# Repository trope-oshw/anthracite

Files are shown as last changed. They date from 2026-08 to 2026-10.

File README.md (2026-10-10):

# Anthracite

A MIDI-controllable analogue fuzz pedal.

Fuzz pedals are awkward to live with: the sound changes when you swap guitars, a
wah in front of one loses its range, and few switchers can drive one. Most of
that traces back to a single cause — the input impedance of a fuzz is low, and
it is fixed. Anthracite lets you choose the load your pickup sees, and keeps the
whole signal path analogue: it is switched by analogue switches rather than
mechanical contacts, and the microcontroller only moves those switches and never
touches the audio.

Designed and built by [Trope](https://trope-oshw.org) (山本回路設計).

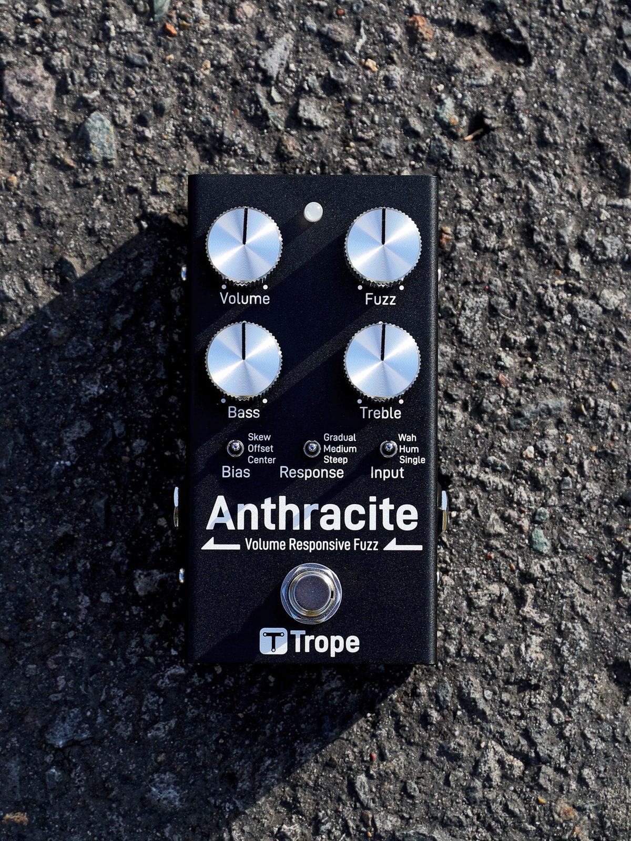
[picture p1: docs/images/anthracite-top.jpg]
Anthracite v1.0 seen from directly above: four aluminium knobs, three toggle switches and a footswitch on a matte black enclosure, with every control label legible


<table>
  <tr>
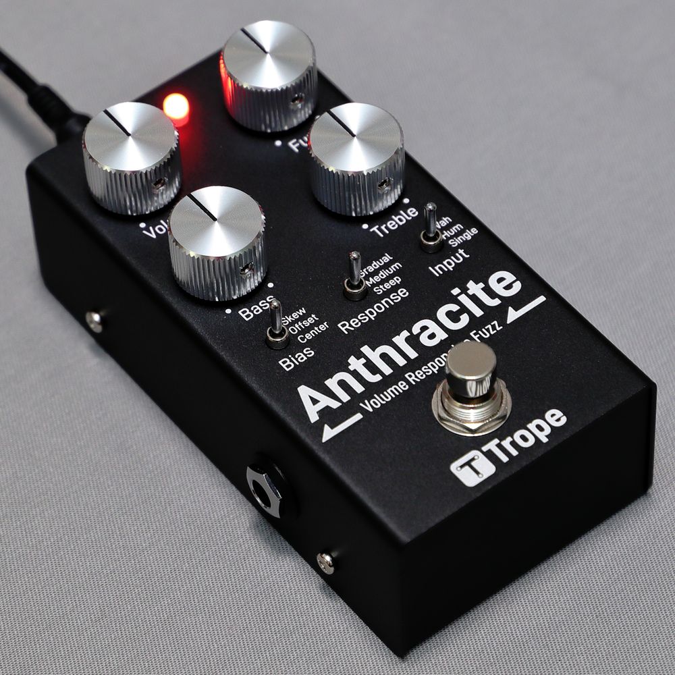
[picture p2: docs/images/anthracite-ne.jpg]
Anthracite v1.0 seen from above at an angle, with the LED lit red and a cable plugged into the top edge
    <td align="center"></td>
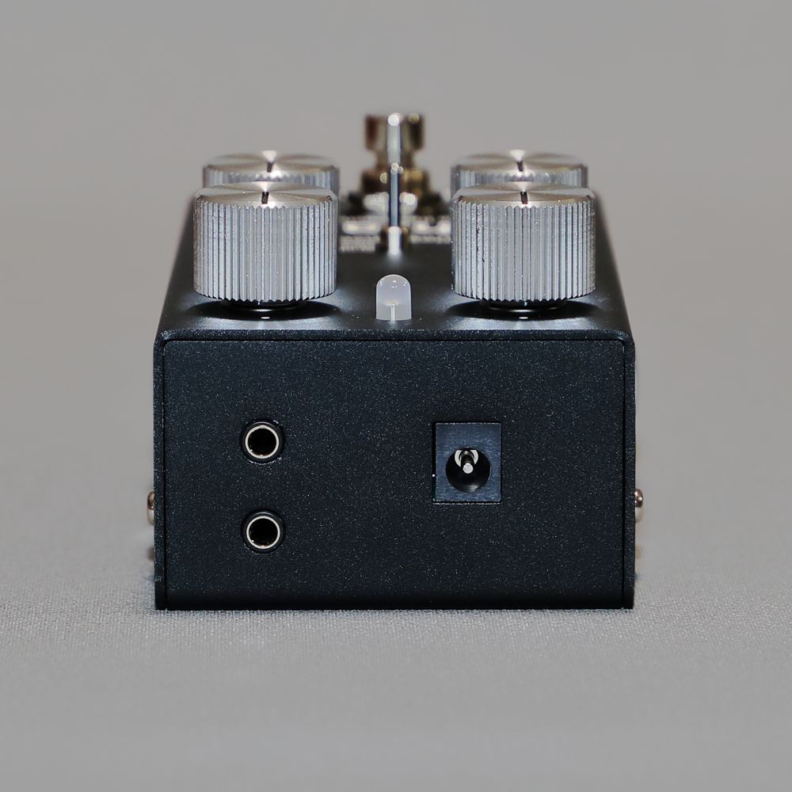
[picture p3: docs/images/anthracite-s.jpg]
The top edge of Anthracite v1.0: two 3.5 mm TRS MIDI jacks on the left and the 9 V DC barrel jack on the right
    <td align="center"></td>
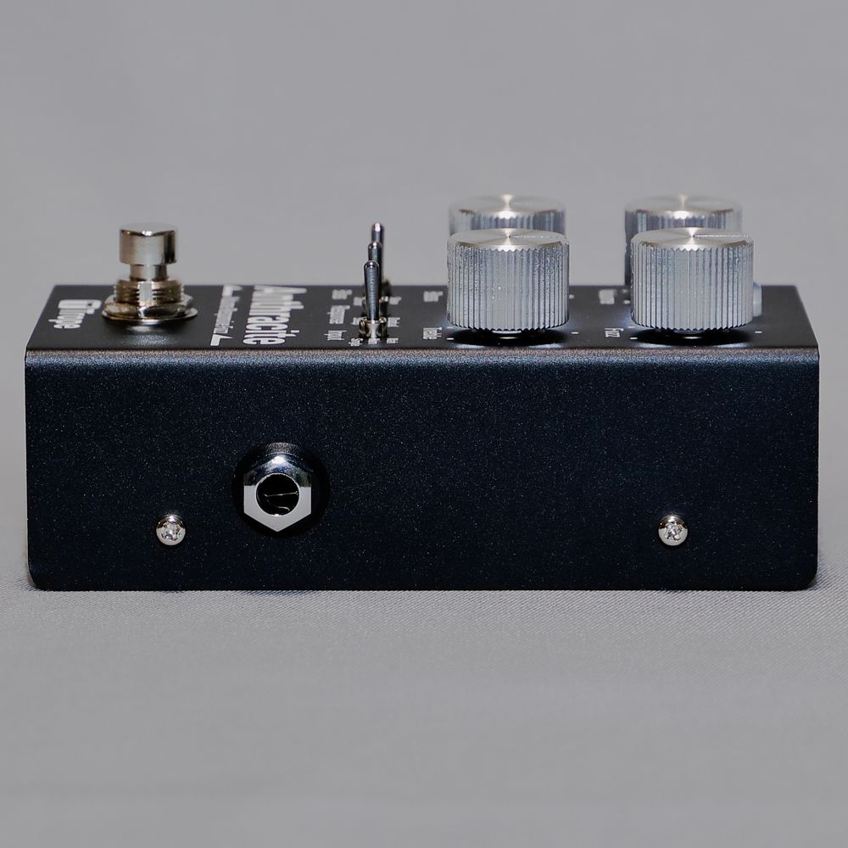
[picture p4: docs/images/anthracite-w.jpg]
The input side of Anthracite v1.0, with the 1/4 inch input jack
    <td align="center"></td>
  </tr>
  <tr>
    <td align="center">Angled view, LED lit</td>
    <td align="center">Top edge: MIDI IN / OUT (3.5 mm TRS) and 9 V DC</td>
    <td align="center">Input side: 1/4" jack</td>
  </tr>
</table>

## Specifications

| | |
|---|---|
| Power | 9 V DC, centre-negative, 5.5 / 2.1 mm barrel. No battery compartment |
| Operating voltage | 8.4 – 11.5 V |
| Recommended operating voltage | 8.6 – 10.0 V |
| Current draw | About **70 mA** at 9 V with the effect on (measured 67 – 74 mA depending on settings; about 4 mA less in bypass) |
| Adapter rating | 200 mA or more |
| Input impedance | About **13 kΩ** (Single) / **24 kΩ** (Hum) / **44 kΩ** (Wah) at 1 kHz, effect on |
| Input impedance, bypassed | About **1 MΩ** from 100 Hz to 1 kHz, measured |
| Output impedance | About **1 kΩ** at 1 kHz |
| Bypass | Buffered. Switched electronically — no mechanical contacts in the audio path |
| MIDI | 3.5 mm TRS, MIDI Type-A, 31250 baud. MIDI IN, and a MIDI OUT (Thru) jack that doubles as an external-switch input |
| Microcontroller | STM32F030C8T6 (Cortex-M0, 48 MHz, LQFP48) |
| Enclosure | 73.5 (W) × 57.5 (H) × 128 (D) mm including knobs and jacks, 268 g |

The pedal monitors its supply and flashes the LED if the voltage drops below
about 8 V or rises above about 12 V. The exact trip points vary slightly from
unit to unit, but the warning does not appear inside the operating voltage
range. Do not run the pedal outside that range even if no warning is shown.

The effect-on input impedance figures come from a SPICE model of the input
circuit and agree with measurements on a v1.0 unit. The impedance stays roughly
flat at low frequencies (about 24 / 34 / 55 kΩ at 20 Hz) and falls gradually
towards high frequencies. That roll-off is deliberate: a heavier load pulls the
pickup's resonant peak lower, and the Input switch selects between three loads.

### Boards

| Board | Size | Layers | Copper |
|---|---|---|---|
| Top (analogue) | 60 × 102 mm | 4 | 35 µm (1 oz) outer, 17.5 µm (0.5 oz) inner |
| Bottom (control) | 60 × 73.5 mm | 4 | 35 µm (1 oz) outer, 17.5 µm (0.5 oz) inner |
| Footswitch | 14 × 16.15 mm | 2 | — |

All boards are 1.6 mm FR-4.

## Controls

Four potentiometers and three three-position toggles.

| Control | Range |
|---|---|
| **Volume** | 50 kΩ, log (A taper) |
| **Fuzz** | 10 kΩ, reverse log (C taper), wired as a variable resistor. Roughly 39 dB to 65 dB of small-signal gain in the fuzz stage |
| **Bass** | 20 kΩ, linear (B taper). Low shelf: up to about −25 dB of cut and +13 dB of boost at 20 Hz. The half-way point moves between about 170 Hz and 390 Hz with the knob |
| **Treble** | 20 kΩ, linear (B taper). High shelf: up to about −26 dB of cut and +14 dB of boost at 10 kHz. The half-way point moves between about 700 Hz and 1.7 kHz, so it also acts on the midrange around 1 kHz |

Toggle positions are listed from top to bottom.

| Toggle | Positions | What it changes |
|---|---|---|
| **Bias** | Skew / Offset / Center | Operating point of the output-side fuzz transistor (3:1, 2:1, 1:1). More asymmetry means more even-order harmonics and less gain. Second harmonic moves from −16.7 dBc (Center) to −9.5 dBc (Skew) at 400 Hz / 0.1 Vpp, Fuzz 50 %. With DIP-SW2 on, the toggle selects X-Skew (4:1) / Skew / Offset instead |
| **Response** | Gradual / Medium / Steep | Series resistance at the fuzz input, which sets how abruptly the pedal cleans up as you roll back the guitar volume. THD at 400 Hz / 1 Vpp, Fuzz 50 %: 65.6 % / 59.7 % / 49.3 % |
| **Input** | Wah / Hum / Single | Input filter, which sets the loading your pickup sees (see the impedance figures above) |

## MIDI

The pedal receives; it never sends control messages of its own. MIDI IN is
active whichever way DIP-SW3 (MIDI mode / external-switch mode) is set.

| CC | Function | Values |
|---|---|---|
| **81** | Bypass / engage (channel 12, with DIP-SW4 off as shipped) | ≥ 64 engages, < 64 bypasses |
| **83** | Input | 0 = return to the physical toggle · 1–31 Single · 32–63 Hum · 64–95 Wah · 96–127 All-OFF (input filter disconnected) |
| **84** | Response | 0 = return to the toggle · 1–31 Steep · 32–63 Medium · 64–95 Gradual · 96–127 no change |
| **85** | Bias | 0 = return to the toggle · 1–31 Center · 32–63 Offset · 64–95 Skew · 96–127 X-Skew |

CC 83/84/85 are received on the same channel as the bypass / engage message.
Sending 0 to any of them hands control back to the physical toggle, so a MIDI
override never becomes something you cannot undo from the panel.

**MIDI-Learn** stores a channel and CC number for the bypass function in EEPROM;
with DIP-SW4 on, the pedal uses them instead of channel 12 / CC 81. Units ship
with **channel 6 / CC 1** already stored. Many MIDI foot controllers send their
expression pedal on CC 1, so with DIP-SW4 on, an expression pedal on channel 6
will switch the effect as it crosses value 64; learn a different CC or change
the controller's CC. If nothing is stored, DIP-SW4 on disables MIDI control
entirely rather than falling back to channel 12 / CC 81. Do not learn CC 83, 84
or 85. **Active Sensing** (0xFE) is emitted about every 250 ms, and received
messages are passed through to MIDI OUT unmodified, both only in MIDI mode
(DIP-SW3 on, as shipped). With DIP-SW3 off, the MIDI OUT jack becomes an
external footswitch input.

## What is in this repository

```
hardware/     KiCad projects for the three circuit boards (top, bottom and
              footswitch) and the front-panel artwork, with the symbol and
              footprint libraries they use; parts list (parts.md)
enclosure/    Enclosure 3D model (STEP), hole-layout and assembly drawings
              (PDF), front-panel artwork for laser marking (DXF, SVG, PNG)
firmware/     STM32 firmware source: STM32CubeMX project, CMake build, the
              ST HAL and CMSIS, and the build and flashing guide
docs/         Schematics (PDF, plus a PNG of each sheet), bills of materials
              (CSV), 3D models of the assembled boards (STEP), product photos
```

The STEP model and the drawings (PDF, DXF) are the reference for the
enclosure.

Gerbers and the ordering notes are attached to each
[release](https://github.com/trope-oshw/anthracite/releases) rather than kept in
the tree, so that what you download always matches a specific version. There is
no assembler-specific BOM or pick-and-place file: build them from `docs/bom-*.csv`
and the KiCad projects for whoever assembles your boards.

The user manual, measured data, and circuit explanations live at
**https://docs.trope-oshw.org** — they are not duplicated here.

## Building the boards

The KiCad projects need KiCad 10 or later. They are self-contained: every
custom symbol and footprint is in the project's own `libs/` directory, so you
can clone this repository and open them without installing anything else.

[`hardware/parts.md`](hardware/parts.md) lists the parts chosen for each board,
with manufacturer part numbers and LCSC numbers.

Ordering parameters used for the production run are recorded in
`ordering-notes.md` attached to each release. They matter, because a different
stackup or copper weight gives a different board.

## Firmware

The full source is in [`firmware/`](firmware/). Built as described in
[firmware/README.md](firmware/README.md), it reproduces the image on shipped
units byte for byte; that file gives the toolchain versions, the SHA-256 of the
image, and how to write it to a finished unit. You do not need to touch the
firmware to use the pedal; the instructions are there because being able to
replace the software on hardware you own is part of what this licence is for.

## Licensing

| What | Licence |
|---|---|
| Hardware (`hardware/`, `enclosure/`) | **CERN-OHL-S-2.0** |
| Firmware (`firmware/`), except the third-party code below | **GPL-3.0-or-later** |
| Generated design documents (`docs/`: schematics, bills of materials, board 3D) | **CERN-OHL-S-2.0** |
| Product photographs (`docs/images/`) | **CC-BY-SA-4.0** |
| Text (this README, CHANGELOG, ERRATA, CONTRIBUTING) | **CC-BY-SA-4.0** |

Full texts are in [`LICENSES/`](LICENSES/); per-file assignments are declared in
[`REUSE.toml`](REUSE.toml) following the [REUSE](https://reuse.software/)
specification. See [`COPYRIGHT.txt`](COPYRIGHT.txt) for the notices.

Parts of the firmware come from STMicroelectronics and Arm and keep their own
licences: the STM32F0 HAL driver and the code generated by STM32CubeMX are
BSD-3-Clause, and the CMSIS headers and ST's CMSIS device files are Apache-2.0.
Likewise, some footprints in `hardware/*/libs/` are derived from the KiCad
standard libraries and stay under CC-BY-SA-4.0 with the KiCad libraries
exception. The symbol libraries mix symbols derived the same way with symbols
drawn for this project, so both licences apply to them; `REUSE.toml` lists the
files.

## Trademark

The design files in this repository are open source under the licences above.
**The Trope and 山本回路設計 brand names, the Trope logo, and the product name
"Anthracite" are not.** They are trademarks of 山本回路設計 and are not licensed
to you by any of the licences here. See also section 8.2 of the CERN-OHL-S v2.

You are free to build, modify, and sell hardware derived from these files. When
you do, please give it your own name and your own branding. A modified version
could be called "Foobar Audio — Charcoal Fuzz"; it should not be called
"Anthracite" or "Trope Anthracite".

You may state truthfully that your product is *based on the Anthracite design by
Trope*. You may not use the Trope logo, or a name so close to Trope or Anthracite
that a buyer could confuse the two.

**All Trope branding has been removed from the published files**, both the
panel artwork and the circuit-board silkscreen, so hardware made from these
files carries no Trope marks by default. Please keep it that way. Instead of a
product name, the top and bottom boards carry the board version (`V1.0`), the
licence (CERN-OHL-S-2.0) and where the source lives
(`github.com/trope-oshw/anthracite`).

Boards from the first production run carry `Anthracite V1.0` on the silkscreen
instead. That text is the only difference: electrically they are the same as the
published boards. Units built by Trope after that run use the published board
files as they are.

Questions, or a request to use the marks: trope.oshw@gmail.com — ask first and
the answer is almost always yes.

## Versions

The product and the boards carry a `vMAJOR.MINOR` number, silkscreened on the
PCB. The firmware carries its own semantic version. They move independently:
fixing a firmware bug does not change the boards, so the board version stays put.

See [CHANGELOG.md](CHANGELOG.md) for what changed in each release, and
[ERRATA.md](ERRATA.md) for problems found in hardware that has already been
built. **If your unit behaves differently from this documentation, check the
errata first.**

## Buying one

Anthracite is on sale. Trope builds and tests each unit and ships it with its
own test report. The product page at **https://trope-oshw.org/anthracite/**
shows the current price and takes orders. Trope plans to publish the cost
breakdown and the formula behind the price at **https://docs.trope-oshw.org**.
Questions go to trope.oshw@gmail.com.

Buying one is what pays for the next design being opened.

## Contributing

Issues are welcome; pull requests to the hardware are not, for reasons explained
in [CONTRIBUTING.md](CONTRIBUTING.md). Firmware and documentation PRs are
welcome.

## Disclaimer

This design is distributed **as-is, with no warranty of any kind**, express or
implied, including merchantability and fitness for a particular purpose. See
sections 6.1 and 6.2 of the CERN-OHL-S v2 for the full disclaimer.

If you build, modify, or sell hardware based on these files, **you are the
manufacturer** of that hardware. You alone are responsible for its safety and
for its compliance with every regulation that applies where you place it on the
market. Any certification, testing, or conformity marking obtained by
山本回路設計 applies **only to units built and sold by 山本回路設計**, and does
not transfer to your build.

Use a regulated, correctly-polarised 9 V DC supply. Incorrect power can damage
the pedal and whatever is connected to it.

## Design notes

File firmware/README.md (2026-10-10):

# Anthracite firmware

Firmware for the STM32F030C8T6 on the control board. It reads the panel
toggles, the footswitch and MIDI, and drives the analogue switches and the
LEDs. The audio signal never passes through the microcontroller.

This tree is firmware 1.0.0, the version on shipped v1.0 units.

## Why these instructions exist

This firmware is licensed under **GPL-3.0-or-later**. That licence asks that if
you receive a device with GPL software on it, you are able to replace that
software with your own modified version. Trope documents the procedure here
and leaves the SWD header on shipped units accessible and unlocked.

You do not need any of this to use the pedal.

## What is here

| Path | Contents |
|---|---|
| `Src/main.c`, `Src/stm32f0xx_it.c`, `Inc/main.h` | The application, written inside the STM32CubeMX skeleton |
| `Src/`, `Inc/` (other files) | Startup support, HAL configuration and MSP code generated by STM32CubeMX |
| `Drivers/` | STM32F0 HAL driver and CMSIS headers from STM32Cube FW_F0 V1.11.6 |
| `anthracite.ioc` | STM32CubeMX project: pin assignment, clocks, peripherals |
| `CMakeLists.txt`, `CMakePresets.json`, `cmake/` | CMake build generated by STM32CubeMX |
| `STM32F030XX_FLASH.ld`, `startup_stm32f030x8.s` | Linker script and startup code |

The presets use `cmake/gcc-arm-none-eabi.cmake`. STM32CubeMX also generated
`cmake/starm-clang.cmake`; the build does not use it.

## What you need

| | |
|---|---|
| Probe | ST-LINK/V3 (V3MINIE or similar) with SWD |
| Build | CMake 3.22 or later, Ninja, the GNU Arm toolchain (`arm-none-eabi-gcc`) |
| Flashing | `STM32_Programmer_CLI` (or OpenOCD) |

STM32CubeIDE ships CMake, Ninja, the GNU toolchain and `STM32_Programmer_CLI`
in `STM32CubeIDE/plugins/com.st.stm32cube.ide.mcu.externaltools.*/tools/bin`.
With those directories on `PATH`, you have every tool the build and flashing
steps use.

## Building

Run these commands in the `firmware/` directory, where `CMakePresets.json` is:

```sh
cmake --preset Debug
cmake --build --preset Debug
```

The ELF is `build/Debug/anthracite.elf`.

Use the presets. A hand-written `cmake -S . -B build -G Ninja …` command omits
`-DCMAKE_TOOLCHAIN_FILE`, and the configure step fails.

On Windows, CMake warns when object file paths approach 250 characters. Clone
the repository to a short path if you see that warning.

## Reproducing the shipped image

Shipped units carry the `Debug` build (`-O0 -g3`) of this source. Built with
the tools below, the `Debug` preset reproduces that image byte for byte:

| Tool | Version |
|---|---|
| GNU toolchain | GNU Tools for STM32 14.3.rel1.20251027-0700 (GCC 14.3.1), bundled with STM32CubeIDE 2.1.0 |
| CMake | 3.28.1 |
| Ninja | 1.11.1 |

```sh
arm-none-eabi-objcopy -O binary build/Debug/anthracite.elf anthracite.bin
sha256sum anthracite.bin        # Linux, Git Bash
shasum -a 256 anthracite.bin    # macOS
```

In PowerShell, `Get-FileHash -Algorithm SHA256 anthracite.bin` prints the same
hash in upper case.

The flash image is 42,516 bytes, loaded at `0x08000000`, with SHA-256

```
b7581d1ae76084e6236442fdeab6e39d7fa7e3c6bd3c1cf8cb9a229a08162016
```

Compare the `.bin`. The ELF also holds debug information with line
numbers and file paths, so it changes when comments move or the tree sits in a
different directory, while the flash image stays the same. A different
compiler version can produce a different image.

`CMakePresets.json` also defines a `Release` preset (`-Os -g0`). It produces a
different image from the one on shipped units.

## Flashing

The SWD header is **J101**, a 14-pin STDC14 connector (2×7, 1.27 mm pitch) on
the control board. Pins 3/4/5/6/12 carry 3V3, SWDIO, GND, SWCLK and NRST; pins
13/14 are a serial console.

```sh
# Check the probe sees the target
STM32_Programmer_CLI -c port=SWD

# Write, verify, reset
STM32_Programmer_CLI -c port=SWD freq=4000 -w build/Debug/anthracite.elf -v -rst
```

The ELF carries its load address, so no address argument is needed. With OpenOCD:

```sh
openocd -f interface/stlink.cfg -f target/stm32f0x.cfg \
        -c "program build/Debug/anthracite.elf verify reset exit"
```

Trope programmed shipped units with STM32_Programmer_CLI 2.22.0.

If `STM32_Programmer_CLI` reports no ST-LINK, close any CubeIDE debug session
first: it holds the ST-LINK open. With more than one probe attached, select one
with `sn=<serial>`.

## Licences

| Files | Licence |
|---|---|
| `Src/main.c`, `Src/stm32f0xx_it.c`, `Inc/main.h` | GPL-3.0-or-later. The parts STM32CubeMX generated stay BSD-3-Clause (STMicroelectronics) |
| `anthracite.ioc` | GPL-3.0-or-later |
| `Drivers/STM32F0xx_HAL_Driver/` | BSD-3-Clause (STMicroelectronics) |
| Other files generated by STM32CubeMX: `Src/stm32f0xx_hal_msp.c`, `Src/syscalls.c`, `Src/sysmem.c`, `Inc/stm32f0xx_hal_conf.h`, `Inc/stm32f0xx_it.h`, `STM32F030XX_FLASH.ld`, `CMakeLists.txt`, `CMakePresets.json`, `cmake/`, `.mxproject` | BSD-3-Clause (STMicroelectronics) |
| `Drivers/CMSIS/Device/`, `Src/system_stm32f0xx.c`, `startup_stm32f030x8.s` | Apache-2.0 (STMicroelectronics) |
| `Drivers/CMSIS/Include/` | Apache-2.0 (Arm; `cmsis_iccarm.h` by IAR Systems) |

Most of the third-party files carry no SPDX header. The repository's
`REUSE.toml` declares their licences, and the texts are in `LICENSES/`.

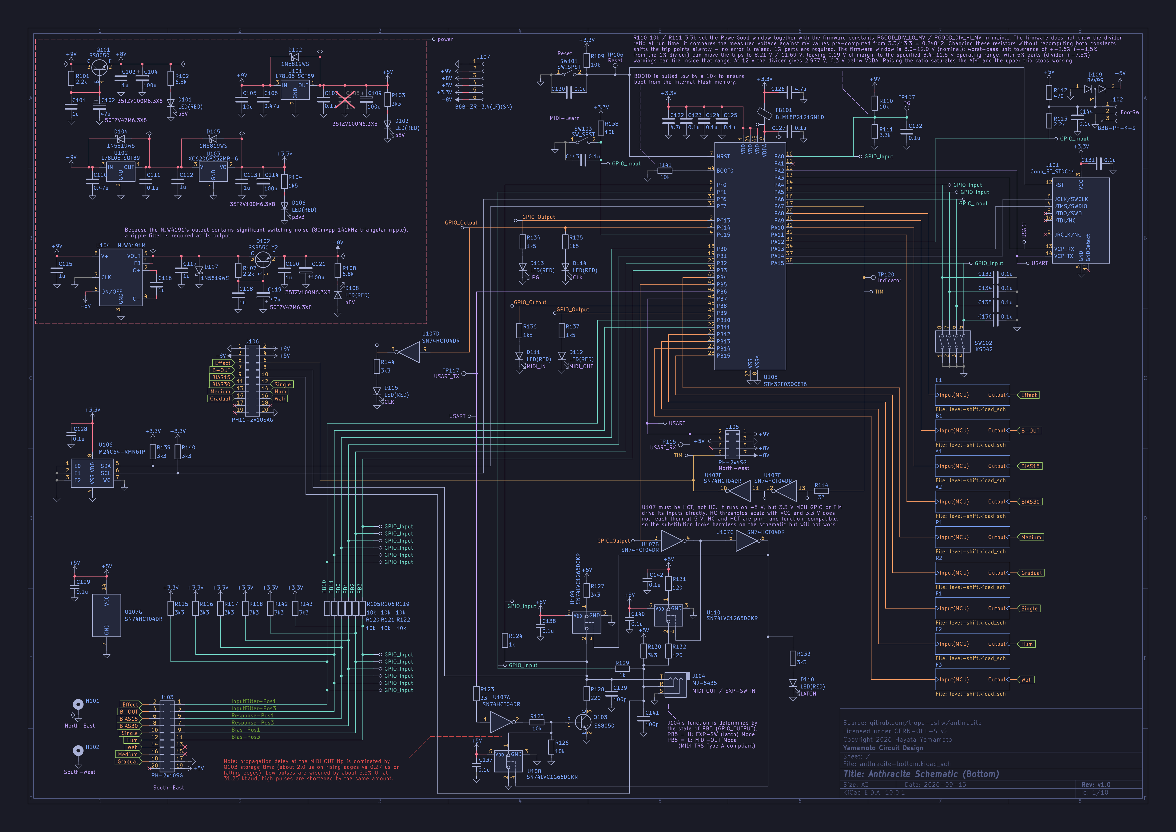
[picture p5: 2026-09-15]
docs/schematics/anthracite-bottom.png

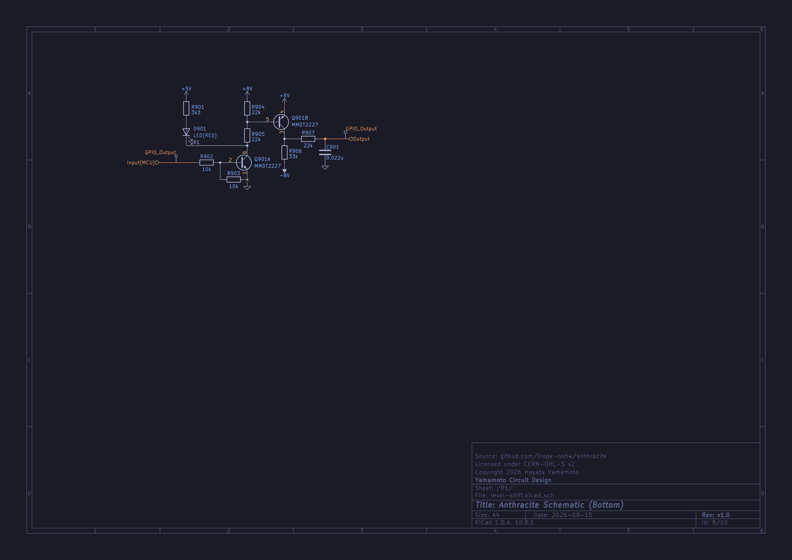
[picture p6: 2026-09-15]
docs/schematics/anthracite-bottom-R1.png

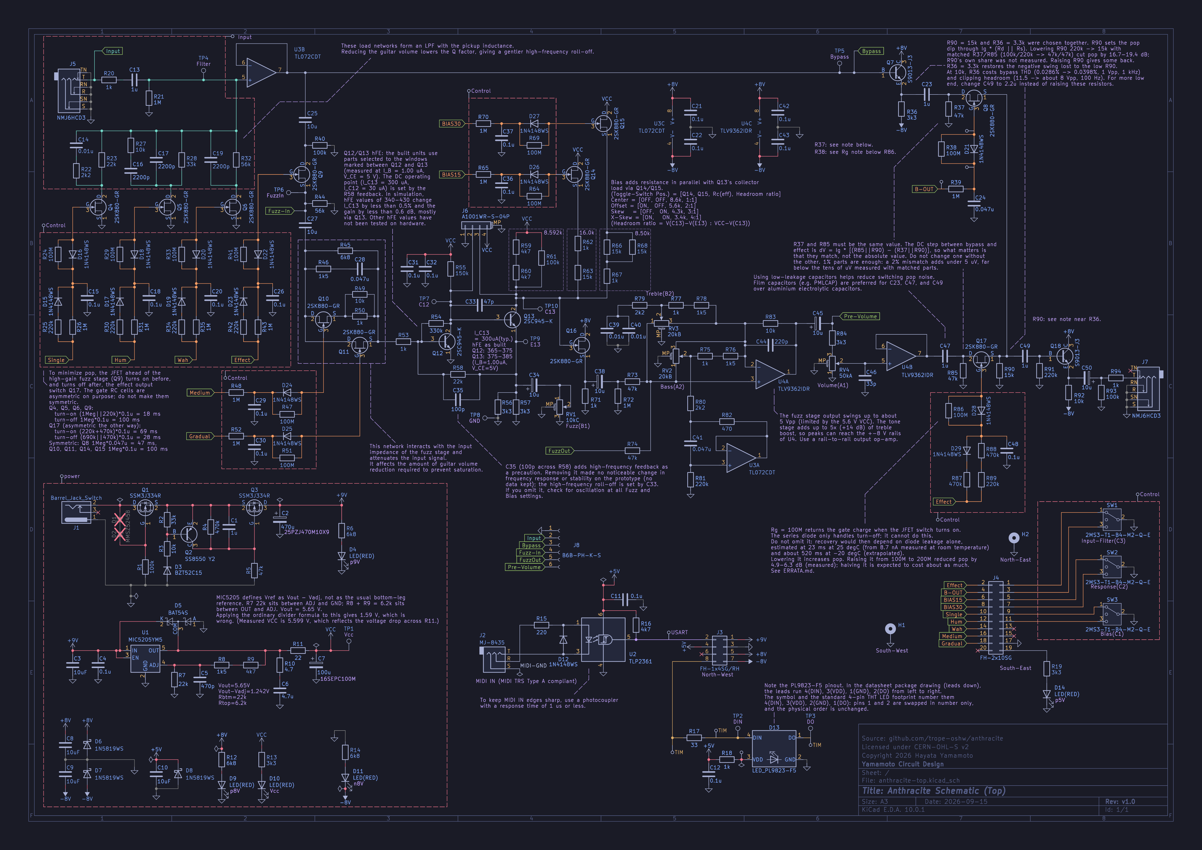
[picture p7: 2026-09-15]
docs/schematics/anthracite-top.png

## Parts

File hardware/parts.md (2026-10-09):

# Parts

The parts chosen for Anthracite v1.0, collected from the bills of materials in
`docs/`. Positions, quantities and the full field list for each board are in
`docs/bom-top.csv`, `docs/bom-bottom.csv`, `docs/bom-footswitch.csv` and
`docs/bom-mechanical.csv`. KiCad exports the board BOMs from the projects;
Trope wrote this file by hand from them. If the two disagree, follow the BOM.

**Fit:** on the first production run the board house assembled the `SMT` parts
(`PCBA` in the BOM) and Trope hand-soldered the `Hand` parts. `DNP` parts stay
off the board.

**LCSC** numbers are the ones in the BOMs. Stock and catalogue numbers change,
so check them before ordering; the manufacturer and MPN are there to choose an
equivalent part.

## Parts with a manufacturer part number

### Integrated circuits

| Value | Manufacturer | MPN | LCSC | Rating | Fit | Used on |
|---|---|---|---|---|---|---|
| MIC5205YM5 | Microchip | MIC5205YM5 | C412820 |  | SMT | Top: U1 |
| TL072CDT | STMicro | TL072CDT | C6961 |  | SMT | Top: U3 |
| TLP2361 | Toshiba | TLP2361 | C107626 |  | Hand | Top: U2 |
| TLV9362IDR | TI | TLV9362IDR | C4367884 |  | Hand | Top: U4 |
| L78L05_SOT89 | UTC | 78L05G-AB3-R | C71136 |  | SMT | Bottom: U101, U102 |
| XC6206P332MR-G | Torex | XC6206P332MR-G | C5446 |  | SMT | Bottom: U103 |
| STM32F030C8T6 | STMicro | STM32F030C8T6 | C23922 |  | SMT | Bottom: U105 |
| M24C64-RMN6TP | STMicro | M24C64-RMN6TP | C79988 |  | SMT | Bottom: U106 |
| SN74HCT04DR | TI | SN74HCT04DR | C6766 |  | SMT | Bottom: U107 |
| SN74LVC1G66DCKR | TI | SN74LVC1G66DCKR | C113518 |  | SMT | Bottom: U108, U109, U110 |
| NJW4191M | Nisshinbo | NJW4191M |  |  | Hand | Bottom: U104 |

### Transistors

| Value | Manufacturer | MPN | LCSC | Rating | Fit | Used on |
|---|---|---|---|---|---|---|
| SS8550 Y2 | JSCJ | SS8550 Y2(RANGE:200-350) | C8542 |  | SMT | Top: Q2; Bottom: Q102 |
| 2SK880-GR | Toshiba | 2SK880-GR | C7469759 |  | SMT | Top: Q4, Q5, Q6, Q8, Q9, Q10, Q11, Q14, Q15, Q16, Q17 |
| S9013-J3 | JSCJ | S9013 J3(RANGE:200-350) | C6749 |  | SMT | Top: Q7, Q18 |
| SSM3J334R | Toshiba | SSM3J334R | C396017 |  | Hand | Top: Q1, Q3 |
| 2SC945-K | UTC | 2SC945-K |  |  | Hand | Top: Q12, Q13 |
| SS8050 | JSCJ | SS8050(RANGE:200-350) | C2150 |  | SMT | Bottom: Q101, Q103 |
| MMDT2227 | R+O | MMDT2227 | C41375117 |  | SMT | Bottom: Q201, Q301, Q401, Q501, Q601, Q701, Q801, Q901, Q1001 |

### Diodes and LEDs

| Value | Manufacturer | MPN | LCSC | Rating | Fit | Used on |
|---|---|---|---|---|---|---|
| BZT52C15 | R+O | BZT52C15 | C19077412 |  | SMT | Top: D3 |
| LED(RED) | Hubei KENTO Elec | KT-0603R | C2286 |  | SMT | Top: D4, D9, D10, D11, D14; Bottom: D101, D103, D106, D108, D110, D111, D112, D113, D114, D115, D201, D301, D401, D501, D601, D701, D801, D901, D1001 |
| BAT54S | R+O | BAT54S | C7420333 |  | SMT | Top: D5 |
| 1N5819WS | Guangdong Hottech | 1N5819WS | C191023 |  | SMT | Top: D6, D7, D8; Bottom: D102, D104, D105, D107 |
| 1N4148WS | JSCJ | 1N4148WS | C2128 |  | SMT | Top: D12, D15, D16, D17, D18, D19, D20, D21, D22, D23, D24, D25, D26, D27, D28, D29 |
| LED_PL9823-F5 | Shenzhen Rita Lighting | PL9823-F5 |  |  | Hand | Top: D13 |
| MMSZ5245B | R+O | MMSZ5245B | C19077428 |  | DNP | Top: D1, D2 |
| BAV99 | Nexperia | BAV99,215 | C2500 |  | SMT | Bottom: D109 |

### Capacitors with a specified part

| Value | Manufacturer | MPN | LCSC | Rating | Fit | Used on |
|---|---|---|---|---|---|---|
| 1u | Samsung Electro-Mechanics | CL21B105KBFNNNE | C28323 | 10% 50V X7R | SMT | Top: C1; Bottom: C101, C103, C112, C113, C115, C116, C117, C118, C120 |
| 10uF | Samsung Electro-Mechanics | CL21A106KAYNNNE | C15850 | 10% 25V X5R | SMT | Top: C3, C8, C9, C10 |
| 0.01u | Murata | GRM1885C1H103JA01D | C85973 | 5% 50V C0G | SMT | Top: C14, C39, C40 |
| 10u | Panasonic | EEE1CA100SR | C178496 | 20% 16V electrolytic | SMT | Top: C34, C38, C45, C50 |
| 470u | Rubycon | 25PZJ470M10X9 |  | 20% 25V Polymer electrolytic | Hand | Top: C2 |
| 100u | Panasonic | 16SEPC100M |  | 20% 16V Polymer electrolytic | Hand | Top: C7 |
| 1u | Rubycon | 25NS105MA23216 |  | 20% 25V film | Hand | Top: C13, C23, C47, C49 |
| 10u | Rubycon | 16MU106MC44532 |  | 20% 16V film | Hand | Top: C25, C27 |
| 0.047u | Murata | GRM31M5C1H473JA01L | C21812 | 5% 50V C0G | Hand | Top: C28, C41 |
| 47u | Rubycon | 50TZV47M6.3X8 | C88734 | 20% 50V electrolytic | SMT | Bottom: C102, C119 |
| 100u | Rubycon | 35TZV100M6.3X8 | C88744 | 20% 35V electrolytic | SMT | Bottom: C104, C109, C114, C121 |
| 10u | Murata | GRM21BR61H106KE43L | C440198 | 10% 50V X5R | DNP | Bottom: C108 |

### Connectors

| Value | Manufacturer | MPN | LCSC | Rating | Fit | Used on |
|---|---|---|---|---|---|---|
| Barrel_Jack_Switch | Maru-Shin | MJ-179PH |  |  | Hand | Top: J1 |
| MJ-8435 | Maru-Shin | MJ-8435 |  |  | Hand | Top: J2; Bottom: J104 |
| FH-1x4SG/RH | Chang Enn | FH-1x4SG/RH x2 |  |  | Hand | Top: J3 |
| FH-2x10SG | Chang Enn | FH-2x10SG |  |  | Hand | Top: J4 |
| NMJ6HCD3 | Neutrik | NMJ6HCD3 |  |  | Hand | Top: J5, J7 |
| A1001WR-S-04P | Herwell | A1001WR-S-04P |  |  | Hand | Top: J6 |
| B6B-PH-K-S | JST | B6B-PH-K-S(LF)(SN) |  |  | Hand | Top: J8 |
| Conn_ST_STDC14 | hanxia | HX JN1.27-2x7P ZZ H4.9 |  |  | Hand | Bottom: J101 |
| B3B-PH-K-S | JST | B3B-PH-K-S(LF)(SN) |  |  | Hand | Bottom: J102 |
| PH-2x10SG | Useconn | PH-2x10SG |  |  | Hand | Bottom: J103 |
| PH-2x4SG | Chang Enn | PH-2x4SG |  |  | Hand | Bottom: J105 |
| PH11-2x10SAG | Chang Enn | PH11-2x10SAG |  |  | Hand | Bottom: J106 |
| B6B-ZR-3.4(LF)(SN) | JST | B6B-ZR-3.4(LF)(SN) |  |  | Hand | Bottom: J107 |
| Conn_01x03_Socket | JST | B3B-PH-K-S(LF)(SN) |  |  | Hand | Footswitch: J1 |

### Switches and potentiometers

| Value | Manufacturer | MPN | LCSC | Rating | Fit | Used on |
|---|---|---|---|---|---|---|
| 10kC | Alpha | RD901F-40-15R1-C10K |  |  | Hand | Top: RV1 |
| 20kB | Alpha | RD901F-40-15R1-B20K |  |  | Hand | Top: RV2, RV3 |
| 50kA | Alpha | RD901F-40-15R1-A50K |  |  | Hand | Top: RV4 |
| 2MS3-T1-B4-M2-Q-E | Cosland | 2MS3-T1-B4-M2-Q-E |  |  | Hand | Top: SW1, SW2, SW3 |
| SW_SPST | XUNPU | TS-1088-AR02016 | C720477 |  | SMT | Bottom: SW101, SW103 |
| KSD42 | OTAX | KSD42 |  |  | Hand | Bottom: SW102 |
| SW_DPDT_x2 | Alpha | See note 2 |  |  | Hand | Footswitch: SW1 |

## Generic resistors and capacitors

The remaining resistors and ceramic capacitors are generic chip parts, listed
in the BOMs by value, package, tolerance, voltage, dielectric and LCSC number:

- Resistors: 1 % chip resistors, 0603 on the top board and 0402 or
  0603 on the bottom board. The 100 MΩ resistors on the top board (R24, R29,
  R33, R38, R41, R47, R51, R64, R69, R86) are 5 %.
- Ceramic capacitors: X7R, X5R or C0G, 0603 or 0805, as given in the BOMs.
- FB101 on the bottom board is a BLM18PG121SN1D ferrite bead (LCSC C14709).

## Notes

1. **D1, D2** (top) and **C108** (bottom) are not fitted.
2. **Footswitch SW1:** any momentary footswitch works; both poles are wired in
   parallel. Trope's units use an Alpha momentary DPDT footswitch (for
   example Sakuraya Denkiten fs85_i-5).
3. **J3** (top) is made of two FH-1x4SG/RH single-row sockets.
4. **R38 and R86** are 100 MΩ. [ERRATA.md](../ERRATA.md), entry M-1, describes
   raising both to 200 MΩ to reduce the switching pop.
5. **Footswitch cable** (bottom J102 to footswitch J1): a 3-pin, 2.0 mm pitch
   cable, JST PH compatible, 150 mm. The intended part is a made-to-order
   JST PH cable; the first production run used Akizuki Denshi 111659
   (Herwell GP2A-2-B) instead.

## Mechanical parts

From `docs/bom-mechanical.csv`, which also gives supplier part numbers and
links.

| Item | Qty | Part |
|---|---|---|
| Enclosure, top shell | 1 | Sheet-metal U-shell, aluminium 5052, 1.5 mm, anodized black glossy, laser-marked top face. Made to order from `enclosure/` |
| Enclosure, bottom shell | 1 | Sheet-metal U-shell with 4 tapped tabs (M3×0.5 burring), aluminium 5052, 1.5 mm, anodized black glossy. Made to order from `enclosure/` |
| Enclosure screw | 4 | Pan head machine screw, M3×5, brass |
| PCB spacer | 2 | Hex spacer, female-female, M3×0.5, 11 mm, 5.5 mm across flats, brass (M.Y.G FB3-11) |
| PCB spacer screw | 4 | Pan head machine screw, M3×5, brass (same as the enclosure screws) |
| Knob | 4 | Aluminium knob, Davies 1510 style, silver, 19 mm dia., 6.35 mm round shaft hole, set screw |
| Footswitch cable | 1 | See note 5 |

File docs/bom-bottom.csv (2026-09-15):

Assembly | References | Qty | Value | Footprint | Description | Tolerance | Voltage | Dielectric | Power | Manufacturer | MPN | LCSC | Datasheet
PCBA | C101, C103, C112, C113, C115, C116, C117, C118, C120 | 9 | 1u | C_0805_2012Metric | Unpolarized capacitor | 10% | 50V | X7R |  | Samsung Electro-Mechanics | CL21B105KBFNNNE | C28323
PCBA | C102, C119 | 2 | 47u | CP_Rubycon_35TZV100M6.3X8 | Polarized capacitor | 20% | 50V | electrolytic |  | Rubycon | 50TZV47M6.3X8 | C88734
PCBA | C104, C109, C114, C121 | 4 | 100u | CP_Rubycon_35TZV100M6.3X8 | Polarized capacitor | 20% | 35V | electrolytic |  | Rubycon | 35TZV100M6.3X8 | C88744
PCBA | C105 | 1 | 10u | C_0805_2012Metric | Unpolarized capacitor | 10% | 25V | X5R |  |  |  | C15850
PCBA | C106, C110 | 2 | 0.47u | C_0603_1608Metric | Unpolarized capacitor | 10% | 25V | X7R |  |  |  | C1623
PCBA | C107, C111 | 2 | 0.1u | C_0805_2012Metric | Unpolarized capacitor | 10% | 50V | X7R |  |  |  | C49678
PCBA | C122, C126 | 2 | 4.7u | C_0805_2012Metric | Unpolarized capacitor | 10% | 25V | X5R |  |  |  | C1779
PCBA | C123, C124, C125, C127, C128, C129, C130, C131, C132, C133, C134, C135, C136, C137, C138, C140, C142, C143, C144 | 19 | 0.1u | C_0603_1608Metric | Unpolarized capacitor | 10% | 50V | X7R |  |  |  | C14663
PCBA | C139, C141 | 2 | 100p | C_0603_1608Metric | Unpolarized capacitor | 5% | 50V | C0G |  |  |  | C14858
PCBA | C201, C301, C401, C501, C601, C701, C801, C901, C1001 | 9 | 0.022u | C_0603_1608Metric | Unpolarized capacitor | 10% | 50V | X7R |  |  |  | C21122
PCBA | D101, D103, D106, D108, D110, D111, D112, D113, D114, D115, D201, D301, D401, D501, D601, D701, D801, D901, D1001 | 19 | LED(RED) | D_0603_1608Metric_Name | Light emitting diode |  |  |  |  | Hubei KENTO Elec | KT-0603R | C2286
PCBA | D102, D104, D105, D107 | 4 | 1N5819WS | D_SOD-323 | 40V 600mV@1A 1A SOD-323 Schottky Barrier Diodes, SOD-323 |  |  |  |  | Guangdong Hottech | 1N5819WS | C191023 | https://datasheet.lcsc.com/lcsc/2204281430_Guangdong-Hottech-1N5819WS_C191023.pdf
PCBA | D109 | 1 | BAV99 | SOT-23 | BAV99 High-speed switching diodes, SOT-23 |  |  |  |  | Nexperia | BAV99,215 | C2500 | https://assets.nexperia.com/documents/data-sheet/BAV99_SER.pdf
PCBA | FB101 | 1 | BLM18PG121SN1D | L_0603_1608Metric | Ferrite bead | 25% |  |  |  |  |  | C14709
PCBA | Q101, Q103 | 2 | SS8050 | SOT-23 | NPN BJT |  |  |  |  | JSCJ | SS8050(RANGE:200-350) | C2150 | https://www.lcsc.com/datasheet/lcsc_datasheet_2303221100_Jiangsu-Changjing-Electronics-Technology-Co---Ltd--SS8050-RANGE-200-350_C2150.pdf
PCBA | Q102 | 1 | SS8550 Y2 | SOT-23 | PNP BJT |  |  |  |  | JSCJ | SS8550 Y2(RANGE:200-350) | C8542 | https://www.lcsc.com/datasheet/lcsc_datasheet_1810161212_Jiangsu-Changjing-Electronics-Technology-Co---Ltd--SS8550-Y2-RANGE-200-350_C8542.pdf
PCBA | Q201, Q301, Q401, Q501, Q601, Q701, Q801, Q901, Q1001 | 9 | MMDT2227 | SOT-363_SC-70-6 | Dual NPN/PNP transistor, 6 pin package. NPN[C, B, E]=[6, 2, 1]. PNP[C, B, E]=[3, 5, 4]. |  |  |  |  | R+O | MMDT2227 | C41375117 | https://fscdn.rohm.com/jp/products/databook/datasheet/discrete/transistor/bipolar/umz1ntr-j.pdf
PCBA | R101, R107, R113 | 3 | 2.2k | R_0603_1608Metric | Resistor | 1% |  |  |  |  |  | C4190
PCBA | R102, R108 | 2 | 6.8k | R_0603_1608Metric | Resistor | 1% |  |  |  |  |  | C23212
PCBA | R103, R133, R144 | 3 | 3k3 | R_0402_1005Metric | Resistor | 1% |  |  |  |  |  | C25890 | https://jlcpcb.com/partdetail/C25890
PCBA | R104, R134, R135, R136, R137 | 5 | 1k5 | R_0402_1005Metric | Resistor | 1% |  |  |  |  |  | C25867 | https://jlcpcb.com/partdetail/C25867
PCBA | R105, R106, R109, R119, R120, R121, R122, R125, R126, R138, R141, R202, R203, R302, R303, R402, R403, R502, R503, R602, R603, R702, R703, R802, R803, R902, R903, R1002, R1003 | 29 | 10k | R_0402_1005Metric_MiniFont | Resistor | 1% |  |  |  |  |  | C25744 | https://jlcpcb.com/partdetail/C25744
PCBA | R110 | 1 | 10k | R_0603_1608Metric | Resistor | 1% |  |  |  |  |  | C25804
PCBA | R111 | 1 | 3.3k | R_0603_1608Metric | Resistor | 1% |  |  |  |  |  | C22978
PCBA | R112 | 1 | 470 | R_0603_1608Metric | Resistor | 1% |  |  |  |  |  | C23179
PCBA | R114, R123 | 2 | 33 | R_0402_1005Metric_MiniFont | Resistor | 1% |  |  |  |  |  | C25105 | https://jlcpcb.com/partdetail/C25105
PCBA | R115, R116, R117, R118, R127, R130, R139, R140, R142, R143, R201, R301, R401, R501, R601, R701, R801, R901, R1001 | 19 | 3k3 | R_0402_1005Metric_MiniFont | Resistor | 1% |  |  |  |  |  | C25890 | https://jlcpcb.com/partdetail/C25890
PCBA | R124, R129 | 2 | 1k | R_0402_1005Metric_MiniFont | Resistor | 1% |  |  |  |  |  | C11702 | https://jlcpcb.com/partdetail/C11702
PCBA | R128 | 1 | 220 | R_0402_1005Metric_MiniFont | Resistor | 1% |  |  |  |  |  | C25091 | https://jlcpcb.com/partdetail/C25091
PCBA | R131, R132 | 2 | 120 | R_0402_1005Metric_MiniFont | Resistor | 1% |  |  | 1/16W |  |  | C25079 | https://jlcpcb.com/partdetail/C25079
PCBA | R204, R205, R207, R304, R305, R307, R404, R405, R407, R504, R505, R507, R604, R605, R607, R704, R705, R707, R804, R805, R807, R904, R905, R907, R1004, R1005, R1007 | 27 | 22k | R_0402_1005Metric_MiniFont | Resistor | 1% |  |  |  |  |  | C25768
PCBA | R206, R306, R406, R506, R606, R706, R806, R906, R1006 | 9 | 33k | R_0402_1005Metric_MiniFont | Resistor | 1% |  |  |  |  |  | C25779
PCBA | SW101, SW103 | 2 | SW_SPST | TS1088AR02016 | Single Pole Single Throw (SPST) switch |  |  |  |  | XUNPU | TS-1088-AR02016 | C720477
PCBA | U101, U102 | 2 | L78L05_SOT89 | SOT-89-3 | Positive 100mA 30V Linear Regulator, Fixed Output 5V, SOT-89 |  |  |  |  | UTC | 78L05G-AB3-R | C71136 | https://www.unisonic.com.tw/datasheet/78LXX.pdf
PCBA | U103 | 1 | XC6206P332MR-G | SOT-23-3 | Positive 60-250mA Low Dropout Regulator, Fixed Output, SOT-23 |  |  |  |  | Torex | XC6206P332MR-G | C5446 | https://www.torexsemi.com/file/xc6206/XC6206.pdf
PCBA | U105 | 1 | STM32F030C8T6 | LQFP-48_7x7mm_P0.5mm | STMicroelectronics Arm Cortex-M0 MCU, 64KB flash, 8KB RAM, 48 MHz, 2.4-3.6V, 39 GPIO, LQFP48 |  |  |  |  | STMicro | STM32F030C8T6 | C23922 | https://www.st.com/resource/en/datasheet/stm32f030c8.pdf
PCBA | U106 | 1 | M24C64-RMN6TP | SOIC-8_3.9x4.9mm_P1.27mm | 64Kb serial FRAM nonvolatile Memory, SOIC-8 |  |  |  |  | STMicro | M24C64-RMN6TP | C79988 | https://www.st.com/ja/memories/m24c64-r.html
PCBA | U107 | 1 | SN74HCT04DR | SOIC-14_3.9x8.7mm_P1.27mm | Hex Inverter, Input are TTL-Voltage compatible |  |  |  |  | TI | SN74HCT04DR | C6766 | https://assets.nexperia.com/documents/data-sheet/74HC_HCT04.pdf
PCBA | U108, U109, U110 | 3 | SN74LVC1G66DCKR | SOT-353_SC-70-5 | SPST Analog Switch, 1.08V to 5.5V Supply, Normally OFF |  |  |  |  | TI | SN74LVC1G66DCKR | C113518 | https://www.ti.com/lit/ds/symlink/sn74lvc1g66.pdf
Hand | J101 | 1 | Conn_ST_STDC14 | STDC14_2x07_P1.27mm_Vertical_ST-LINKV3 | ST Debug Connector, standard ARM Cortex-M SWD and JTAG interface plus UART |  |  |  |  | hanxia | HX JN1.27-2x7P ZZ H4.9 |  | https://www.st.com/content/ccc/resource/technical/document/user_manual/group1/99/49/91/b6/b2/3a/46/e5/DM00526767/files/DM00526767.pdf/jcr:content/translations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
Hand | J102 | 1 | B3B-PH-K-S | JST_PH_B3B-PH-K_1x03_P2.00mm_Vertical | Generic connector, single row, 01x03, script generated |  |  |  |  | JST | B3B-PH-K-S(LF)(SN)
Hand | J103 | 1 | PH-2x10SG | PinHeader_2x10_P2.54mm_Vertical | Generic connector, double row, 02x10, odd/even pin numbering scheme (row 1 odd numbers, row 2 even numbers), script generated (kicad-library-utils/schlib/autogen/connector/) |  |  |  |  | Useconn | PH-2x10SG
Hand | J104 | 1 | MJ-8435 | MJ-8435 | Audio Jack, 3 Poles (Stereo / TRS) |  |  |  |  | Maru-Shin | MJ-8435
Hand | J105 | 1 | PH-2x4SG | PinHeader_2x04_P2.54mm_Vertical | Generic connector, double row, 02x04, odd/even pin numbering scheme (row 1 odd numbers, row 2 even numbers), script generated (kicad-library-utils/schlib/autogen/connector/) |  |  |  |  | Chang Enn | PH-2x4SG |  | https://akizukidenshi.com/catalog/g/g116793/
Hand | J106 | 1 | PH11-2x10SAG | PinHeader_2x10_P1.27mm_Vertical | Generic connector, double row, 02x10, odd/even pin numbering scheme (row 1 odd numbers, row 2 even numbers), script generated (kicad-library-utils/schlib/autogen/connector/) |  |  |  |  | Chang Enn | PH11-2x10SAG |  | https://akizukidenshi.com/catalog/g/g113801/
Hand | J107 | 1 | B6B-ZR-3.4(LF)(SN) | JST_ZH_B6B-ZR_1x06_P1.50mm_Vertical | Generic connector, single row, 01x06, script generated |  |  |  |  | JST | B6B-ZR-3.4(LF)(SN) |  | https://akizukidenshi.com/catalog/g/g114159/
Hand | SW102 | 1 | KSD42 | DIP-8_W7.62mm | 4x DIP Switch, Single Pole Single Throw (SPST) switch, small symbol |  |  |  |  | OTAX | KSD42 |  | https://akizukidenshi.com/catalog/g/g108923/
Hand | U104 | 1 | NJW4191M | DMP-8_P1.27mm_HandSolder | Inverting charge pump IC, 4.7V to 17V Supply, 55mA max, 300kHz |  |  |  |  | Nisshinbo | NJW4191M |  | https://www.nisshinbo-microdevices.co.jp/ja/pdf/datasheet/NJW4191_J.pdf
DNP | C108 | 1 | 10u | C_0805_2012Metric | Unpolarized capacitor | 10% | 50V | X5R |  | Murata | GRM21BR61H106KE43L | C440198

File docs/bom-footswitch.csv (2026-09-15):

Assembly | References | Qty | Value | Footprint | Description | Tolerance | Voltage | Dielectric | Power | Manufacturer | MPN | LCSC | Datasheet
Hand | J1 | 1 | Conn_01x03_Socket | JST_PH_B3B-PH-K_1x03_P2.00mm_Vertical | Generic connector, single row, 01x03, script generated |  |  |  |  | JST | B3B-PH-K-S(LF)(SN)
Hand | SW1 | 1 | SW_DPDT_x2 | Alpha_Foot_Switch_DPDT | Momentary footswitch, any type (both poles are wired in parallel); the built unit used an Alpha momentary DPDT footswitch (e.g. Sakuraya Denkiten fs85_i-5) |  |  |  |  | Alpha

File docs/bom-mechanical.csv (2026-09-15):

Item | Qty | Description | Manufacturer | MPN | Supplier | Supplier part | URL | Used for | Notes
Enclosure, top shell | 1 | Sheet metal U-shell, aluminum 5052, t = 1.5 mm, anodized black glossy |  |  | JLCCNC (made to order, sheet metal) |  |  | Top face and both side walls: pots, LED, toggles, footswitch, 1/4 in jacks | See enclosure/ drawings (hole drawing sheet 1 "Top"). Ordered together with the bottom shell as one sheet-metal assembly; order finish was laser marking (top face only) + Anodizing Black Glossy
Enclosure, bottom shell | 1 | Sheet metal U-shell with 4 tapped tabs (M3x0.5 burring, 2.0 mm effective thread), aluminum 5052, t = 1.5 mm, anodized black glossy |  |  | JLCCNC (made to order, sheet metal) |  |  | Back cover and end wall: DC jack, 2x 3.5 mm MIDI jacks | See enclosure/ drawings (hole drawing sheet 2 "Bottom"). No laser marking on the bottom shell (marking is on the top face only)
Enclosure screw | 4 | Pan head machine screw (+), M3x5, brass |  |  | Akizuki Denshi | 107325 | https://akizukidenshi.com/catalog/g/g107325/ | Top shell (4x dia. 3.6 mm holes) to bottom shell (4x M3 tapped tabs) | Same part as the PCB spacer screws. Supplier part 107325 is a pack of 100
PCB spacer | 2 | Hex spacer, female-female, M3x0.5, length 11 mm, 5.5 mm across flats, brass | M.Y.G | FB3-11 | Akizuki Denshi | 115440 | https://akizukidenshi.com/catalog/g/g115440/ | Joins top and bottom PCBs at H1-H101 and H2-H102 | Supplier part 115440 is a single piece (pack of 100: 115639)
PCB spacer screw | 4 | Pan head machine screw (+), M3x5, brass |  |  | Akizuki Denshi | 107325 | https://akizukidenshi.com/catalog/g/g107325/ | Fixing the 2 PCB spacers (one screw from each PCB side per spacer) | Same part as the enclosure screws
Knob | 4 | Aluminum knob, Davies 1510 style, silver, 19 mm dia., 14.6 mm high, 6.35 mm round shaft hole, set screw |  |  | Tayda Electronics | A-7154 | https://www.taydaelectronics.com/aluminum-davies-1510-clone-silver-knob-shaft-hole-6-35-mm.html | RV1-RV4 (top PCB)
Footswitch cable | 1 | Cable with connector, 3-pin, 2.0 mm pitch (JST PH compatible) straight plug, 150 mm, black/orange/white, other end solder-plated | Herwell Asia Limited | GP2A-2-B | Akizuki Denshi | 111659 | https://akizukidenshi.com/catalog/g/g111659/ | Bottom PCB J102 to footswitch PCB J1 | The intended part is a made-to-order JST PH 3-pin cable of specified length; the initial production run used Akizuki 111659 instead

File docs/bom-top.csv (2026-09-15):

Assembly | References | Qty | Value | Footprint | Description | Tolerance | Voltage | Dielectric | Power | Manufacturer | MPN | LCSC | Datasheet
PCBA | C1 | 1 | 1u | C_0805_2012Metric | Unpolarized capacitor | 10% | 50V | X7R |  | Samsung Electro-Mechanics | CL21B105KBFNNNE | C28323
PCBA | C3, C8, C9, C10 | 4 | 10uF | C_0805_2012Metric | Unpolarized capacitor | 10% | 25V | X5R |  | Samsung Electro-Mechanics | CL21A106KAYNNNE | C15850
PCBA | C4, C11, C12, C15, C18, C20, C21, C22, C26, C29, C30, C31, C32, C36, C37, C42, C43, C48 | 18 | 0.1u | C_0603_1608Metric | Unpolarized capacitor | 10% | 50V | X7R |  |  |  | C14663
PCBA | C5 | 1 | 470p | C_0603_1608Metric | Unpolarized capacitor | 10% | 50V | X7R |  |  |  | C1620
PCBA | C6 | 1 | 4.7u | C_0805_2012Metric | Unpolarized capacitor | 10% | 25V | X5R |  |  |  | C1779
PCBA | C14, C39, C40 | 3 | 0.01u | C_0603_1608Metric | Unpolarized capacitor | 5% | 50V | C0G |  | Murata | GRM1885C1H103JA01D | C85973
PCBA | C16, C17, C19 | 3 | 2200p | C_0805_2012Metric | Unpolarized capacitor | 5% | 50V | C0G |  |  |  | C28260
PCBA | C24 | 1 | 0.047u | C_0805_2012Metric | Unpolarized capacitor | 10% | 50V | X7R |  |  |  | C53134
PCBA | C33 | 1 | 47p | C_0603_1608Metric | Unpolarized capacitor | 5% | 50V | C0G |  |  |  | C1671
PCBA | C34, C38, C45, C50 | 4 | 10u | CP_Elec_4x5.4 | Polarized capacitor | 20% | 16V | electrolytic |  | Panasonic | EEE1CA100SR | C178496
PCBA | C35 | 1 | 100p | C_0603_1608Metric | Unpolarized capacitor | 5% | 50V | C0G |  |  |  | C14858
PCBA | C44 | 1 | 220p | C_0603_1608Metric | Unpolarized capacitor | 10% | 50V | X7R |  |  |  | C1603
PCBA | C46 | 1 | 33p | C_0603_1608Metric | Unpolarized capacitor | 5% | 50V | C0G |  |  |  | C1663
PCBA | D3 | 1 | BZT52C15 | D_SOD-123 | Zener diode, VZ = 15V |  |  |  |  | R+O | BZT52C15 | C19077412
PCBA | D4, D9, D10, D11, D14 | 5 | LED(RED) | D_0603_1608Metric_Name | Light emitting diode |  |  |  |  | Hubei KENTO Elec | KT-0603R | C2286
PCBA | D5 | 1 | BAT54S | SOT-23 | Vr 30V, If 200mA, Dual schottky barrier diode, in series, SOT-23 |  |  |  |  | R+O | BAT54S | C7420333 | https://www.diodes.com/assets/Datasheets/ds11005.pdf
PCBA | D6, D7, D8 | 3 | 1N5819WS | D_SOD-323 | 40V 600mV@1A 1A SOD-323 Schottky Barrier Diodes, SOD-323 |  |  |  |  | Guangdong Hottech | 1N5819WS | C191023 | https://datasheet.lcsc.com/lcsc/2204281430_Guangdong-Hottech-1N5819WS_C191023.pdf
PCBA | D12, D15, D16, D17, D18, D19, D20, D21, D22, D23, D24, D25, D26, D27, D28, D29 | 16 | 1N4148WS | D_SOD-323 | 75V 0.15A Fast switching Diode, SOD-323 |  |  |  |  | JSCJ | 1N4148WS | C2128 | https://www.vishay.com/docs/85751/1n4148ws.pdf
PCBA | Q2 | 1 | SS8550 Y2 | SOT-23 | PNP BJT |  |  |  |  | JSCJ | SS8550 Y2(RANGE:200-350) | C8542 | https://www.lcsc.com/datasheet/lcsc_datasheet_1810161212_Jiangsu-Changjing-Electronics-Technology-Co---Ltd--SS8550-Y2-RANGE-200-350_C8542.pdf
PCBA | Q4, Q5, Q6, Q8, Q9, Q10, Q11, Q14, Q15, Q16, Q17 | 11 | 2SK880-GR | SOT-323_SC-70 | N-JFET transistor |  |  |  |  | Toshiba | 2SK880-GR | C7469759
PCBA | Q7, Q18 | 2 | S9013-J3 | SOT-23 | NPN BJT |  |  |  |  | JSCJ | S9013 J3(RANGE:200-350) | C6749 | https://www.lcsc.com/datasheet/lcsc_datasheet_1810051504_Jiangsu-Changjing-Electronics-Technology-Co---Ltd--S9013-J3-RANGE-200-350_C6749.pdf
PCBA | R1, R40, R61, R93 | 4 | 100k | R_0603_1608Metric | Resistor | 1% |  |  |  |  |  | C25803
PCBA | R2, R28 | 2 | 33k | R_0603_1608Metric | Resistor | 1% |  |  |  |  |  | C4216
PCBA | R3, R27, R49, R83, R92 | 5 | 10k | R_0603_1608Metric | Resistor | 1% |  |  |  |  |  | C25804 | https://jlcpcb.com/partdetail/C25804
PCBA | R4, R87, R88 | 3 | 470k | R_0603_1608Metric | Resistor | 1% |  |  |  |  |  | C23178
PCBA | R5, R37, R73, R74, R85 | 5 | 47k | R_0603_1608Metric | Resistor | 1% |  |  |  |  |  | C25819 | https://jlcpcb.com/partdetail/C25819
PCBA | R6, R12, R14, R45 | 4 | 6k8 | R_0603_1608Metric | Resistor | 1% |  |  |  |  |  | C23212 | https://jlcpcb.com/partdetail/C23212
PCBA | R7, R23, R58 | 3 | 22k | R_0603_1608Metric | Resistor | 1% |  |  |  |  |  | C31850 | https://jlcpcb.com/partdetail/C31850
PCBA | R8, R46, R76, R78 | 4 | 1k5 | R_0603_1608Metric | Resistor | 1% |  |  |  |  |  | C22843 | https://jlcpcb.com/partdetail/C22843
PCBA | R9, R16, R59, R60 | 4 | 4k7 | R_0603_1608Metric | Resistor | 1% |  |  |  |  |  | C23162 | https://jlcpcb.com/partdetail/C23162
PCBA | R10 | 1 | 4.7 | R_0603_1608Metric | Resistor | 1% |  |  |  |  |  | C23164
PCBA | R11 | 1 | 22 | R_0603_1608Metric | Resistor | 1% |  |  |  |  |  | C23345
PCBA | R13, R19, R36, R56, R57, R84 | 6 | 3k3 | R_0603_1608Metric | Resistor | 1% |  |  |  |  |  | C22978 | https://jlcpcb.com/partdetail/C22978
PCBA | R15 | 1 | 220 | R_0603_1608Metric | Resistor | 1% |  |  |  |  |  | C22962
PCBA | R17 | 1 | 33 | R_0603_1608Metric | Resistor | 1% |  |  |  |  |  | C23140
PCBA | R18, R20, R50, R53, R62, R67, R71, R75, R77, R94 | 10 | 1k | R_0603_1608Metric | Resistor | 1% |  |  |  |  |  | C21190 | https://jlcpcb.com/partdetail/C21190
PCBA | R21, R26, R31, R35, R39, R43, R48, R52, R65, R70, R72 | 11 | 1M | R_0603_1608Metric | Resistor | 1% |  |  |  |  |  | C22935
PCBA | R22, R79, R80 | 3 | 2k2 | R_0603_1608Metric | Resistor | 1% |  |  |  |  |  | C4190
PCBA | R24, R29, R33, R38, R41, R47, R51, R64, R69, R86 | 10 | 100M | R_0603_1608Metric | Resistor | 5% |  |  |  |  |  | C422892
PCBA | R25, R30, R34, R42, R81, R89, R91 | 7 | 220k | R_0603_1608Metric | Resistor | 1% |  |  |  |  |  | C22961
PCBA | R32, R44 | 2 | 56k | R_0603_1608Metric | Resistor | 1% |  |  |  |  |  | C23206
PCBA | R54 | 1 | 330k | R_0603_1608Metric | Resistor | 1% |  |  |  |  |  | C23137
PCBA | R55 | 1 | 150k | R_0603_1608Metric | Resistor | 1% |  |  |  |  |  | C22807
PCBA | R63, R66, R68, R90 | 4 | 15k | R_0603_1608Metric | Resistor | 1% |  |  |  |  |  | C22809 | https://jlcpcb.com/partdetail/C22809
PCBA | R82 | 1 | 470 | R_0603_1608Metric | Resistor | 1% |  |  |  |  |  | C23179
PCBA | U1 | 1 | MIC5205YM5 | SOT-23-5 | 150mA low dropout linear regulator, adjustable output, SOT-23-5 |  |  |  |  | Microchip | MIC5205YM5 | C412820 | http://ww1.microchip.com/downloads/en/DeviceDoc/20005785A.pdf
PCBA | U3 | 1 | TL072CDT | SOIC-8_3.9x4.9mm_P1.27mm | Dual Low-Noise JFET-Input Operational Amplifiers, DIP-8/SOIC-8 |  |  |  |  | STMicro | TL072CDT | C6961 | http://www.ti.com/lit/ds/symlink/tl071.pdf
Hand | C2 | 1 | 470u | CP_Radial_D10.0mm_P5.00mm | Polarized capacitor | 20% | 25V | Polymer electrolytic |  | Rubycon | 25PZJ470M10X9
Hand | C7 | 1 | 100u | CP_Radial_D6.3mm_P2.50mm | Polarized capacitor | 20% | 16V | Polymer electrolytic |  | Panasonic | 16SEPC100M
Hand | C13, C23, C47, C49 | 4 | 1u | C_1206_3216Metric_Pad1.33x1.80mm_HandSolder | PMLCAP | 20% | 25V | film |  | Rubycon | 25NS105MA23216
Hand | C25, C27 | 2 | 10u | C_1812_4532Metric_Pad1.57x3.40mm_HandSolder | PMLCAP | 20% | 16V | film |  | Rubycon | 16MU106MC44532
Hand | C28, C41 | 2 | 0.047u | C_1206_3216Metric_Pad1.33x1.80mm_HandSolder | Unpolarized capacitor | 5% | 50V | C0G |  | Murata | GRM31M5C1H473JA01L | C21812
Hand | D13 | 1 | LED_PL9823-F5 | LED_D5.0mm-4_RGB_Wide_Pins | RGB LED, Multicolor |  |  |  |  | Shenzhen Rita Lighting | PL9823-F5 |  | https://akizukidenshi.com/catalog/g/g108411/
Hand | J1 | 1 | Barrel_Jack_Switch | MJ-179PH_Edge | DC Barrel Jack with an internal switch |  |  |  |  | Maru-Shin | MJ-179PH
Hand | J2 | 1 | MJ-8435 | MJ-8435 | Audio Jack, 3 Poles (Stereo / TRS) |  |  |  |  | Maru-Shin | MJ-8435
Hand | J3 | 1 | FH-1x4SG/RH | PinSocket_2x04_P2.54mm_Vertical | Generic connector, double row, 02x04, odd/even pin numbering scheme (row 1 odd numbers, row 2 even numbers), script generated (kicad-library-utils/schlib/autogen/connector/) |  |  |  |  | Chang Enn | FH-1x4SG/RH x2 |  | https://akizukidenshi.com/catalog/g/g110099/
Hand | J4 | 1 | FH-2x10SG | PinSocket_2x10_P2.54mm_Vertical | Generic connector, double row, 02x10, odd/even pin numbering scheme (row 1 odd numbers, row 2 even numbers), script generated (kicad-library-utils/schlib/autogen/connector/) |  |  |  |  | Chang Enn | FH-2x10SG
Hand | J5, J7 | 2 | NMJ6HCD3 | Jack_6.35mm_Neutrik_NMJ6HCD3_Horizontal | 6.35mm (1/4in) stereo jack, switched, with chrome ferrule and offset PCB pins |  |  |  |  | Neutrik | NMJ6HCD3 |  | https://www.neutrik.com/en/product/nmj6hcd3
Hand | J6 | 1 | A1001WR-S-04P | JST_SH_SM04B-SRSS-TB_1x04-1MP_P1.00mm_Horizontal | Generic connectable mounting pin connector, single row, 01x04, script generated (kicad-library-utils/schlib/autogen/connector/) |  |  |  |  | Herwell | A1001WR-S-04P |  | https://akizukidenshi.com/catalog/g/g116800/
Hand | J8 | 1 | B6B-PH-K-S | JST_PH_B6B-PH-K_1x06_P2.00mm_Vertical | Generic connector, single row, 01x06, script generated |  |  |  |  | JST | B6B-PH-K-S(LF)(SN) |  | https://akizukidenshi.com/catalog/g/g112806/
Hand | Q1, Q3 | 2 | SSM3J334R | SOT-23 | P-MOSFET transistor, drain/source/gate |  |  |  |  | Toshiba | SSM3J334R | C396017 | https://toshiba.semicon-storage.com/info/SSM3J334R_datasheet_ja_20181004.pdf?did=5578&prodName=SSM3J334R
Hand | Q12, Q13 | 2 | 2SC945-K | TO-92_Inline_Wide | 0.15A Ic, 50V Vce, Low Noise Audio NPN Transistor, TO-92 |  |  |  |  | UTC | 2SC945-K |  | https://akizukidenshi.com/goodsaffix/2SC945_nec.pdf
Hand | RV1 | 1 | 10kC | Potentiometer_Alpha_RD901F-40-00D_Single_Vertical_CenterAnker_GND | Potentiometer with a mounting pin |  |  |  |  | Alpha | RD901F-40-15R1-C10K
Hand | RV2, RV3 | 2 | 20kB | Potentiometer_Alpha_RD901F-40-00D_Single_Vertical_CenterAnker_GND | Potentiometer with a mounting pin |  |  |  |  | Alpha | RD901F-40-15R1-B20K
Hand | RV4 | 1 | 50kA | Potentiometer_Alpha_RD901F-40-00D_Single_Vertical_CenterAnker_GND | Potentiometer with a mounting pin |  |  |  |  | Alpha | RD901F-40-15R1-A50K
Hand | SW1, SW2, SW3 | 3 | 2MS3-T1-B4-M2-Q-E | Toggle_SW_mini_2MS1-T1-B4-M2-Q-E | Switch, single pole double throw, center OFF position |  |  |  |  | Cosland | 2MS3-T1-B4-M2-Q-E |  | https://akizukidenshi.com/catalog/g/g102400/
Hand | U2 | 1 | TLP2361 | SO-5-6_4.55x3.7mm_P1.27mm | 5-Mbps low-power non inverting photocouple, 3.75 kVrms, 2.7 - 5.5 Vdd, push-pull output |  |  |  |  | Toshiba | TLP2361 | C107626 | https://akizukidenshi.com/catalog/g/g111004/
Hand | U4 | 1 | TLV9362IDR | SOIC-8_3.9x4.9mm_P1.27mm | 40-V, 1-MHz, RRO Operational Amplifiers for Cost-Sensitive Systems, SOIC-8 |  |  |  |  | TI | TLV9362IDR | C4367884 | https://www.ti.com/lit/ds/symlink/tlv9302.pdf
DNP | D1, D2 | 2 | MMSZ5245B | D_SOD-123 | Zener diode, small symbol |  |  |  |  | R+O | MMSZ5245B | C19077428

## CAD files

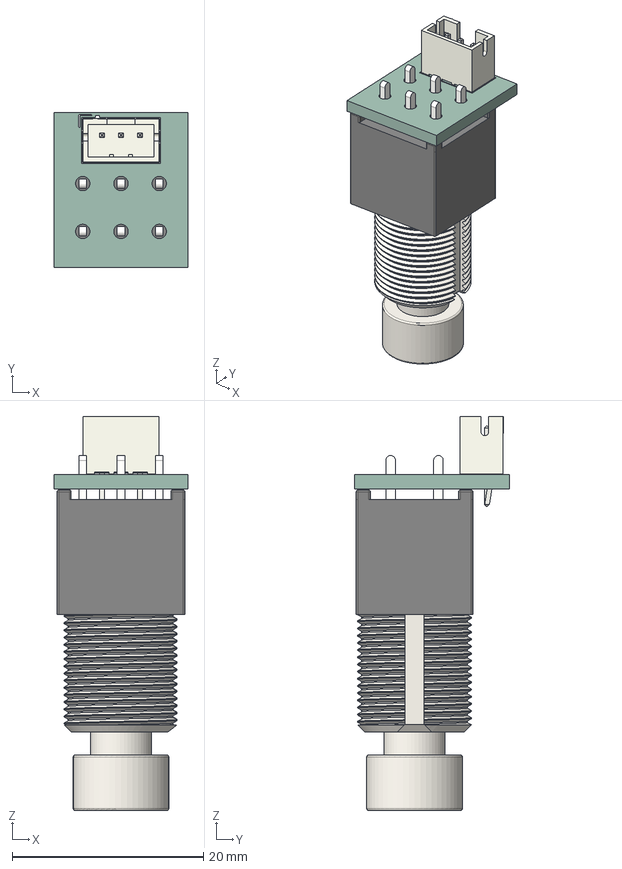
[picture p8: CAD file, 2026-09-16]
docs/3d/anthracite-footswitch.step
14.0 x 16.1 x 41.2 mm
JST_PH_B3B-PH-K_1x03_P2.00mm_Vertical
SW_Foot_Alpha_DPDT
anthracite-footswitch_silkscreen x 2
anthracite-footswitch_PCB

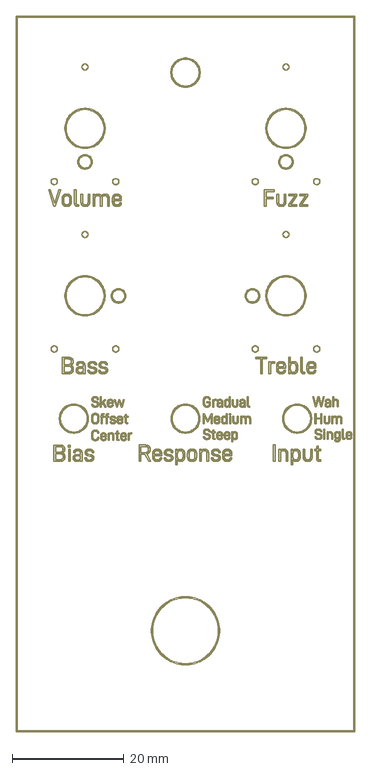
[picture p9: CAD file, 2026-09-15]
enclosure/panel-artwork.dxf
60.7 x 128.2 mm

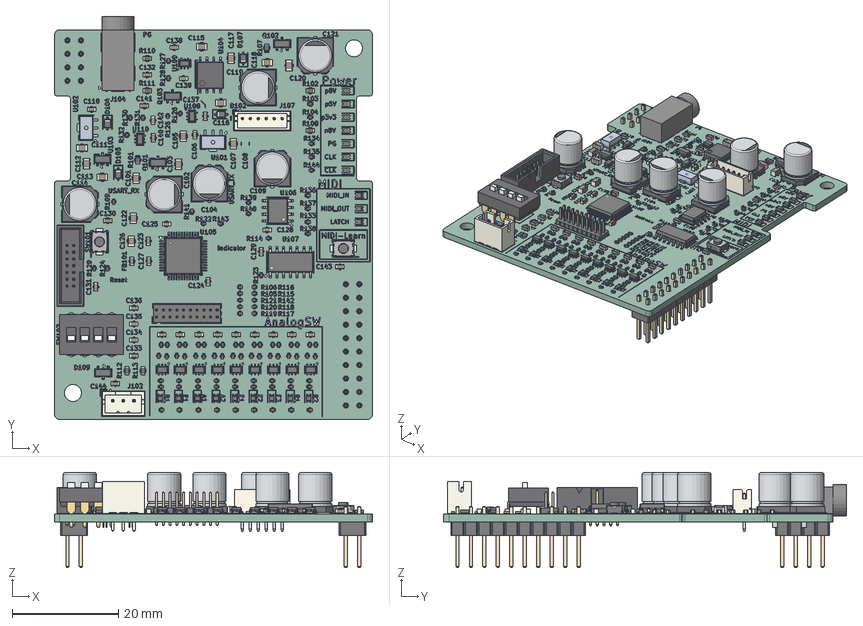
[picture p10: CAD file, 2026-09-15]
docs/3d/anthracite-bottom.step
60.0 x 76.0 x 17.9 mm
R_0402_1005Metric x 99
SOT-363_SC-70-6 x 9
D_SOD-323 x 4
C_0805_2012Metric x 14
C_0603_1608Metric x 32
SOIC-14_3.9x8.7mm_P1.27mm
D_0603_1608Metric x 19
SW_SPST_TS-1088-xR020 x 2
anthracite-bottom 1.41.1 x 2
plate x 6
can x 6
neg_mark x 6
term_plus x 6
term_minus x 6
R_0603_1608Metric x 8
SOT-23 x 4
lead1
lead2
lead3
lead4
lead5
lead6
lead7
lead8
housing x 2
pin1 x 3
pin2 x 3
pin3 x 3
pin4 x 3
pin5 x 3
pin6 x 3
case
knob1
knob2
knob3
knob4
pin8 x 2
pin7 x 2
MJ-8435
LQFP-48_7x7mm_P0.5mm
pin9
pin10
pin11
pin12
pin13
pin14
SOT-353_SC-70-5 x 3
PinHeader_2x10_P1.27mm_Vertical
SOT-23-3
L_0603_1608Metric
SOIC-8_3.9x4.9mm_P1.27mm
JST_PH_B3B-PH-K_1x03_P2.00mm_Vertical
PinHeader_2x04_P2.54mm_Vertical
PinHeader_2x10_P2.54mm_Vertical
anthracite-bottom_silkscreen x 2
anthracite-bottom_PCB

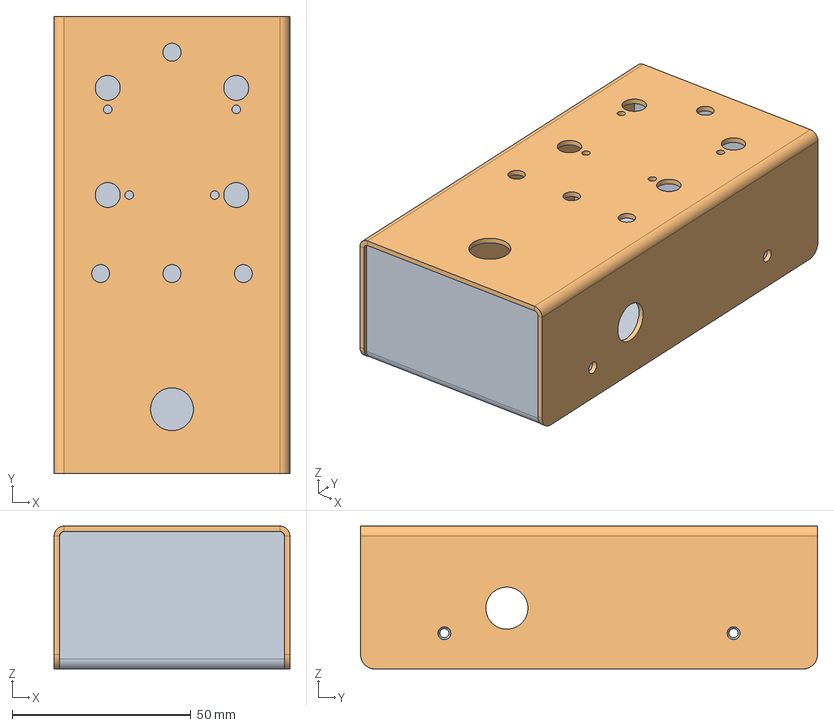
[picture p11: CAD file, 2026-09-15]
enclosure/anthracite-enclosure.step
66.0 x 128.0 x 40.0 mm

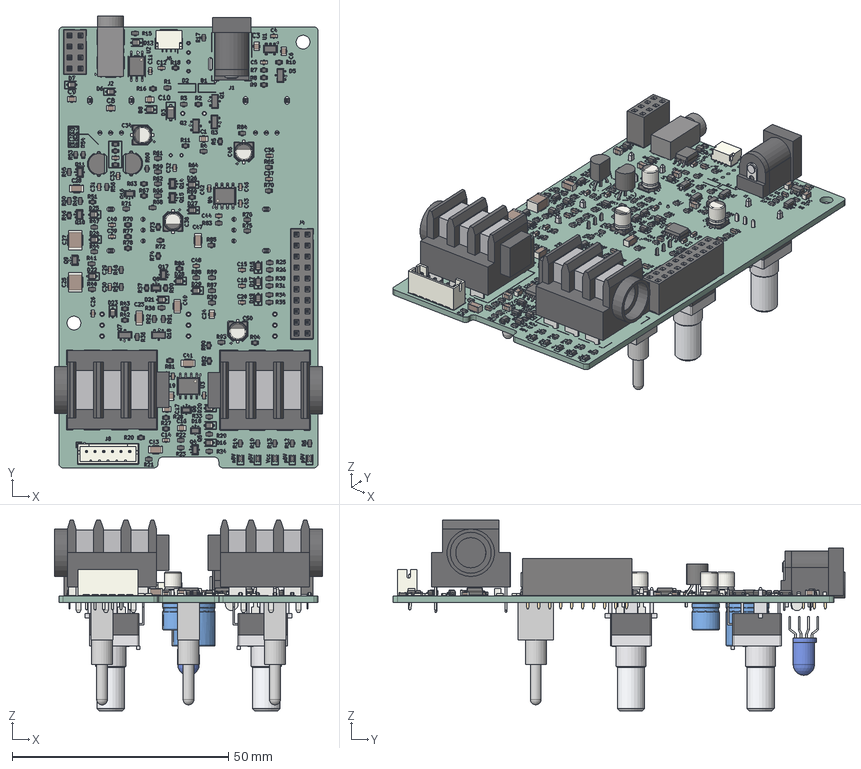
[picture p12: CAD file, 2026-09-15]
docs/3d/anthracite-top.step
62.0 x 104.5 x 44.1 mm
D_SOD-323 x 19
C_0603_1608Metric x 26
C_0805_2012Metric x 10
C_1812_4532Metric x 2
R_0603_1608Metric x 94
C_1206_3216Metric x 6
SOT-323_SC-70 x 11
CP_Elec_4x5.4 x 4
PinSocket_2x10_P2.54mm_Vertical
D_0603_1608Metric x 5
SOT-23 x 6
MJ-8435
JST_PH_B6B-PH-K_1x06_P2.00mm_Vertical
SO-5-6_4.55x3.7mm_P1.27mm
SOIC-8_3.9x4.9mm_P1.27mm x 2
TO-92_Inline_Wide x 2
JST_SH_SM04B-SRSS-TB_1x04-1MP_P1.00mm_Horizontal
housing x 3
contacts x 2
pin_SN x 2
pin_RN x 2
pin_TN x 2
pin_S x 2
pin_R x 2
pin_T x 2
D_SOD-123
insulator
centre_pin
term_S
term_J
term_B
PinSocket_2x04_P2.54mm_Vertical
SOT-23-5
CP_Radial_D6.3mm_P2.50mm
case x 4
cover x 4
bracket x 4
bushing x 4
shaft x 4
pin1 x 4
pin2 x 4
pin3 x 4
2MS1-T1-B4-M2-Q-E x 3
LED_D5.0mm-4_RGB_Wide_Pins
CP_Radial_D10.0mm_P5.00mm
anthracite-top_silkscreen x 2
anthracite-top_PCB

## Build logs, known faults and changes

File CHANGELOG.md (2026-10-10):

# Changelog

All notable changes to this project are documented here.

The format follows [Keep a Changelog](https://keepachangelog.com/en/1.1.0/),
extended with a **Hardware** / **Firmware** / **Errata** / **Documentation**
split, because hardware and firmware move at different speeds.

Versioning is described in the README. In short: the product and the boards
carry `vMAJOR.MINOR`, the firmware carries its own semantic version, and the
two are listed together for each release.

## [Unreleased]

### Hardware
- (nothing yet)

### Firmware
- (nothing yet)

### Errata
- See [ERRATA.md](ERRATA.md)

### Documentation
- (nothing yet)

## [1.0.0] - 2026-10-07

First public release.

### Hardware
- Anthracite v1.0. Analogue signal path throughout, switched by analogue
  switches rather than mechanical contacts, with a buffered bypass.
- Three circuit boards: top (analogue), bottom (control) and footswitch, plus
  the front-panel artwork.
- Four potentiometers (Volume, Fuzz, Bass, Treble) and three-position toggles
  for Bias, Response and Input.
- The published top and bottom boards carry `V1.0`, CERN-OHL-S-2.0 and
  `github.com/trope-oshw/anthracite` on the silkscreen in place of the product
  name. Boards from the first production run carry `Anthracite V1.0` instead
  and are otherwise identical.
- The NMJ6HCD3 symbol stored in the top schematic names the same footprint
  as J5, J7 and the board. Only that symbol metadata changed; the board, the
  Gerbers and the BOM match the shipped boards.

### Firmware
- 1.0.0. MIDI CC control of the toggles, MIDI-Learn, MIDI Thru, and Active
  Sensing output.
- Source in `firmware/`: the STM32CubeMX project, the CMake build, and the ST
  HAL and CMSIS. The `Debug` preset reproduces the shipped flash image; see
  [firmware/README.md](firmware/README.md) for the toolchain and the SHA-256.

### Errata
- None known at release.

### Documentation
- User manual published at https://docs.trope-oshw.org
- Parts list in [hardware/parts.md](hardware/parts.md).
- README product photo: a top view of the finished pedal, plus angled, top
  edge and side views.

[Unreleased]: https://github.com/trope-oshw/anthracite/compare/v1.0.0...HEAD
[1.0.0]: https://github.com/trope-oshw/anthracite/releases/tag/v1.0.0

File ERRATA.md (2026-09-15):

# Errata

Known problems in hardware that has already been built, and what to do about
them. This file also lists recommended modifications: changes that fix nothing,
but improve a board you already have.

**This file is the right place to look if your board does not behave like the
schematic says it should.** Design files are only corrected in the next
revision — a fix to the source does not help someone holding a board that was
already made. So problems found after a release are written down here instead.

Each entry names the affected revision explicitly. If your board's revision is
not listed, the entry does not apply to it.

---

## Anthracite v1.0

No errata recorded yet.

The entry below is a recommended modification, not an erratum. A v1.0 board
works as designed without it.

### M-1 · R38 / R86 at 200 MΩ for less switching pop

**Affects:** Anthracite v1.0, all boards. R38 and R86 on the top board are
100 MΩ.

**What it improves:** the low thump ("pop") at the output when the pedal
switches between bypass and effect. With 100 MΩ, v1.0 already meets the pop
target set during development, by 3.2 – 4.0 dB. Raising R38 and R86 to 200 MΩ
lowered the pop by a further 4.9 – 6.3 dB. By ear, the pop was then hard to
hear without turning the gain after the pedal well up.

**How it was measured:** on a prototype with the same output-switch values as
v1.0 (R37 = R85 = 47 kΩ, R90 = 15 kΩ). Pop was taken as the peak-to-peak output
after a first-order high-pass filter at 10 Hz or 20 Hz, which removes a slow,
inaudible part of the transient. Effect to bypass: 6.0 – 6.3 dB lower. Bypass
to effect: 4.9 – 5.0 dB lower.

**Why it works:** while a JFET switch (Q8 bypass, Q17 effect) is on, a small
current flows into its gate through R38 or R86, plus the leakage of the series
diode D21 or D28. That current sets a DC level on R90, and the level dips while
the switches change over; the dip is what you hear. Doubling the resistor
roughly halves the current. Measured with a DMM, it fell from 84.0 nA to
44.5 nA.

**Change:** replace both R38 and R86 with 200 MΩ. Change both, not one: the
result above assumes both switches draw the same gate current. The prototype
used two 100 MΩ resistors in series in each position.

**Costs and cautions:**

- **Temperature.** The current through the resistor does not change with
  temperature, but the diode leakage roughly doubles every 10 °C. With 200 MΩ
  the leakage is a larger share of the gate current (about 19 % instead of
  10 % at room temperature), so pop rises more when the pedal is warm. A model
  estimate for 45 °C inside the enclosure gives about +2.8 dB with 200 MΩ,
  against about +1.7 dB with 100 MΩ. This has not been measured.
- **Switching speed.** The gate charging time set by this resistor doubles,
  from about 1.25 ms to 2.5 ms (calculated). The gate RC networks already take
  tens of milliseconds, so the switching timing is not expected to change
  noticeably.
- **Not yet checked: distortion at high level.** With half the gate current,
  a switch may recover more slowly when a large low-frequency signal drives its
  gate, which could add distortion near maximum output. This has not been
  measured.
- **Leakage around the part.** At 200 MΩ, flux residue or other surface leakage
  can bypass the resistor and cancel the improvement. To confirm the change
  worked, measure the DC voltage across R90 with a DMM before and after, with
  the pedal in the same state. It should roughly halve; on the prototype it
  went from 956 µV to 506 µV.

**In later revisions:** 200 MΩ is planned, but no revision or date is set.

---

## How to read this file

Entries are written in this form:

> ### E-1 · Short title
>
> **Affects:** which revision(s), and how to tell whether yours is one of them
> **Symptom:** what you actually observe
> **Cause:** why it happens
> **Workaround:** what to do with a board you already have
> **Fixed in:** the revision that corrects it, or "not yet"

The workaround matters more than the cause. If you own the hardware, you need
to know what to do about it; the explanation is there so you can judge whether
the workaround is safe in your situation.

Recommended modifications are numbered M-1, M-2, and so on. They say what the
change improves, how that was measured, what it costs, and whether later
revisions are expected to include it. None of them is needed for the pedal to
work as specified.

## Reporting

If you find something that belongs here, please
[open an issue](https://github.com/trope-oshw/anthracite/issues) with your
board revision and firmware version. Errata are useful only if they are found
before the next person hits the same problem.

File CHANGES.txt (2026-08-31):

This file is the place to record modifications, as required by
CERN-OHL-S v2 subsection 3.3(b):

    "add a Notice to the modified Covered Source stating that You have
     modified it, with the date and a brief description of how You
     modified it"

If you modify anything in this repository and convey the result, add a
line here with the date and what you changed. For example:

    26 April 2026: Replaced the tone stack with a Baxandall network and
                   moved C21 to the input side of the volume control.

Modifications by the original licensor are recorded in CHANGELOG.md
instead. This file is for downstream modifications.

-------------------------------------------------------------------------

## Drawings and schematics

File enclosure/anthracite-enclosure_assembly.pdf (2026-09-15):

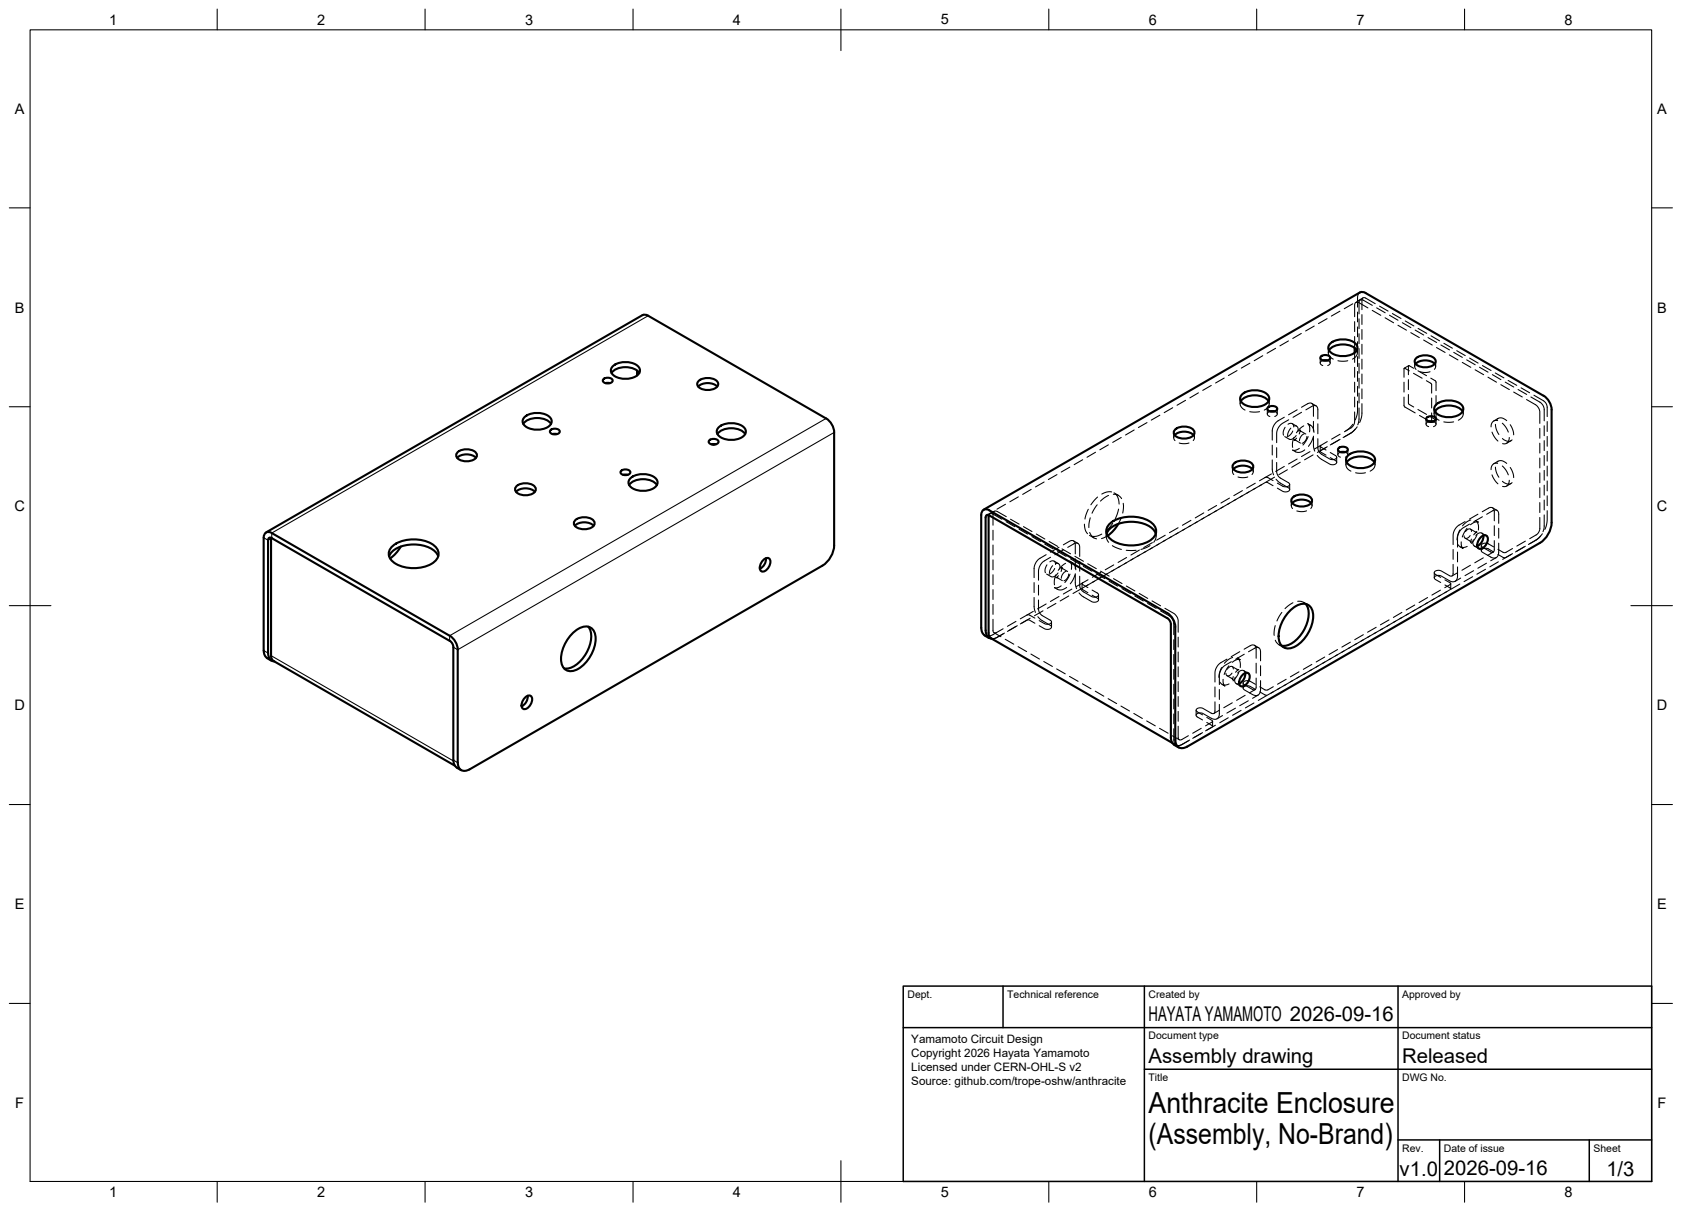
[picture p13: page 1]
Title; DWG No.; Rev.; Date of issue; Sheet

Dept. | Technical reference | Created by HAYATA YAMAMOTO 2026-09-16 | Approved by

Yamamoto Circuit Design
Copyright 2026 Hayata Yamamoto
Licensed under CERN-OHL-S v2
Source: github.com/trope-oshw/anthracite

Document type Assembly drawing | Document status Released

Anthracite Enclosure
(Assembly, No-Brand)

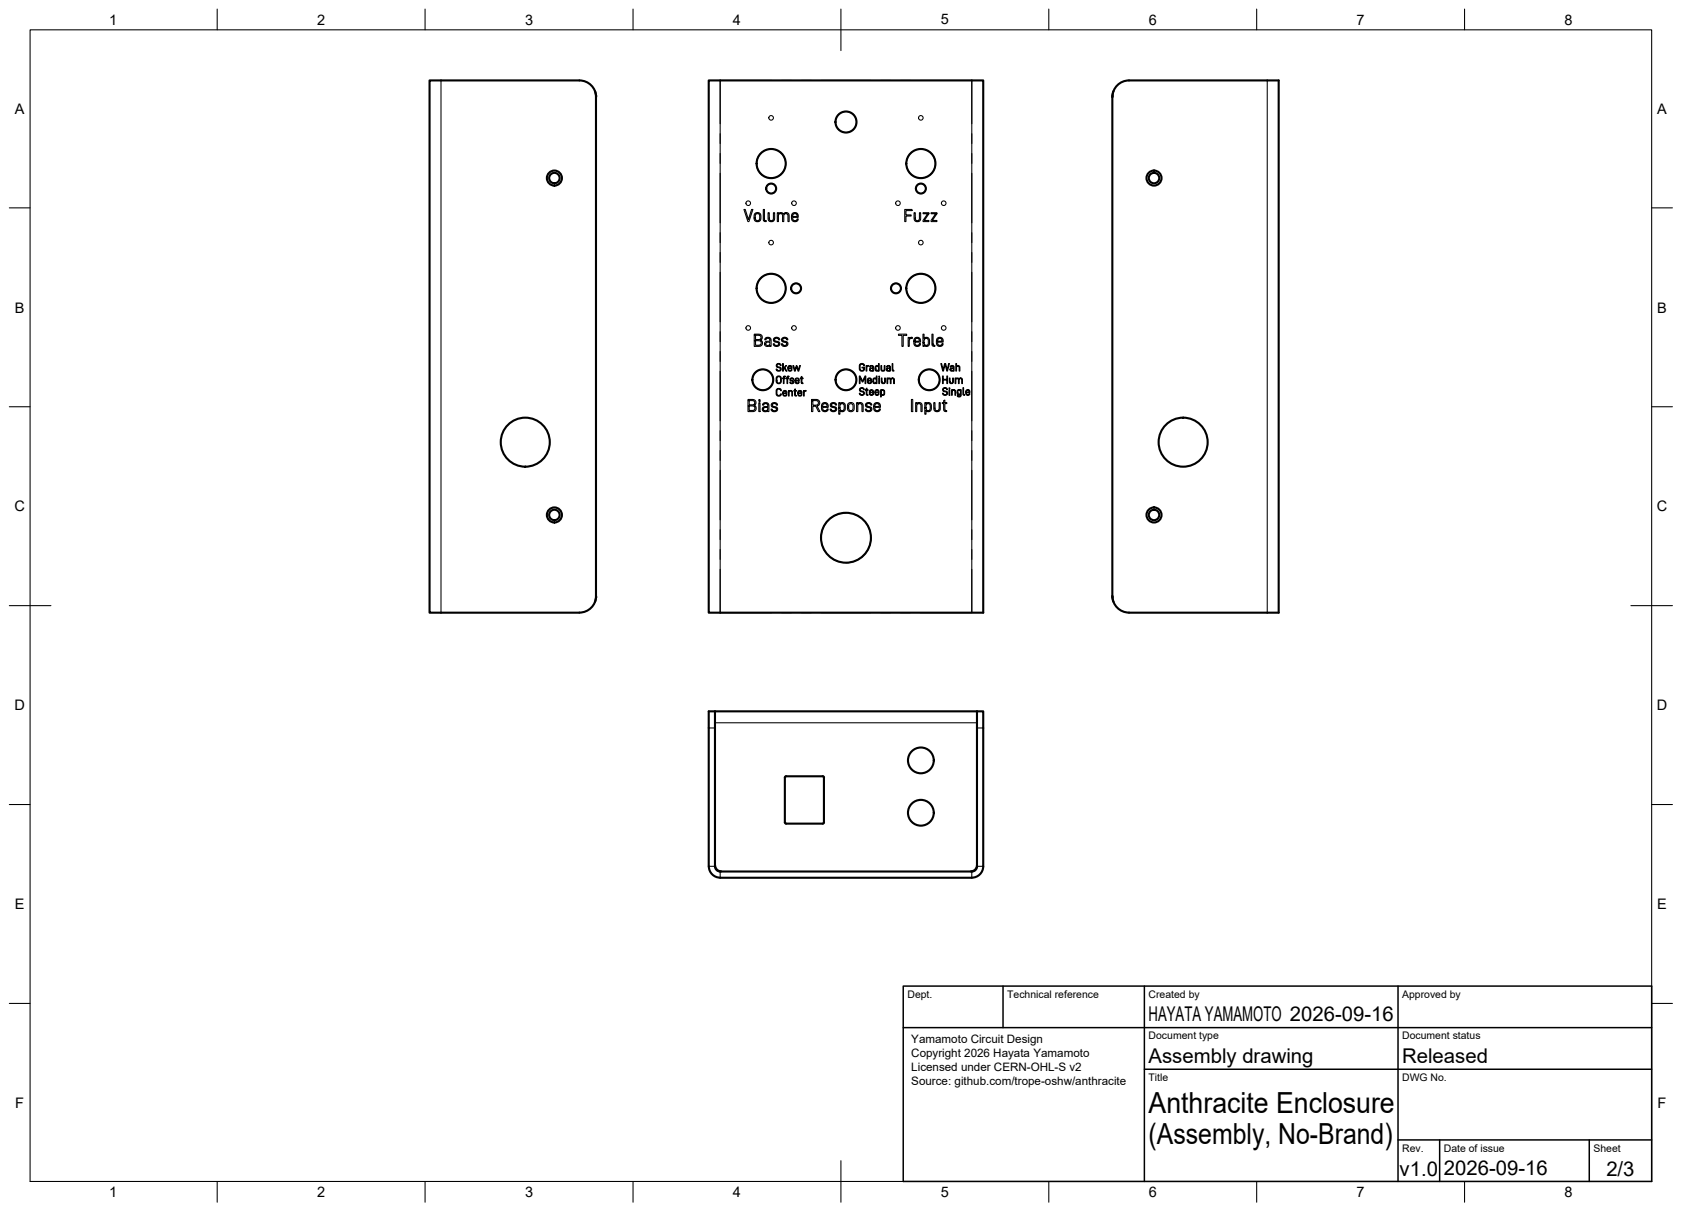
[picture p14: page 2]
Title; DWG No.; Anthracite Enclosure

Dept. | Technical reference | Created by HAYATA YAMAMOTO 2026-09-16 | Approved by

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

Document type Assembly drawing | Document status Released

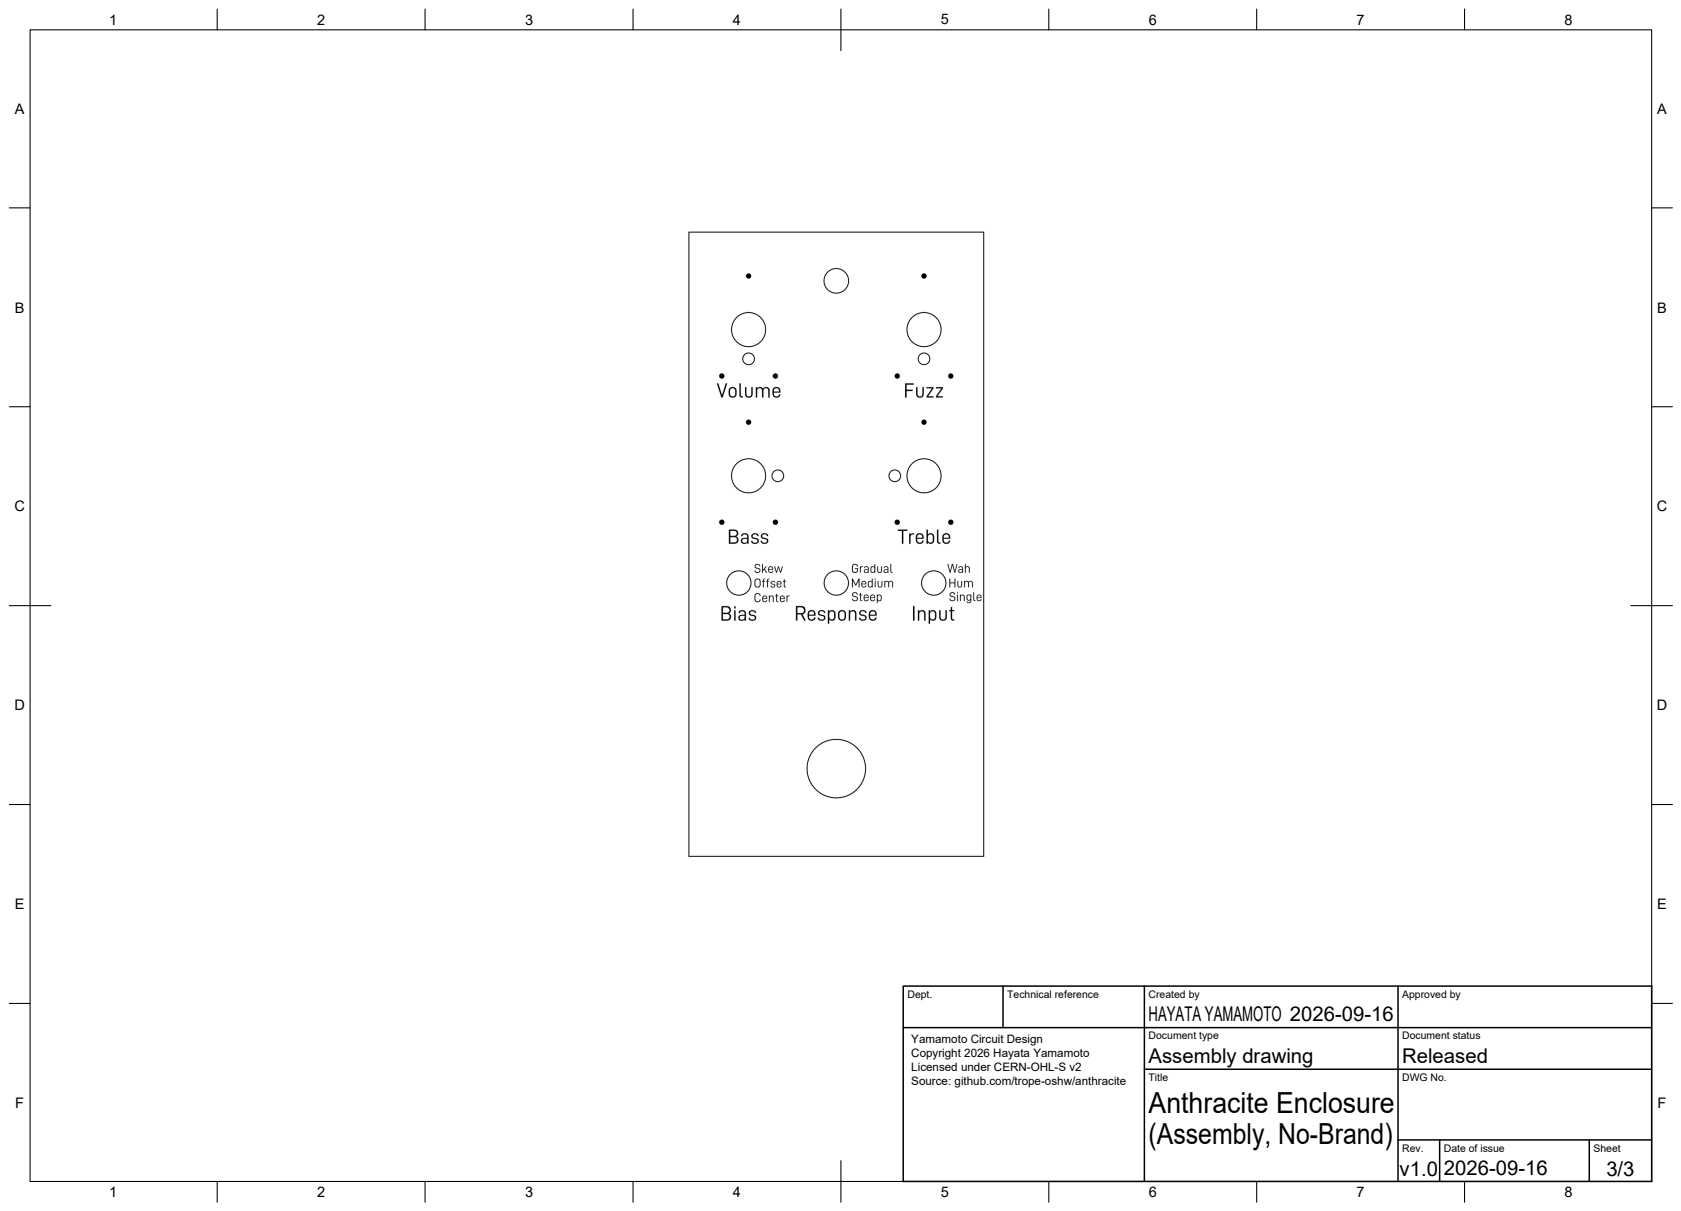
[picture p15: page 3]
Title; DWG No.; Anthracite Enclosure

Dept. | Technical reference | Created by HAYATA YAMAMOTO 2026-09-16 | Approved by

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

Document type Assembly drawing | Document status Released

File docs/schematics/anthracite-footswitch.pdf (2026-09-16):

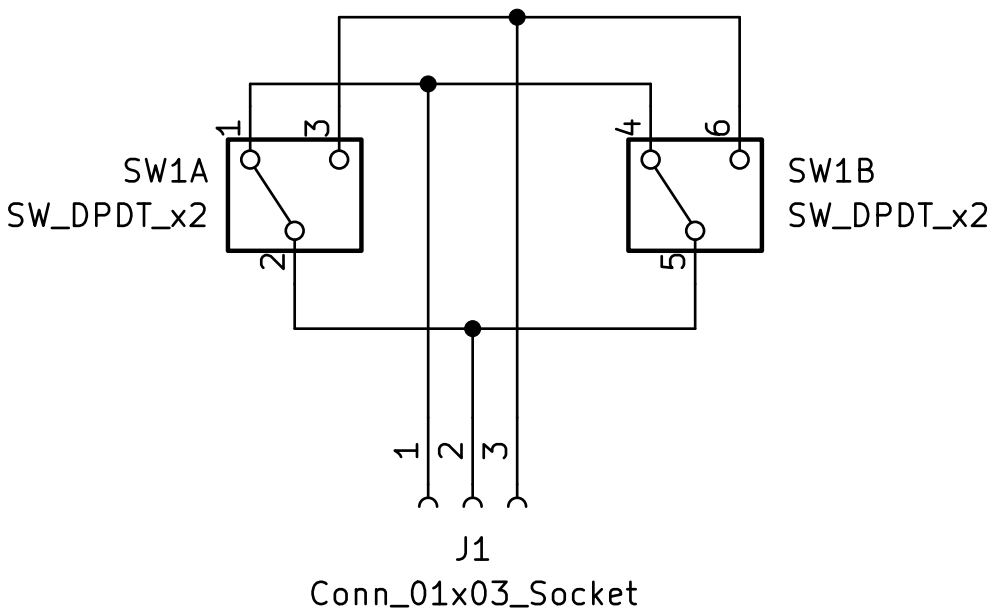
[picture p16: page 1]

Source: github.com/trope-oshw/anthracite
Licensed under CERN-OHL-S v2
Copyright 2026 Hayata Yamamoto
Yamamoto Circuit Design
Sheet: /
File: anthracite-footswitch.kicad_sch
Title: Anthracite Schematic (Footswitch)

Size: A4 | Rev: v1.0
KiCad E.D.A. 10.0.1 | Id: 1/1

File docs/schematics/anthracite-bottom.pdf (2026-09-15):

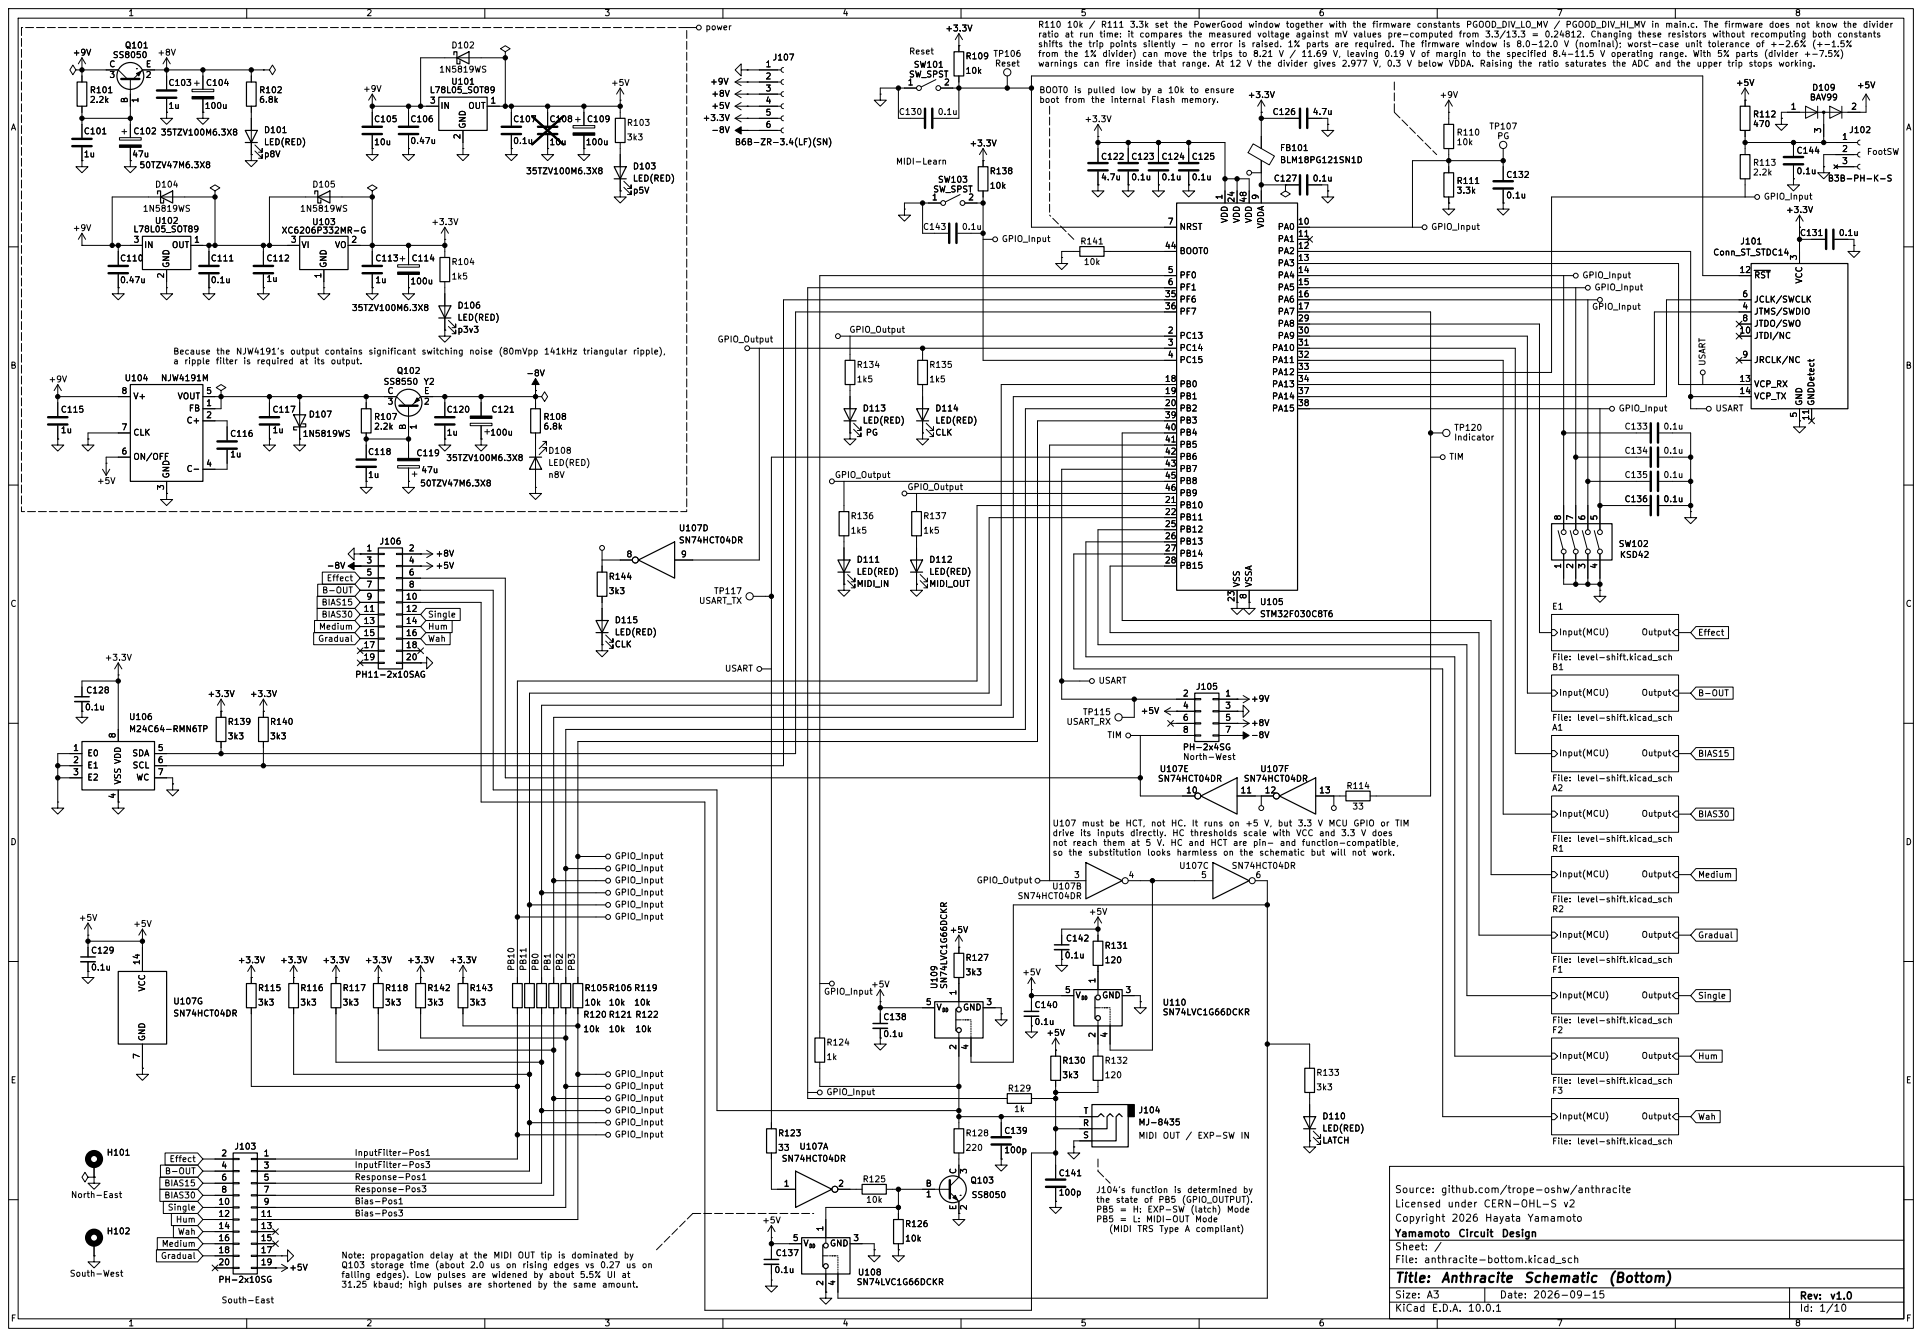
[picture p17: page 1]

R110 10k / R111 3.3k set the PowerGood window together with the firmware constants PGOOD_DIV_LO_MV / PGOOD_DIV_HI_MV in main.c. The firmware does not know the divider
ratio at run time: it compares the measured voltage against mV values pre-computed from 3.3/13.3 = 0.24812. Changing these resistors without recomputing both constants
shifts the trip points silently - no error is raised. 1% parts are required. The firmware window is 8.0-12.0 V (nominal); worst-case unit tolerance of +-2.6% (+-1.5%
from the 1% divider) can move the trips to 8.21 V / 11.69 V, leaving 0.19 V of margin to the specified 8.4-11.5 V operating range. With 5% parts (divider +-7.5%)

warnings can fire inside that range. At 12 V the divider gives 2.977 V, 0.3 V below VDDA. Raising the ratio saturates the ADC and the upper trip stops working.

1 PC13 2 PC14 3 PC15 4 PF0 5 PF1 6 NRST 7 VSSA 8 VDDA 9 PA0 10 PA1 11 PA2 12 PA3 13 PA4 14 PA5 15 PA6 16 PA7 17 PB0 18 PB1 19 PB2 20 PB10 21 PB11 22 VSS 23 VDD 24 PB12 25 PB13 26 PB14 27 PB15 28 PA8 29 PA9 30 PA10 31 PA11 32 PA12 33 PA13 34 PF6 35 PF7 36 PA14 37 PA15 38 PB3 39 PB4 40 PB5 41 PB6 42 PB7 43 BOOT0 44 PB8 45 PB9 46 VDD 48 U105

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

GPIO_Output

Single B-OUT BIAS15 BIAS30 Gradual Medium

North-West U107 must be HCT, not HC. It runs on +5 V, but 3.3 V MCU GPIO or TIM

drive its inputs directly. HC thresholds scale with VCC and 3.3 V does not reach them at 5 V. HC and HCT are pin- and function-compatible, so the substitution looks harmless on the schematic but will not work. MIDI OUT / EXP-SW IN

Source: github.com/trope-oshw/anthracite
Licensed under CERN-OHL-S v2
Copyright 2026 Hayata Yamamoto
Yamamoto Circuit Design
Sheet: /
File: anthracite-bottom.kicad_sch
Title: Anthracite Schematic (Bottom)

the state of PB5 (GPIO_OUTPUT). PB5 = H: EXP-SW (latch) Mode PB5 = L: MIDI-OUT Mode

(MIDI TRS Type A compliant)

falling edges). Low pulses are widened by about 5.5% UI at 31.25 kbaud; high pulses are shortened by the same amount.

Size: A3 | Rev: v1.0 | F Date: 2026-09-15
KiCad E.D.A. 10.0.1 | Id: 1/10

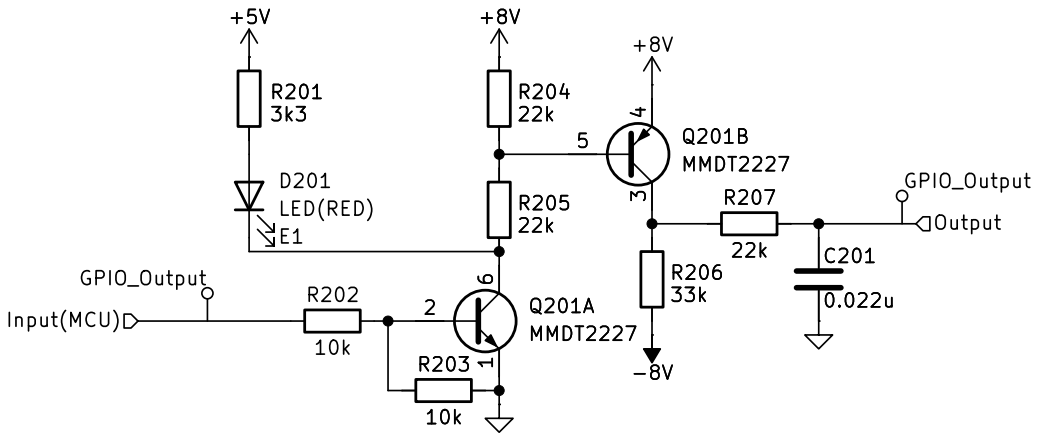
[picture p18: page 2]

Source: github.com/trope-oshw/anthracite
Licensed under CERN-OHL-S v2
Copyright 2026 Hayata Yamamoto
Yamamoto Circuit Design
Sheet: /E1/
File: level-shift.kicad_sch
Title: Anthracite Schematic (Bottom)

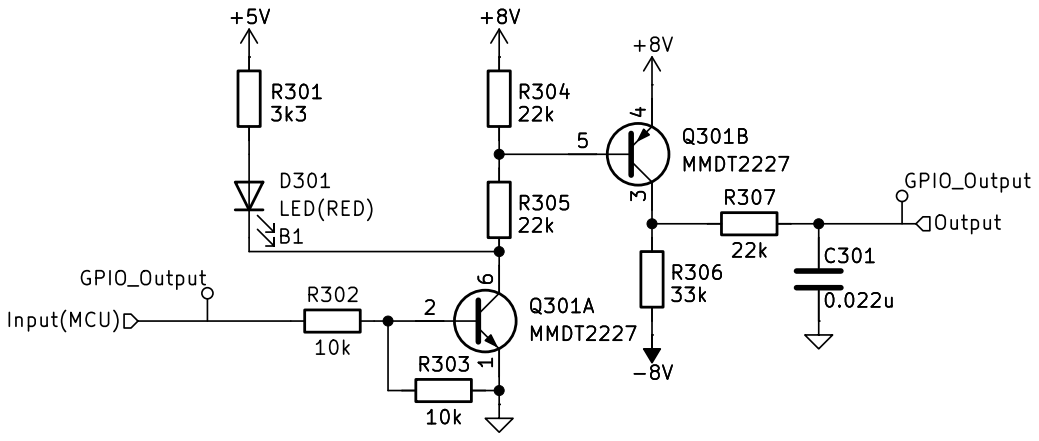
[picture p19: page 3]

Source: github.com/trope-oshw/anthracite
Licensed under CERN-OHL-S v2
Copyright 2026 Hayata Yamamoto
Yamamoto Circuit Design
Sheet: /B1/
File: level-shift.kicad_sch
Title: Anthracite Schematic (Bottom)

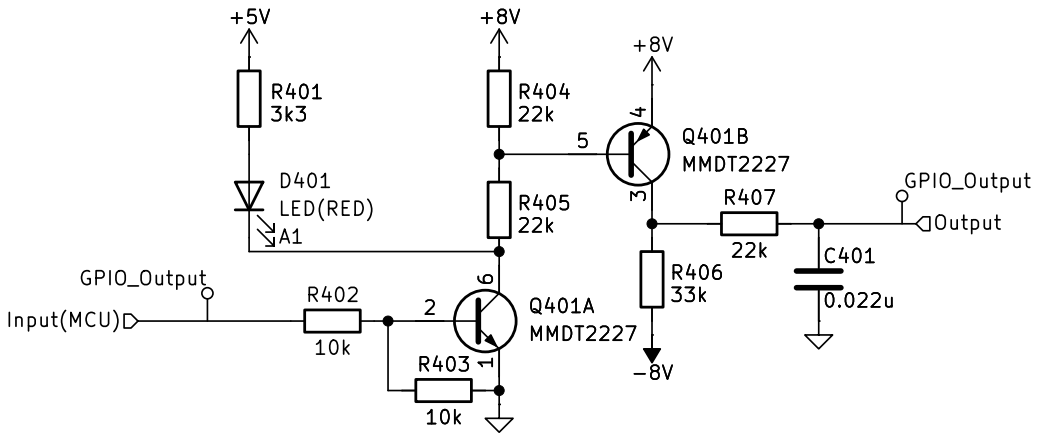
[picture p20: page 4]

Source: github.com/trope-oshw/anthracite
Licensed under CERN-OHL-S v2
Copyright 2026 Hayata Yamamoto
Yamamoto Circuit Design
Sheet: /A1/
File: level-shift.kicad_sch
Title: Anthracite Schematic (Bottom)

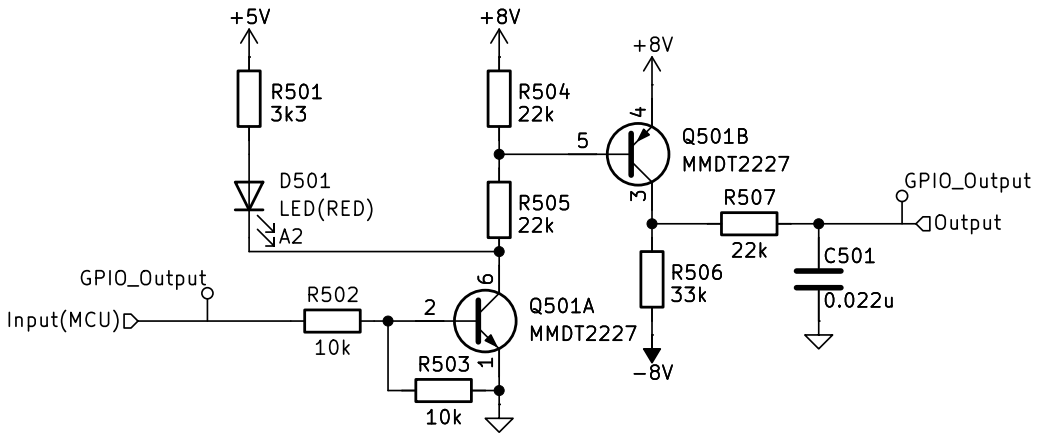
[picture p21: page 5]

Source: github.com/trope-oshw/anthracite
Licensed under CERN-OHL-S v2
Copyright 2026 Hayata Yamamoto
Yamamoto Circuit Design
Sheet: /A2/
File: level-shift.kicad_sch
Title: Anthracite Schematic (Bottom)

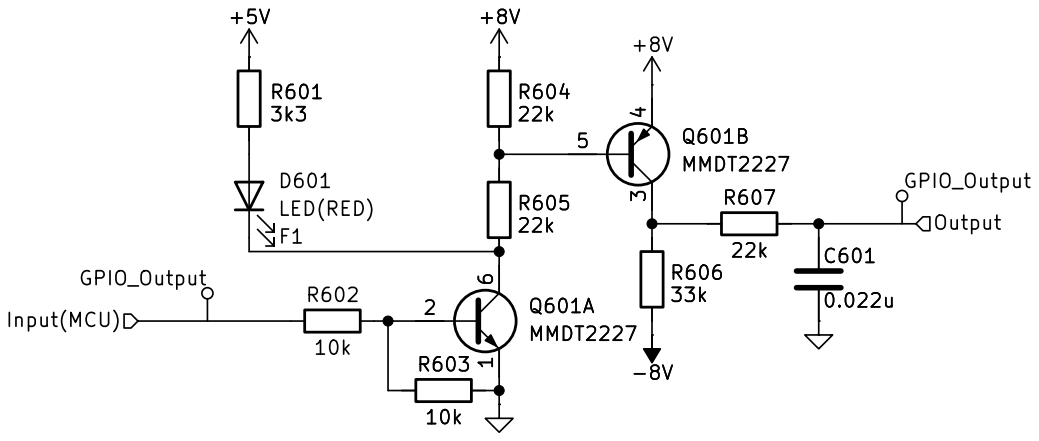
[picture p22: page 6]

Source: github.com/trope-oshw/anthracite
Licensed under CERN-OHL-S v2
Copyright 2026 Hayata Yamamoto
Yamamoto Circuit Design
Sheet: /F1/
File: level-shift.kicad_sch
Title: Anthracite Schematic (Bottom)

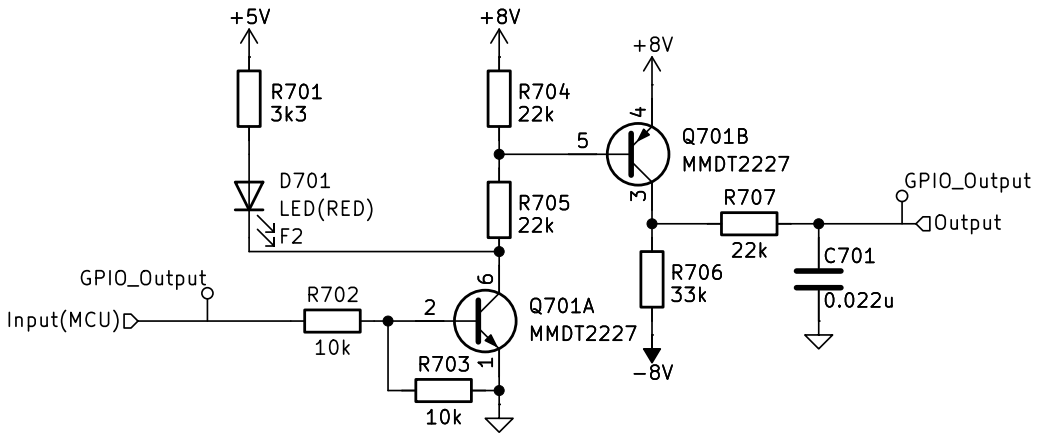
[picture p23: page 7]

Source: github.com/trope-oshw/anthracite
Licensed under CERN-OHL-S v2
Copyright 2026 Hayata Yamamoto
Yamamoto Circuit Design
Sheet: /F2/
File: level-shift.kicad_sch
Title: Anthracite Schematic (Bottom)

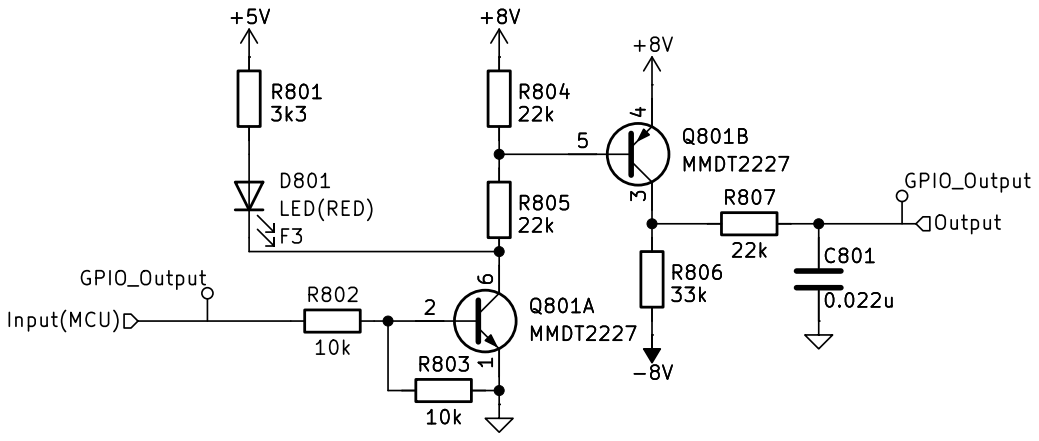
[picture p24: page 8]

Source: github.com/trope-oshw/anthracite
Licensed under CERN-OHL-S v2
Copyright 2026 Hayata Yamamoto
Yamamoto Circuit Design
Sheet: /F3/
File: level-shift.kicad_sch
Title: Anthracite Schematic (Bottom)


Source: github.com/trope-oshw/anthracite
Licensed under CERN-OHL-S v2
Copyright 2026 Hayata Yamamoto
Yamamoto Circuit Design
Sheet: /R1/
File: level-shift.kicad_sch
Title: Anthracite Schematic (Bottom)


Source: github.com/trope-oshw/anthracite
Licensed under CERN-OHL-S v2
Copyright 2026 Hayata Yamamoto
Yamamoto Circuit Design
Sheet: /R2/
File: level-shift.kicad_sch
Title: Anthracite Schematic (Bottom)

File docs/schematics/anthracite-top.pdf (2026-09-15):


These load networks form an LPF with the pickup inductance. Reducing the guitar volume lowers the Q factor, giving a gentler high-frequency roll-off.

R90 = 15k and R36 = 3.3k were chosen together. R90 sets the pop

Bypass Pre-Volume Single
J5 NMJ6HCD3R

dip through Ig * (Rd || Rs). Lowering R90 220k -> 15k with matched R37/R85 (100k/220k -> 47k/47k) cut pop by 16.7-19.4 dB; R90's own share was not measured. Raising R90 gives some back. R36 = 3.3k restores the negative swing lost to the low R90. At 10k, R36 costs bypass THD (0.0286% -> 0.0398%, 1 Vpp, 1 kHz) and clipping headroom (11.5 -> about 8 Vpp, 100 Hz). For more low

end, change C49 to 2.2u instead of raising these resistors. Q12/Q13 hFE: the built units use parts selected to the windows marked between Q12 and Q13

R37: see note below. R38: see Rg note below R86.

(measured at I_B = 1.00 uA, V_CE = 5 V). The DC operating

point (I_C13 = 300 uA,
I_C12 = 30 uA) is set by the R58 feedback. In simulation, hFE values of 340-430 change

I_C13 by less than 0.5% and the gain by less than 0.6 dB, mostly

(Headroom ratio = V(C13)-V(E13) : VCC-V(C13)) 8.50k C35 (100p across R58) adds high-frequency feedback as a precaution. Removing it made no noticeable change in

R90: see note near R36. R37 and R85 must be the same value. The DC step between bypass and
effect is dV = Ig * [(R85||R90) - (R37||R90)], so what matters is
that they match, not the absolute value. Do not change one without
the other. 1% parts are enough: a 2% mismatch adds under 5 uV, far below the tens of uV measured with matched parts.

Using low-leakage capacitors helps reduce switching pop noise. Film capacitors (e.g. PMLCAP) are preferred for C23, C47, and C49 over aluminium electrolytic capacitors.

If you omit it, check for oscillation at all Fuzz and Bias settings. To minimize pop, the JFET ahead of the high-gain fuzz stage (Q9) turns on before, and turns off after, the effect output switch Q17. The gate RC cells are asymmetric on purpose; do not make them

stage adds up to 5x (+14 dB) of treble boost, so peaks can reach the +-8 V rails of U4. Use a rail-to-rail output op-amp. Volume(A1)
TLV9362IDR

turn-off 1Meg*0.1u = 100 ms Q17 (asymmetric the other way): turn-on (220k+470k)*0.1u = 69 ms

reference. R7 22k sits between ADJ and GND; R8 + R9 = 6.2k sits between OUT and ADJ. Vout = 5.65 V. Applying the ordinary divider formula to this gives 1.59 V, which is wrong. (Measured VCC is 5.599 V, which reflects the voltage drop across R11.) This network interacts with the input

impedance of the fuzz stage and attenuates the input signal.

It affects the amount of guitar volume

frequency response or stability on the prototype (no
data kept); the high-frequency roll-off is set by C33.

Lowering it increases pop. Raising it from 100M to 200M reduced pop by 4.9-6.3 dB (measured); halving it is expected to cost about as much. See ERRATA.md.

MIC5205 defines Vref as Vout - Vadj, not as the usual bottom-leg

Vout-Vadj=1.242V Rbtm=22k Rtop=6.2k

MIDI IN (MIDI TRS Type A compliant)

Note the PL9823-F5 pinout. In the datasheet package drawing (leads down), the leads run 4(DIN), 3(VDD), 1(GND), 2(DO) from left to right. The symbol and the standard 4-pin THT LED footprint number them

To keep MIDI IN edges sharp, use a photocoupler with a response time of 1 us or less.

Source: github.com/trope-oshw/anthracite
Licensed under CERN-OHL-S v2
Copyright 2026 Hayata Yamamoto
Yamamoto Circuit Design
Sheet: /
File: anthracite-top.kicad_sch
Title: Anthracite Schematic (Top)

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

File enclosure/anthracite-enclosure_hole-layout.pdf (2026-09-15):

Dept.; Technical reference; Created by; Approved by; Document type; Document status; Title; DWG No.; Rev.; Date of issue; Sheet; Hole layout drawing; Released; (Hole Layout); Anthracite Enclosure; HAYATA YAMAMOTO ²².99 10; Ø5.05 THRU; 4x Ø7 THRU; 4x Ø2.4 THRU; 3x Ø5 THRU; Ø12 THRU; 2x Ø3.6 THRU; Ø11.8 THRU

Yamamoto Circuit Design
Copyright 2026 Hayata Yamamoto
Licensed under CERN-OHL-S v2
Source: github.com/trope-oshw/anthracite

Dept.; Technical reference; Created by; Approved by; Document type; Document status; Title; DWG No.; Rev.; Date of issue; Sheet; Hole layout drawing; Released; (Hole Layout); Anthracite Enclosure; HAYATA YAMAMOTO; M3x0.5 TAP2.0mm DEEP; M3x0.5 TAP2.0mm DEEP Ø6.2 x2

BURRING/PIERCE-EXTRUSION PROCESS:
Pilot hole dia. before tapping: Ø2.5
Extruded height (H): 2.5 min.
H tolerance: ±0.1
Effective thread depth: 2.0 min.
All dimensions in mm.

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

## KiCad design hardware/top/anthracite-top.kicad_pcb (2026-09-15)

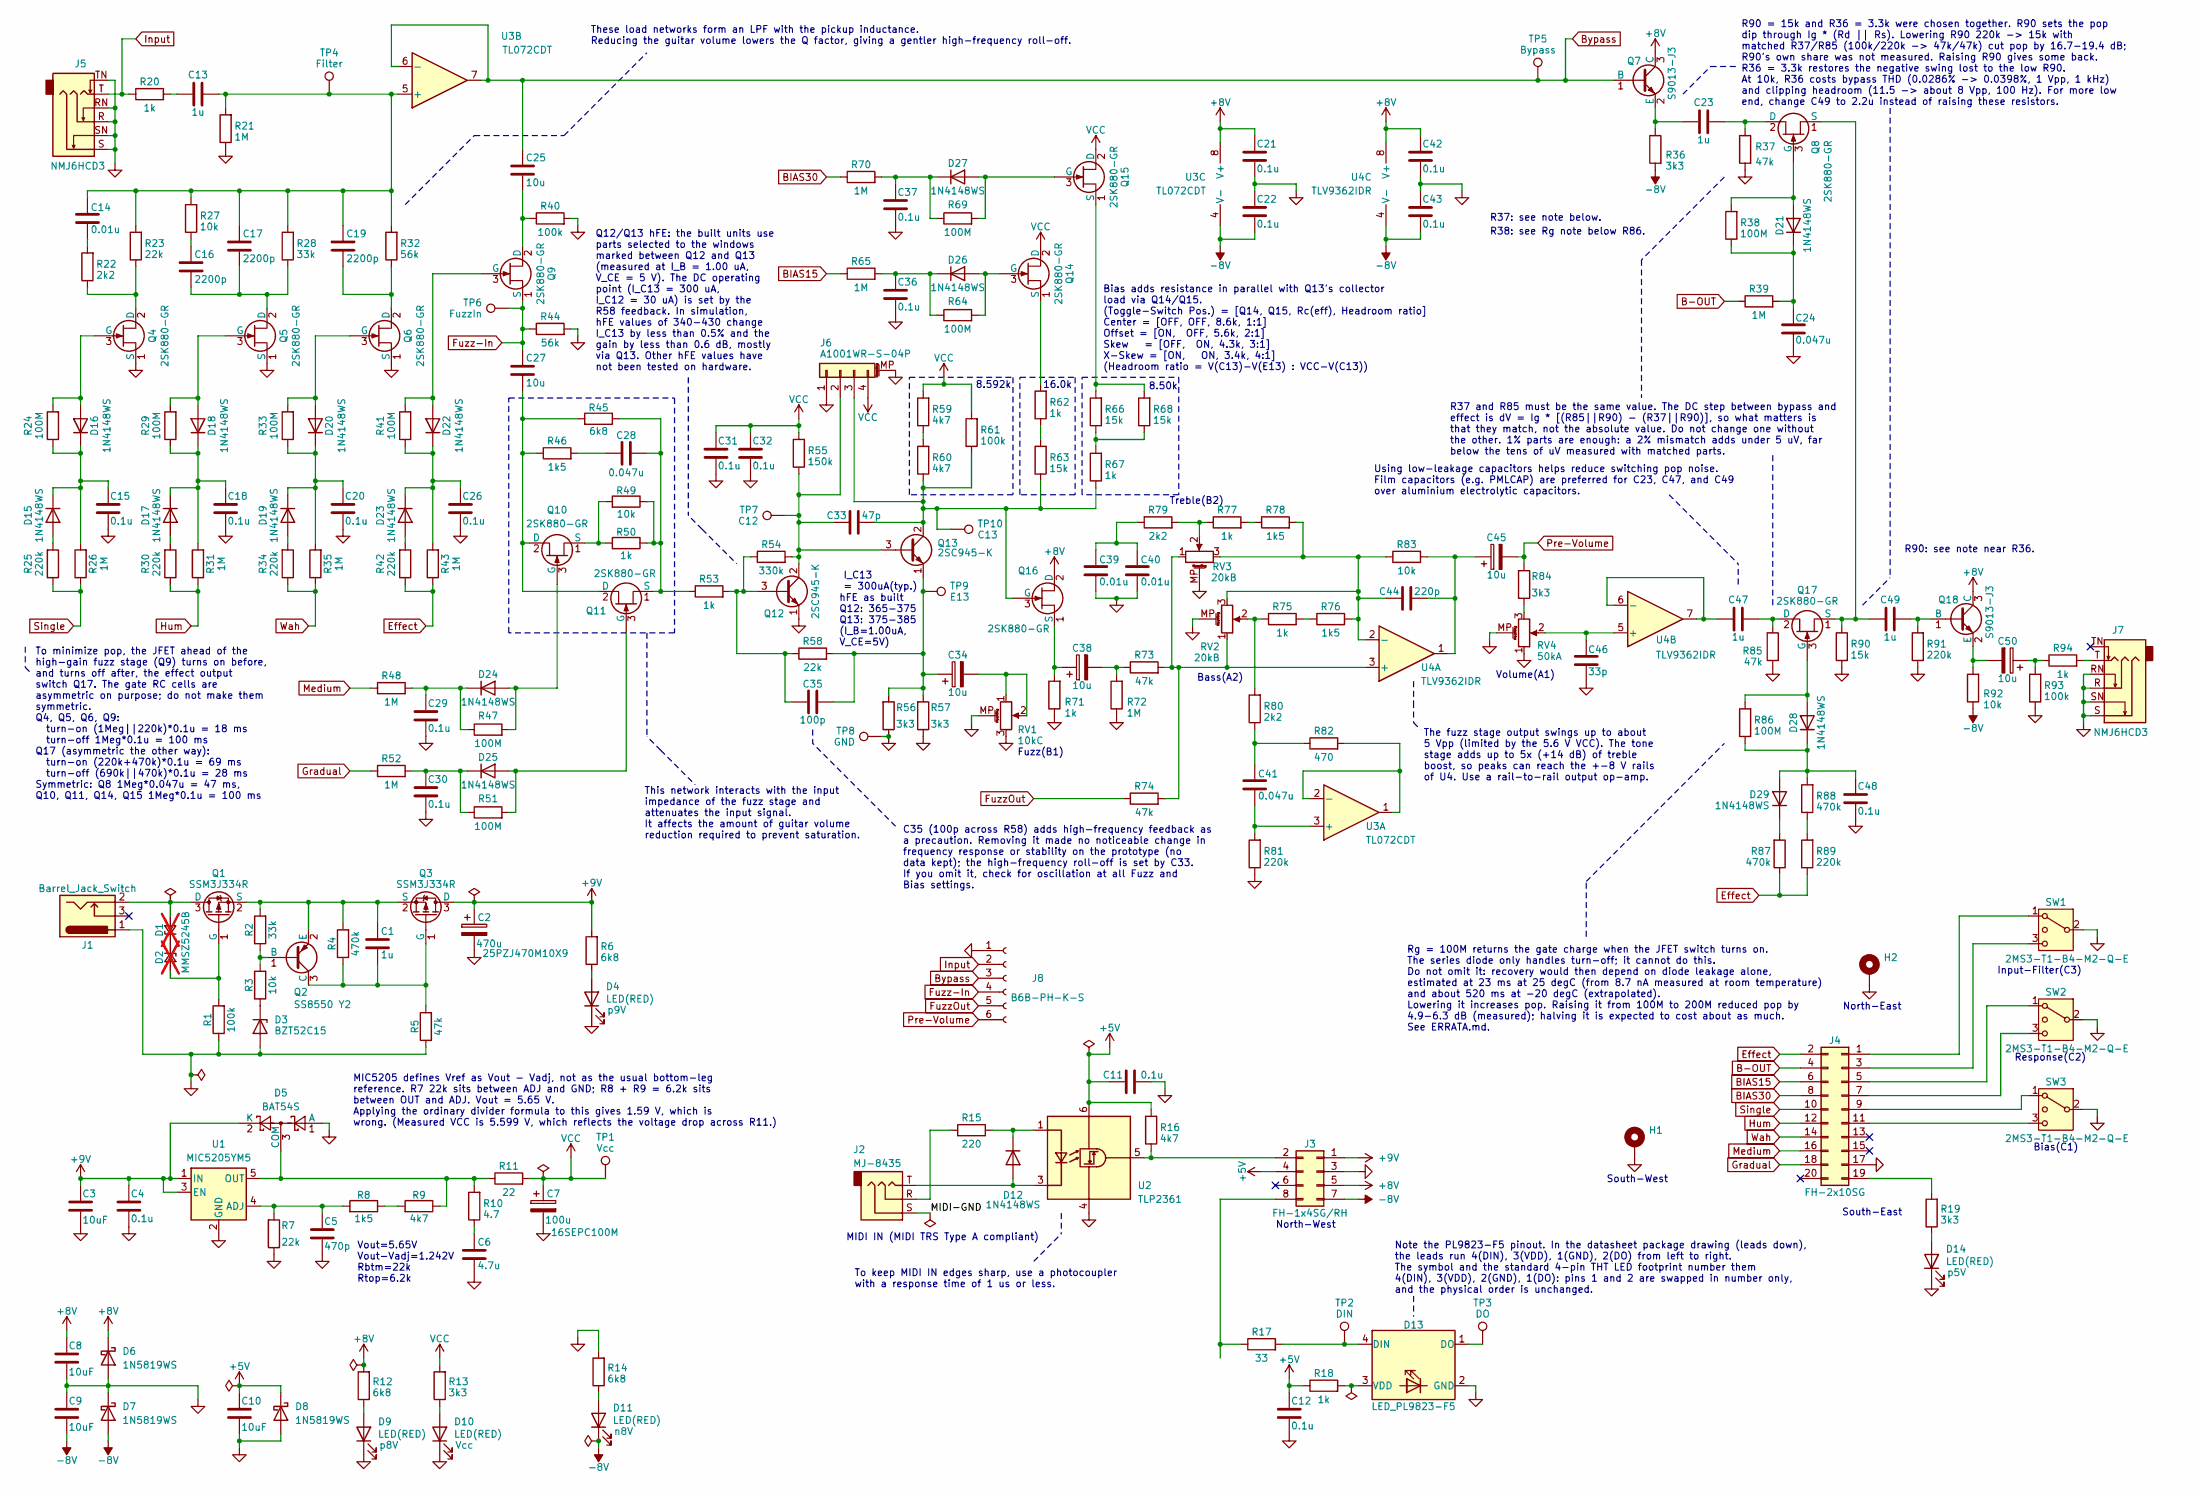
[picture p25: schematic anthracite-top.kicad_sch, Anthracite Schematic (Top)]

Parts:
C1: 1u; C_0805_2012Metric; Tolerance 10%; Voltage 50V; MPN CL21B105KBFNNNE; LCSC C28323
C2: 470u; CP_Radial_D10.0mm_P5.00mm; Tolerance 20%; Voltage 25V; MPN 25PZJ470M10X9
C3, C8, C9, C10: 10uF; C_0805_2012Metric; Tolerance 10%; Voltage 25V; MPN CL21A106KAYNNNE; LCSC C15850
C4, C11, C12, C15, C18, C20, C21, C22, C26, C29, C30, C31, C32, C36, C37, C42, C43, C48: 0.1u; C_0603_1608Metric; Tolerance 10%; Voltage 50V; LCSC C14663
C5: 470p; C_0603_1608Metric; Tolerance 10%; Voltage 50V; LCSC C1620
C6: 4.7u; C_0805_2012Metric; Tolerance 10%; Voltage 25V; LCSC C1779
C7: 100u; CP_Radial_D6.3mm_P2.50mm; Tolerance 20%; Voltage 16V; MPN 16SEPC100M
C13, C23, C47, C49: 1u; C_1206_3216Metric_Pad1.33x1.80mm_HandSolder; Tolerance 20%; Voltage 25V; MPN 25NS105MA23216
C14, C39, C40: 0.01u; C_0603_1608Metric; Tolerance 5%; Voltage 50V; MPN GRM1885C1H103JA01D; LCSC C85973
C16, C17, C19: 2200p; C_0805_2012Metric; Tolerance 5%; Voltage 50V; LCSC C28260
C24: 0.047u; C_0805_2012Metric; Tolerance 10%; Voltage 50V; LCSC C53134
C25, C27: 10u; C_1812_4532Metric_Pad1.57x3.40mm_HandSolder; Tolerance 20%; Voltage 16V; MPN 16MU106MC44532
C28, C41: 0.047u; C_1206_3216Metric_Pad1.33x1.80mm_HandSolder; Tolerance 5%; Voltage 50V; MPN GRM31M5C1H473JA01L; LCSC C21812
C33: 47p; C_0603_1608Metric; Tolerance 5%; Voltage 50V; LCSC C1671
C34, C38, C45, C50: 10u; CP_Elec_4x5.4; Tolerance 20%; Voltage 16V; MPN EEE1CA100SR; LCSC C178496
C35: 100p; C_0603_1608Metric; Tolerance 5%; Voltage 50V; LCSC C14858
C44: 220p; C_0603_1608Metric; Tolerance 10%; Voltage 50V; LCSC C1603
C46: 33p; C_0603_1608Metric; Tolerance 5%; Voltage 50V; LCSC C1663
D1, D2: MMSZ5245B; D_SOD-123; MPN MMSZ5245B; LCSC C19077428; not fitted
D3: BZT52C15; D_SOD-123; MPN BZT52C15; LCSC C19077412
D4, D9, D10, D11, D14: LED(RED); D_0603_1608Metric_Name; MPN KT-0603R; LCSC C2286
D5: BAT54S; SOT-23; MPN BAT54S; LCSC C7420333
D6, D7, D8: 1N5819WS; D_SOD-323; MPN 1N5819WS; LCSC C191023
D12, D15, D16, D17, D18, D19, D20, D21, D22, D23, D24, D25, D26, D27, D28, D29: 1N4148WS; D_SOD-323; MPN 1N4148WS; LCSC C2128
D13: LED_PL9823-F5; LED_D5.0mm-4_RGB_Wide_Pins; MPN PL9823-F5
H1, H2: MountingHole_Pad; MountingHole_3.2mm_M3_DIN965_Pad
J1: Barrel_Jack_Switch; MJ-179PH_Edge; MPN MJ-179PH
J2: MJ-8435; MPN MJ-8435
J3: FH-1x4SG/RH; PinSocket_2x04_P2.54mm_Vertical; MPN FH-1x4SG/RH x2
J4: FH-2x10SG; PinSocket_2x10_P2.54mm_Vertical; MPN FH-2x10SG
J5, J7: NMJ6HCD3; Jack_6.35mm_Neutrik_NMJ6HCD3_Horizontal; MPN NMJ6HCD3
J6: A1001WR-S-04P; JST_SH_SM04B-SRSS-TB_1x04-1MP_P1.00mm_Horizontal; MPN A1001WR-S-04P
J8: B6B-PH-K-S; JST_PH_B6B-PH-K_1x06_P2.00mm_Vertical; MPN B6B-PH-K-S(LF)(SN)
Q1, Q3: SSM3J334R; SOT-23; MPN SSM3J334R; LCSC C396017
Q2: SS8550 Y2; SOT-23; MPN SS8550 Y2(RANGE:200-350); LCSC C8542
Q4, Q5, Q6, Q8, Q9, Q10, Q11, Q14, Q15, Q16, Q17: 2SK880-GR; SOT-323_SC-70; MPN 2SK880-GR; LCSC C7469759
Q7, Q18: S9013-J3; SOT-23; MPN S9013 J3(RANGE:200-350); LCSC C6749
Q12, Q13: 2SC945-K; TO-92_Inline_Wide; MPN 2SC945-K
R1, R40, R61, R93: 100k; R_0603_1608Metric; Tolerance 1%; LCSC C25803
R2, R28: 33k; R_0603_1608Metric; Tolerance 1%; LCSC C4216
R3, R27, R49, R83, R92: 10k; R_0603_1608Metric; Tolerance 1%; LCSC C25804
R4, R87, R88: 470k; R_0603_1608Metric; Tolerance 1%; LCSC C23178
R5, R37, R73, R74, R85: 47k; R_0603_1608Metric; Tolerance 1%; LCSC C25819
R6, R12, R14, R45: 6k8; R_0603_1608Metric; Tolerance 1%; LCSC C23212
R7, R23, R58: 22k; R_0603_1608Metric; Tolerance 1%; LCSC C31850
R8, R46, R76, R78: 1k5; R_0603_1608Metric; Tolerance 1%; LCSC C22843
R9, R16, R59, R60: 4k7; R_0603_1608Metric; Tolerance 1%; LCSC C23162
R10: 4.7; R_0603_1608Metric; Tolerance 1%; LCSC C23164
R11: 22; R_0603_1608Metric; Tolerance 1%; LCSC C23345
R13, R19, R36, R56, R57, R84: 3k3; R_0603_1608Metric; Tolerance 1%; LCSC C22978
R15: 220; R_0603_1608Metric; Tolerance 1%; LCSC C22962
R17: 33; R_0603_1608Metric; Tolerance 1%; LCSC C23140
R18, R20, R50, R53, R62, R67, R71, R75, R77, R94: 1k; R_0603_1608Metric; Tolerance 1%; LCSC C21190
R21, R26, R31, R35, R39, R43, R48, R52, R65, R70, R72: 1M; R_0603_1608Metric; Tolerance 1%; LCSC C22935
R22, R79, R80: 2k2; R_0603_1608Metric; Tolerance 1%; LCSC C4190
R24, R29, R33, R38, R41, R47, R51, R64, R69, R86: 100M; R_0603_1608Metric; Tolerance 5%; LCSC C422892
R25, R30, R34, R42, R81, R89, R91: 220k; R_0603_1608Metric; Tolerance 1%; LCSC C22961
R32, R44: 56k; R_0603_1608Metric; Tolerance 1%; LCSC C23206
R54: 330k; R_0603_1608Metric; Tolerance 1%; LCSC C23137
R55: 150k; R_0603_1608Metric; Tolerance 1%; LCSC C22807
R63, R66, R68, R90: 15k; R_0603_1608Metric; Tolerance 1%; LCSC C22809
R82: 470; R_0603_1608Metric; Tolerance 1%; LCSC C23179
RV1: 10kC; Potentiometer_Alpha_RD901F-40-00D_Single_Vertical_CenterAnk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; MPN RD901F-40-15R1-C10K
RV2, RV3: 20kB; Potentiometer_Alpha_RD901F-40-00D_Single_Vertical_CenterAnk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; MPN RD901F-40-15R1-B20K
RV4: 50kA; Potentiometer_Alpha_RD901F-40-00D_Single_Vertical_CenterAnk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; MPN RD901F-40-15R1-A50K
SW1, SW2, SW3: 2MS3-T1-B4-M2-Q-E; Toggle_SW_mini_2MS1-T1-B4-M2-Q-E; MPN 2MS3-T1-B4-M2-Q-E
TP1, TP2, TP3, TP4, TP5, TP6, TP7, TP8, TP9, TP10: TestPoint; TestPoint_Pad_1.5x1.5mm_Label
U1: MIC5205YM5; SOT-23-5; MPN MIC5205YM5; LCSC C412820
U2: TLP2361; SO-5-6_4.55x3.7mm_P1.27mm; MPN TLP2361; LCSC C107626
U3: TL072CDT; SOIC-8_3.9x4.9mm_P1.27mm; MPN TL072CDT; LCSC C6961
U4: TLV9362IDR; SOIC-8_3.9x4.9mm_P1.27mm; MPN TLV9362IDR; LCSC C4367884

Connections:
+5V: C10.1, C11.1, C12.1, D8.1 (K), J3.4, R16.2, R18.1, U2.6 (VDD)
+8V: C8.1, C21.1, C42.1, D6.1 (K), J3.5, Q7.3 (C), Q16.2 (D), Q18.3 (C), R12.2, U3.8 (V+), U4.8 (V+)
+9V: C2.1, C3.1, C4.1, D5.2 (K), J3.1, Q3.3 (D), R6.2, U1.1 (IN), U1.3 (EN)
-8V: C9.2, C22.2, C43.2, D7.2 (A), D11.1 (K), J3.7, R36.1, R92.1, U3.4 (V-), U4.4 (V-)
/MIDI-GND: J2.S
B-OUT: J4.4, R39.1
BIAS15: J4.6, R65.1
BIAS30: J4.8, R70.1
Bypass: C25.2, J8.3, Q7.1 (B), TP5.1 (1_1), U3.6 (-), U3.7
Effect: J4.2, R42.1, R43.1, R87.1, R89.1
Fuzz-In: C27.2, J8.4, Q9.1 (S), R44.1, TP6.1 (1_1)
FuzzOut: J8.5, R74.1
GNDPWR: C2.2, C3.2, C4.2, C5.2, C6.2, C7.2, C8.2, C9.1, C10.2, C11.2, C12.2, C15.2, C18.2, C20.2, C21.2, C22.1, C24.1, C26.2, C29.2, C30.2, C31.2, C32.2, C36.2, C37.2, C39.2, C40.2, C42.2, C43.1, C46.2, C48.2, D3.2 (A), D4.1 (K), D5.1 (A), D6.2 (A), D7.1 (K), D8.2 (A), D9.1 (K), D10.1 (K), D13.2 (GND), D14.1 (K), H1.1 (1_1), H2.1 (1_1), J1.1, J3.3, J4.17, J5.R, J5.RN, J5.S, J5.SN, J5.TN, J6.1, J6.MP (MountPin), J7.R, J7.RN, J7.S, J7.SN, J8.1, Q4.1 (S), Q5.1 (S), Q6.1 (S), Q12.1 (E), R1.1, R5.1, R7.2, R14.2, R21.1, R37.1, R40.2, R44.2, R56.2, R57.2, R71.1, R72.1, R81.1, R85.1, R90.1, R91.1, R93.1, RV1.3, RV1.MP (MountPin), RV2.MP (MountPin), RV3.MP (MountPin), RV4.1, RV4.MP (MountPin), SW1.2 (3), SW2.2 (3), SW3.2 (3), TP8.1 (1_1), U1.2 (GND), U2.4 (GND)
Gradual: J4.18, R52.1
Hum: J4.12, R30.1, R31.1
Input: J5.T, J8.2, R20.1
Medium: J4.16, R48.1
unnamed: C6.1, R10.1
unnamed: C13.1, R20.2
unnamed: C14.2, R22.2
unnamed: C16.1, R27.1
unnamed: C28.1, R46.2
unnamed: C34.2, RV1.1, RV1.2
unnamed: C38.2, R72.2, R73.1
unnamed: C39.1, C40.1, R79.1
unnamed: C41.1, R80.1, R82.1
unnamed: C44.2, C45.1, R83.2, U4.1
unnamed: C50.1, R93.2, R94.1
unnamed: D1.2 (A), J1.2, Q1.3 (D)
unnamed: D1.1 (K), D2.1 (K)
unnamed: D2.2 (A), Q1.1 (G), R1.2
unnamed: D3.1 (K), R3.1
unnamed: D4.2 (A), R6.1
unnamed: D5.3 (COM), R9.2, R10.2, R11.1, U1.5 (OUT)
unnamed: D9.2 (A), R12.1
unnamed: D10.2 (A), R13.1
unnamed: D11.2 (A), R14.1
unnamed: D12.2 (A), J2.T, U2.3 (K)
unnamed: D12.1 (K), R15.2, U2.1 (A)
unnamed: D13.4 (DIN), R17.2, TP2.1 (1_1)
unnamed: D13.1 (DO), TP3.1 (1_1)
unnamed: D13.3 (VDD), R18.2
unnamed: D14.2 (A), R19.1
unnamed: D15.2 (A), R25.2
unnamed: C15.1, D15.1 (K), D16.1 (K), R24.1, R26.2
unnamed: D16.2 (A), Q4.3 (G), R24.2
unnamed: D17.2 (A), R30.2
unnamed: C18.1, D17.1 (K), D18.1 (K), R29.1, R31.2
unnamed: D18.2 (A), Q5.3 (G), R29.2
unnamed: D19.2 (A), R34.2
unnamed: C20.1, D19.1 (K), D20.1 (K), R33.1, R35.2
unnamed: D20.2 (A), Q6.3 (G), R33.2
unnamed: D21.2 (A), Q8.3 (G), R38.2
unnamed: C24.2, D21.1 (K), R38.1, R39.2
unnamed: D22.2 (A), Q9.3 (G), R41.2
unnamed: C26.1, D22.1 (K), D23.1 (K), R41.1, R43.2
unnamed: D23.2 (A), R42.2
unnamed: D24.2 (A), Q10.3 (G), R47.2
unnamed: C29.1, D24.1 (K), R47.1, R48.2
unnamed: D25.2 (A), Q11.3 (G), R51.2
unnamed: C30.1, D25.1 (K), R51.1, R52.2
unnamed: D26.2 (A), Q14.3 (G), R64.2
unnamed: C36.1, D26.1 (K), R64.1, R65.2
unnamed: D27.2 (A), Q15.3 (G), R69.2
unnamed: C37.1, D27.1 (K), R69.1, R70.2
unnamed: D28.2 (A), Q17.3 (G), R86.2
unnamed: C48.1, D28.1 (K), D29.2 (A), R86.1, R88.2
unnamed: D29.1 (K), R87.2
unnamed: J2.R, R15.1
unnamed: J3.2, R16.1, U2.5 (VO)
unnamed: J3.8, R17.1
unnamed: J4.1, SW1.1
unnamed: J4.3, SW1.3 (4)
unnamed: J4.5, SW2.1
unnamed: J4.7, SW2.3 (4)
unnamed: J4.9, SW3.1
unnamed: J4.11, SW3.3 (4)
unnamed: J4.19, R19.2
unnamed: C33.1, J6.2, Q12.2 (C), Q13.3 (B), R54.2, R55.1, TP7.1 (1_1)
unnamed: C33.2, J6.3, Q13.2 (C), Q16.3 (G), R60.1, R61.1, R63.1, R67.1, TP10.1 (1_1)
unnamed: J7.T, R94.2
unnamed: C1.1, Q1.2 (S), Q2.2 (E), Q3.2 (S), R2.2, R4.2
unnamed: Q2.1 (B), R2.1, R3.2
unnamed: C1.2, Q2.3 (C), Q3.1 (G), R4.1, R5.2
unnamed: Q4.2 (D), R22.1, R23.1
unnamed: C16.2, C17.2, Q5.2 (D), R28.1
unnamed: C19.2, Q6.2 (D), R32.1
unnamed: C23.1, Q7.2 (E), R36.2
unnamed: C23.2, Q8.2 (D), R37.2
unnamed: C25.1, Q9.2 (D), R40.1
unnamed: C27.1, Q10.2 (D), Q11.2 (D), R45.1, R46.1
unnamed: Q10.1 (S), R49.1, R50.1
unnamed: C28.2, Q11.1 (S), R45.2, R49.2, R50.2, R53.1
unnamed: C35.1, Q12.3 (B), R53.2, R54.1, R58.1
unnamed: C34.1, C35.2, Q13.1 (E), R56.1, R57.1, R58.2, TP9.1 (1_1)
unnamed: Q14.1 (S), R62.2
unnamed: Q15.1 (S), R66.2, R68.2
unnamed: C38.1, Q16.1 (S), R71.2
unnamed: C47.2, Q17.2 (D), R85.2
unnamed: C49.1, Q8.1 (S), Q17.1 (S), R90.2
unnamed: C49.2, Q18.1 (B), R91.2
unnamed: C50.2, Q18.2 (E), R92.2
unnamed: R8.2, R9.1
unnamed: R59.1, R60.2
unnamed: R62.1, R63.2
unnamed: R66.1, R67.2, R68.1
unnamed: R75.1, R80.2, RV2.2
unnamed: R75.2, R76.1
unnamed: R77.1, R79.2, RV3.2
unnamed: R77.2, R78.1
unnamed: R84.2, RV4.3
unnamed: R88.1, R89.2
unnamed: C5.1, R7.1, R8.1, U1.4 (ADJ)
unnamed: C41.2, R81.2, U3.3 (+)
unnamed: R82.2, U3.1, U3.2 (-)
unnamed: C13.2, C14.1, C17.1, C19.1, R21.2, R23.2, R27.2, R28.2, R32.2, TP4.1 (1_1), U3.5 (+)
unnamed: R73.2, R74.2, RV2.1, RV3.1, U4.3 (+)
unnamed: C44.1, R76.2, R78.2, R83.1, RV2.3, RV3.3, U4.2 (-)
unnamed: C46.1, RV4.2, U4.5 (+)
unnamed: C47.1, U4.6 (-), U4.7
Pre-Volume: C45.2, J8.6, R84.1
Single: J4.10, R25.1, R26.1
VCC: C7.1, C31.1, C32.1, J6.4, Q14.2 (D), Q15.2 (D), R11.2, R13.2, R55.2, R59.2, R61.2, TP1.1 (1_1)
Wah: J4.14, R34.1, R35.1

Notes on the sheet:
This network interacts with the input impedance of the fuzz stage and attenuates the input signal. It affects the amount of guitar volume reduction required to prevent saturation.
MIDI IN (MIDI TRS Type A compliant)
Rg = 100M returns the gate charge when the JFET switch turns on. The series diode only handles turn-off; it cannot do this. Do not omit it: recovery would then depend on diode leakage alone, estimated at 23 ms at 25 degC (from 8.7 nA measured at room temperature) and about 520 ms at -20 degC (extra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
R38: see Rg note below R86.
South-West
The fuzz stage output swings up to about 5 Vpp (limited by the 5.6 V VCC). The tone stage adds up to 5x (+14 dB) of treble boost, so peaks can reach the +-8 V rails of U4. Use a rail-to-rail output op-amp.
Q12/Q13 hFE: the built units use parts selected to the windows marked between Q12 and Q13 (measured at I_B = 1.00 uA, V_CE = 5 V). The DC operating point (I_C13 = 300 uA, I_C12 = 30 uA) is set by the R58 feedback. In simulation, hFE values of 340-430 change I_C13 by less than 0.5% and the gain by l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
Bass(A2)
South-East
Using low-leakage capacitors helps reduce switching pop noise. Film capacitors (e.g. PMLCAP) are preferred for C23, C47, and C49 over aluminium electrolytic capacitors.
MIC5205 defines Vref as Vout - Vadj, not as the usual bottom-leg reference. R7 22k sits between ADJ and GND; R8 + R9 = 6.2k sits between OUT and ADJ. Vout = 5.65 V. Applying the ordinary divider formula to this gives 1.59 V, which is wrong. (Measured VCC is 5.599 V, which reflects the voltage drop 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
Fuzz(B1)
These load networks form an LPF with the pickup inductance. Reducing the guitar volume lowers the Q factor, giving a gentler high-frequency roll-off.
R37 and R85 must be the same value. The DC step between bypass and effect is dV = Ig * [(R85||R90) - (R37||R90)], so what matters is that they match, not the absolute value. Do not change one without the other. 1% parts are enough: a 2% mismatch adds under 5 uV, far below the tens of uV measured wi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
R37: see note below.
Response(C2)
To minimize pop, the JFET ahead of the high-gain fuzz stage (Q9) turns on before, and turns off after, the effect output switch Q17. The gate RC cells are asymmetric on purpose; do not make them symmetric. Q4, Q5, Q6, Q9: turn-on (1Meg||220k)*0.1u = 18 ms turn-off 1Meg*0.1u = 100 ms Q17 (asymmetric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
Vout=5.65V Vout-Vadj=1.242V Rbtm=22k Rtop=6.2k
I_C13 = 300uA(typ.)
hFE as built Q12: 365-375 Q13: 375-385 (I_B=1.00uA, V_CE=5V)
C35 (100p across R58) adds high-frequency feedback as a precaution. Removing it made no noticeable change in frequency response or stability on the prototype (no data kept); the high-frequency roll-off is set by C33. If you omit it, check for oscillation at all Fuzz and Bias settings.
Note the PL9823-F5 pinout. In the datasheet package drawing (leads down), the leads run 4(DIN), 3(VDD), 1(GND), 2(DO) from left to right. The symbol and the standard 4-pin THT LED footprint number them 4(DIN), 3(VDD), 2(GND), 1(DO): pins 1 and 2 are swapped in number only, and the physical order is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
North-East
R90 = 15k and R36 = 3.3k were chosen together. R90 sets the pop dip through Ig * (Rd || Rs). Lowering R90 220k -> 15k with matched R37/R85 (100k/220k -> 47k/47k) cut pop by 16.7-19.4 dB; R90's own share was not measured. Raising R90 gives some back. R36 = 3.3k restores the negative swing lost to th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
R90: see note near R36.
Input-Filter(C3)
To keep MIDI IN edges sharp, use a photocoupler with a response time of 1 us or less.
North-West
Bias adds resistance in parallel with Q13's collector load via Q14/Q15. (Toggle-Switch Pos.) = [Q14, Q15, Rc(eff), Headroom ratio] Center = [OFF, OFF, 8.6k, 1:1] Offset = [ON, OFF, 5.6k, 2:1] Skew = [OFF, ON, 4.3k, 3:1] X-Skew = [ON, ON, 3.4k, 4:1] (Headroom ratio = V(C13)-V(E13) : VCC-V(C13))
Bias(C1)
Volume(A1)
8.50k
8.592k
Treble(B2)
16.0k

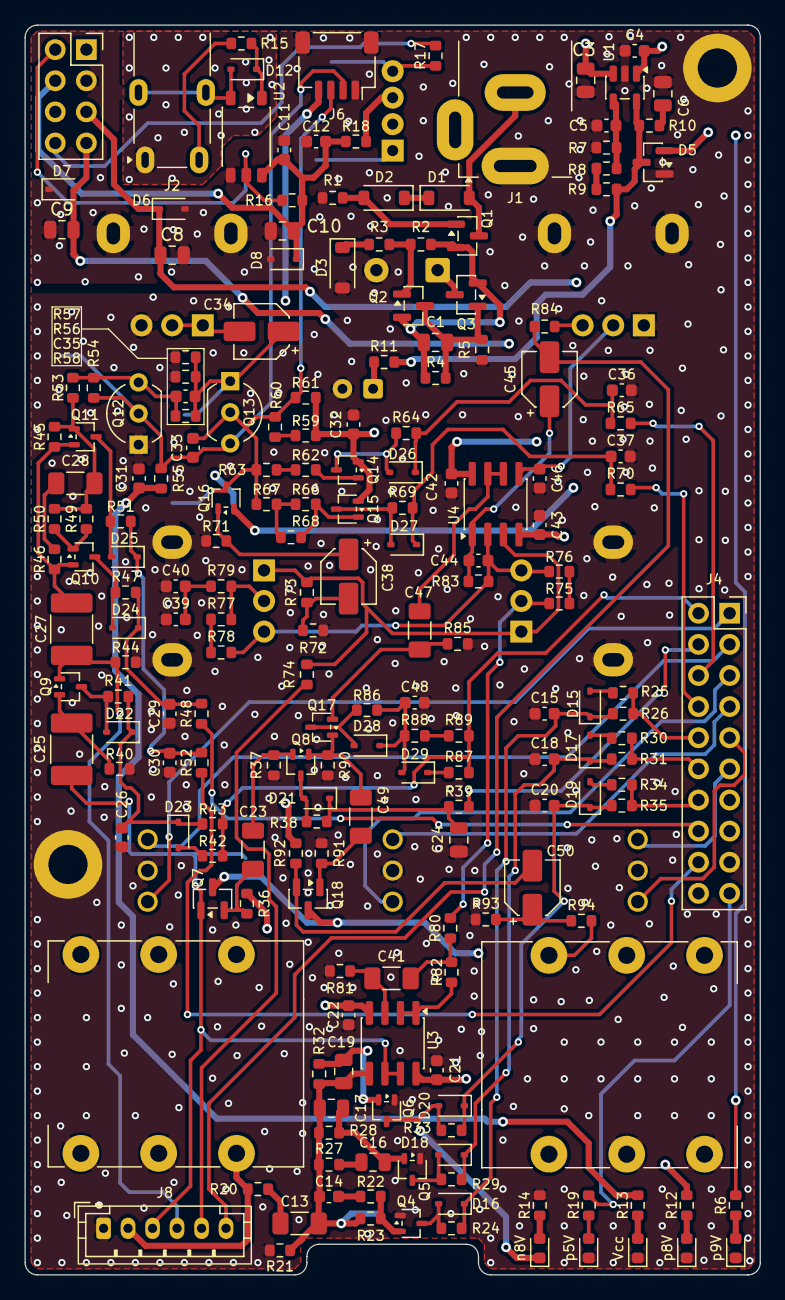
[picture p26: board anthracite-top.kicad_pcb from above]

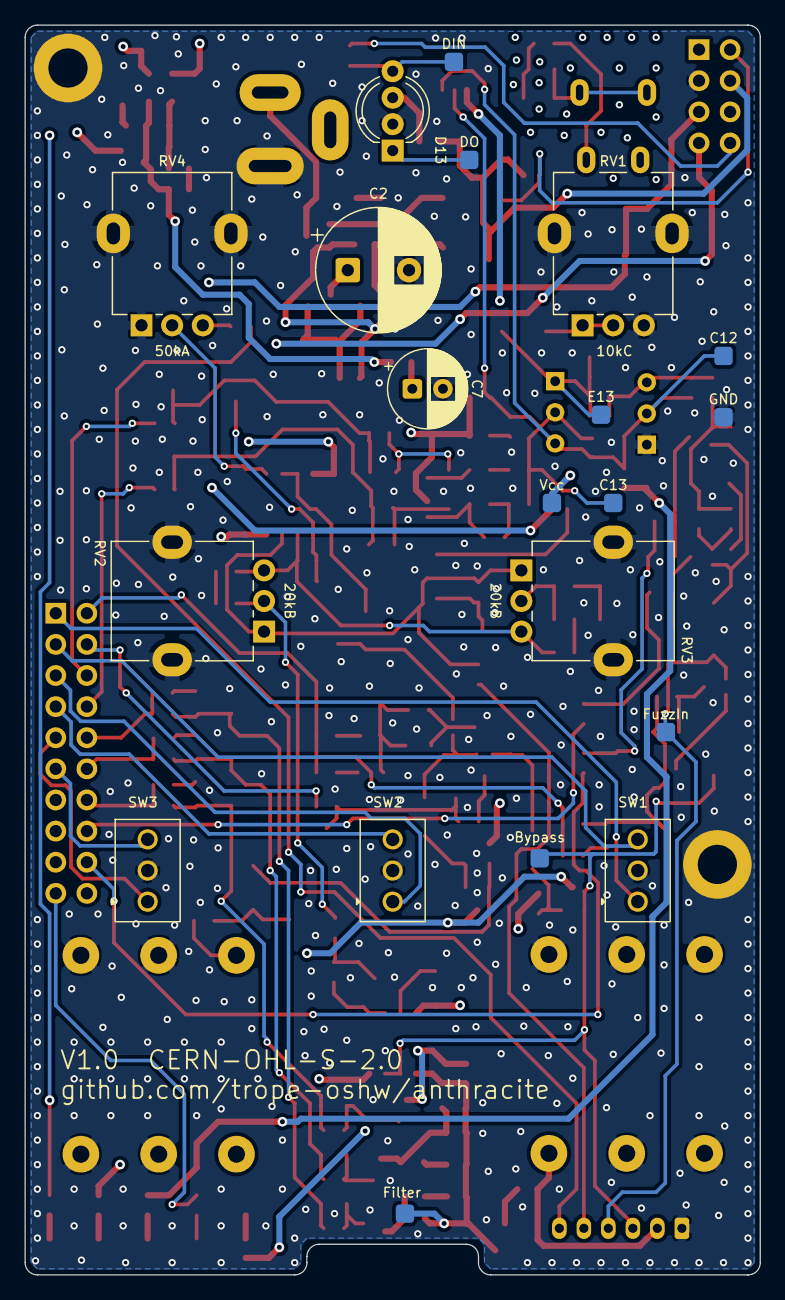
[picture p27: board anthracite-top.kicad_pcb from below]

Board: 4 copper layers, 60.0 x 102.0 mm, 222 parts (20 on the bottom side), 123 nets.

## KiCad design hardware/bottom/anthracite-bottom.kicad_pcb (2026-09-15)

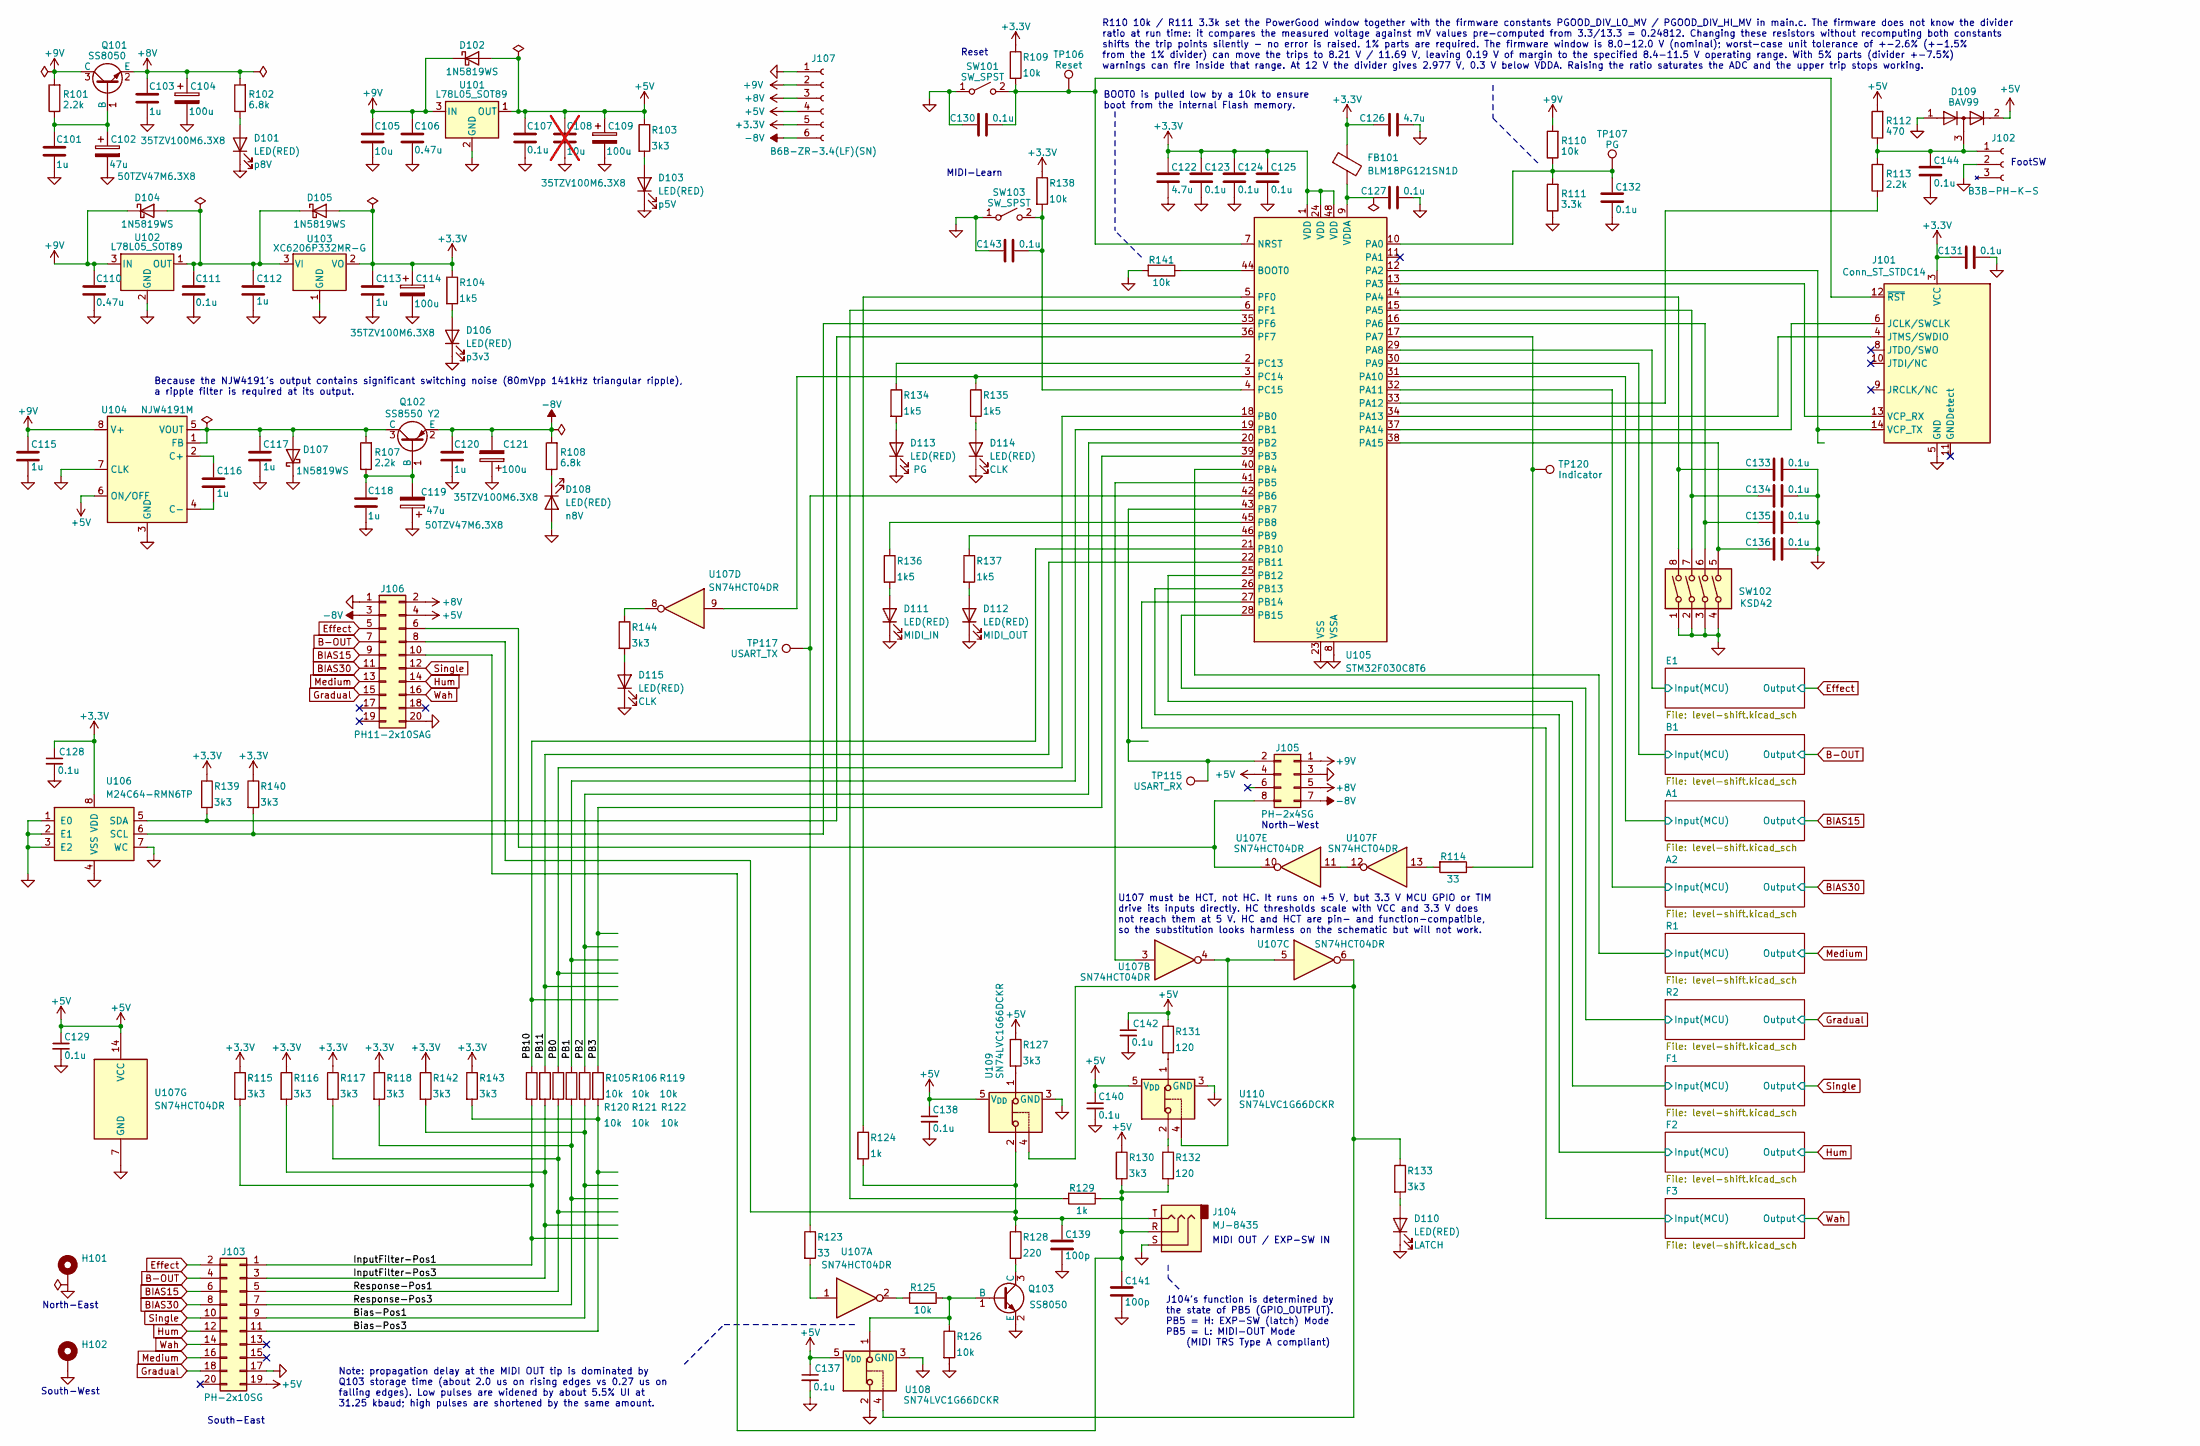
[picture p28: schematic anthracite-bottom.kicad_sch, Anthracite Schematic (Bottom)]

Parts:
C101, C103, C112, C113, C115, C116, C117, C118, C120: 1u; C_0805_2012Metric; Tolerance 10%; Voltage 50V; MPN CL21B105KBFNNNE; LCSC C28323
C102, C119: 47u; CP_Rubycon_35TZV100M6.3X8; Tolerance 20%; Voltage 50V; MPN 50TZV47M6.3X8; LCSC C88734
C104, C109, C114, C121: 100u; CP_Rubycon_35TZV100M6.3X8; Tolerance 20%; Voltage 35V; MPN 35TZV100M6.3X8; LCSC C88744
C105: 10u; C_0805_2012Metric; Tolerance 10%; Voltage 25V; LCSC C15850
C106, C110: 0.47u; C_0603_1608Metric; Tolerance 10%; Voltage 25V; LCSC C1623
C107, C111: 0.1u; C_0805_2012Metric; Tolerance 10%; Voltage 50V; LCSC C49678
C108: 10u; C_0805_2012Metric; Tolerance 10%; Voltage 50V; MPN GRM21BR61H106KE43L; LCSC C440198; not fitted
C122, C126: 4.7u; C_0805_2012Metric; Tolerance 10%; Voltage 25V; LCSC C1779
C123, C124, C125, C127, C128, C129, C130, C131, C132, C133, C134, C135, C136, C137, C138, C140, C142, C143, C144: 0.1u; C_0603_1608Metric; Tolerance 10%; Voltage 50V; LCSC C14663
C139, C141: 100p; C_0603_1608Metric; Tolerance 5%; Voltage 50V; LCSC C14858
D101, D103, D106, D108, D110, D111, D112, D113, D114, D115: LED(RED); D_0603_1608Metric_Name; MPN KT-0603R; LCSC C2286
D102, D104, D105, D107: 1N5819WS; D_SOD-323; MPN 1N5819WS; LCSC C191023
D109: BAV99; SOT-23; MPN BAV99,215; LCSC C2500
FB101: BLM18PG121SN1D; L_0603_1608Metric; Tolerance 25%; LCSC C14709
H101, H102: MountingHole_Pad; MountingHole_3.2mm_M3_DIN965_Pad
J101: Conn_ST_STDC14; STDC14_2x07_P1.27mm_Vertical_ST-LINKV3; MPN HX JN1.27-2x7P ZZ H4.9
J102: B3B-PH-K-S; JST_PH_B3B-PH-K_1x03_P2.00mm_Vertical; MPN B3B-PH-K-S(LF)(SN)
J103: PH-2x10SG; PinHeader_2x10_P2.54mm_Vertical; MPN PH-2x10SG
J104: MJ-8435; MPN MJ-8435
J105: PH-2x4SG; PinHeader_2x04_P2.54mm_Vertical; MPN PH-2x4SG
J106: PH11-2x10SAG; PinHeader_2x10_P1.27mm_Vertical; MPN PH11-2x10SAG
J107: B6B-ZR-3.4(LF)(SN); JST_ZH_B6B-ZR_1x06_P1.50mm_Vertical; MPN B6B-ZR-3.4(LF)(SN)
Q101, Q103: SS8050; SOT-23; MPN SS8050(RANGE:200-350); LCSC C2150
Q102: SS8550 Y2; SOT-23; MPN SS8550 Y2(RANGE:200-350); LCSC C8542
R101, R107, R113: 2.2k; R_0603_1608Metric; Tolerance 1%; LCSC C4190
R102, R108: 6.8k; R_0603_1608Metric; Tolerance 1%; LCSC C23212
R103, R133, R144: 3k3; R_0402_1005Metric; Tolerance 1%; LCSC C25890
R104, R134, R135, R136, R137: 1k5; R_0402_1005Metric; Tolerance 1%; LCSC C25867
R105, R106, R109, R119, R120, R121, R122, R125, R126, R138, R141: 10k; R_0402_1005Metric_MiniFont; Tolerance 1%; LCSC C25744
R110: 10k; R_0603_1608Metric; Tolerance 1%; LCSC C25804
R111: 3.3k; R_0603_1608Metric; Tolerance 1%; LCSC C22978
R112: 470; R_0603_1608Metric; Tolerance 1%; LCSC C23179
R114, R123: 33; R_0402_1005Metric_MiniFont; Tolerance 1%; LCSC C25105
R115, R116, R117, R118, R127, R130, R139, R140, R142, R143: 3k3; R_0402_1005Metric_MiniFont; Tolerance 1%; LCSC C25890
R124, R129: 1k; R_0402_1005Metric_MiniFont; Tolerance 1%; LCSC C11702
R128: 220; R_0402_1005Metric_MiniFont; Tolerance 1%; LCSC C25091
R131, R132: 120; R_0402_1005Metric_MiniFont; Tolerance 1%; LCSC C25079
SW101, SW103: SW_SPST; TS1088AR02016; MPN TS-1088-AR02016; LCSC C720477
SW102: KSD42; DIP-8_W7.62mm; MPN KSD42
TP106, TP107, TP115, TP117, TP120: TestPoint; TestPoint_Pad_1.5x1.5mm_Label
U101, U102: L78L05_SOT89; SOT-89-3; MPN 78L05G-AB3-R; LCSC C71136
U103: XC6206P332MR-G; SOT-23-3; MPN XC6206P332MR-G; LCSC C5446
U104: NJW4191M; DMP-8_P1.27mm_HandSolder; MPN NJW4191M
U105: STM32F030C8T6; LQFP-48_7x7mm_P0.5mm; MPN STM32F030C8T6; LCSC C23922
U106: M24C64-RMN6TP; SOIC-8_3.9x4.9mm_P1.27mm; MPN M24C64-RMN6TP; LCSC C79988
U107: SN74HCT04DR; SOIC-14_3.9x8.7mm_P1.27mm; MPN SN74HCT04DR; LCSC C6766
U108, U109, U110: SN74LVC1G66DCKR; SOT-353_SC-70-5; MPN SN74LVC1G66DCKR; LCSC C113518

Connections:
+3.3V: C113.1, C114.1, C122.1, C123.1, C124.1, C125.1, C126.1, C128.1, C131.1, D105.2 (A), FB101.1, J101.3 (VCC), J107.5, R104.1, R109.1, R115.1, R116.1, R117.1, R118.1, R138.1, R139.1, R140.1, R142.1, R143.1, U103.2 (VO), U105.1 (VDD), U105.24 (VDD), U105.48 (VDD), U106.8 (VDD)
+5V: C107.1, C108.1, C109.1, C129.1, C137.1, C138.1, C140.1, C142.1, D102.2 (A), D109.2 (A), J103.19, J105.4, J106.4, J107.4, R103.1, R112.2, R127.1, R130.1, R131.1, U101.1 (OUT), U104.6 (ON/OFF), U107.14 (VCC), U108.5 (V_{DD}), U109.5 (V_{DD}), U110.5 (V_{DD}); also elsewhere on the board
+8V: C103.1, C104.1, J105.5, J106.2, J107.3, Q101.2 (E), R102.2; also elsewhere on the board
+9V: C105.1, C106.1, C110.1, C115.1, D102.1 (K), D104.1 (K), J105.1, J107.2, Q101.3 (C), R101.2, R110.2, U101.3 (IN), U102.3 (IN), U104.8 (V+)
-8V: C120.1, C121.2, J105.7, J106.3, J107.6, Q102.2 (E), R108.2; also elsewhere on the board
/A1/Input(MCU): U105.31 (PA10); also elsewhere on the board
/A2/Input(MCU): U105.32 (PA11); also elsewhere on the board
/B1/Input(MCU): U105.30 (PA9); also elsewhere on the board
/Bias-Pos1: J103.9, R121.2, R142.2
/Bias-Pos3: J103.11, R122.2, R143.2
/E1/Input(MCU): U105.29 (PA8); also elsewhere on the board
/F1/Input(MCU): U105.25 (PB12); also elsewhere on the board
/F2/Input(MCU): U105.26 (PB13); also elsewhere on the board
/F3/Input(MCU): U105.27 (PB14); also elsewhere on the board
/InputFilter-Pos1: J103.1, R105.2, R115.2
/InputFilter-Pos3: J103.3, R106.2, R116.2
/PB0: R119.1, U105.18 (PB0)
/PB1: R120.1, U105.19 (PB1)
/PB2: R121.1, U105.20 (PB2)
/PB3: R122.1, U105.39 (PB3)
/PB10: R105.1, U105.21 (PB10)
/PB11: R106.1, U105.22 (PB11)
/R1/Input(MCU): U105.40 (PB4); also elsewhere on the board
/R2/Input(MCU): U105.28 (PB15); also elsewhere on the board
/Response-Pos1: J103.5, R117.2, R119.2
/Response-Pos3: J103.7, R118.2, R120.2
B-OUT: J103.4, J106.7; also elsewhere on the board
BIAS15: J103.6, J106.9; also elsewhere on the board
BIAS30: J103.8, J106.11; also elsewhere on the board
Effect: J103.2, J106.5; also elsewhere on the board
GNDPWR: C101.2, C102.2, C103.2, C104.2, C105.2, C106.2, C107.2, C108.2, C109.2, C110.2, C111.2, C112.2, C113.2, C114.2, C115.2, C117.2, C118.2, C119.1, C120.2, C121.1, C122.2, C123.2, C124.2, C125.2, C126.2, C127.2, C128.2, C129.2, C130.1, C131.2, C132.2, C133.2, C134.2, C135.2, C136.2, C137.2, C138.2, C139.2, C140.2, C141.2, C142.2, C143.1, C144.2, D101.1 (K), D103.1 (K), D106.1 (K), D107.1 (K), D108.2 (A), D109.1 (K), D110.1 (K), D111.1 (K), D112.1 (K), D113.1 (K), D114.1 (K), D115.1 (K), H101.1 (1_1), H102.1 (1_1), J101.5 (GND), J101.7 (GND), J102.2, J103.17, J104.S, J105.3, J106.1, J106.20, J107.1, Q103.2 (E), R111.1, R126.2, R141.1, SW101.1 (A), SW102.1, SW102.2, SW102.3, SW102.4, SW103.1 (A), U101.2 (GND), U102.2 (GND), U103.1 (GND), U104.3 (GND), U104.7 (CLK), U105.8 (VSSA), U105.23 (VSS), U105.47 (VSS), U106.1 (E0), U106.2 (E1), U106.3 (E2), U106.4 (VSS), U106.7 (WC), U107.7 (GND), U108.2, U108.3 (GND), U109.3 (GND), U110.3 (GND); also elsewhere on the board
Gradual: J103.18, J106.15; also elsewhere on the board
Hum: J103.12, J106.14; also elsewhere on the board
Medium: J103.16, J106.13; also elsewhere on the board
unnamed: D101.2 (A), R102.1
unnamed: D103.2 (A), R103.2
unnamed: C111.1, C112.1, D104.2 (A), D105.1 (K), U102.1 (OUT), U103.3 (VI)
unnamed: D106.2 (A), R104.2
unnamed: C117.1, D107.2 (A), Q102.3 (C), R107.2, U104.1 (FB), U104.5 (VOUT)
unnamed: D108.1 (K), R108.1
unnamed: D110.2 (A), R133.2
unnamed: D111.2 (A), R136.2
unnamed: D112.2 (A), R137.2
unnamed: D113.2 (A), R134.2
unnamed: D114.2 (A), R135.2
unnamed: D115.2 (A), R144.2
unnamed: J101.6 (JCLK/SWCLK), U105.37 (PA14)
unnamed: J101.4 (JTMS/SWDIO), U105.34 (PA13)
unnamed: J101.13 (VCP_RX), U105.13 (PA3)
unnamed: J101.14 (VCP_TX), U105.12 (PA2)
unnamed: C130.2, J101.12 (~RST), R109.2, SW101.2 (B), TP106.1 (1_1), U105.7 (NRST)
unnamed: C144.1, D109.3 (K), J102.1, R112.1, R113.2
unnamed: J105.2, TP115.1 (1_1), U105.43 (PB7)
unnamed: J105.8, J106.6, U107.10
unnamed: C139.1, J104.T, J106.8, R124.2, R128.1, U109.2
unnamed: C141.1, J104.R, J106.10, R129.2, R130.2, R132.2
unnamed: C101.1, C102.1, Q101.1 (B), R101.1
unnamed: C118.1, C119.2, Q102.1 (B), R107.1
unnamed: Q103.1 (B), R125.2, R126.1, U108.1
unnamed: Q103.3 (C), R128.2
unnamed: R114.1, U107.13
unnamed: R123.2, U107.1
unnamed: R125.1, U107.2
unnamed: R127.2, U109.1
unnamed: R131.2, U110.1
unnamed: R132.1, U110.2
unnamed: R133.1, U107.6, U108.4, U109.4
unnamed: R144.1, U107.8
unnamed: C143.2, R138.2, SW103.2 (B), U105.4 (PC15)
unnamed: C116.1, U104.2 (C+)
unnamed: C116.2, U104.4 (C-)
unnamed: R141.2, U105.44 (BOOT0)
unnamed: C132.1, R110.1, R111.2, TP107.1 (1_1), U105.10 (PA0)
unnamed: C133.1, SW102.8, U105.14 (PA4)
unnamed: C134.1, SW102.7, U105.15 (PA5)
unnamed: C135.1, SW102.6, U105.16 (PA6)
unnamed: R114.2, TP120.1 (1_1), U105.17 (PA7)
unnamed: R113.1, U105.33 (PA12)
unnamed: C136.1, SW102.5, U105.38 (PA15)
unnamed: U105.41 (PB5), U107.3
unnamed: R123.1, TP117.1 (1_1), U105.42 (PB6)
unnamed: R136.1, U105.45 (PB8)
unnamed: R137.1, U105.46 (PB9)
unnamed: R134.1, U105.2 (PC13)
unnamed: R135.1, U105.3 (PC14), U107.9
unnamed: R124.1, U105.5 (PF0)
unnamed: R129.1, U105.6 (PF1)
unnamed: R140.2, U105.35 (PF6), U106.6 (SCL)
unnamed: R139.2, U105.36 (PF7), U106.5 (SDA)
unnamed: C127.1, FB101.2, U105.9 (VDDA)
unnamed: U107.4, U107.5, U110.4
unnamed: U107.11, U107.12
Single: J103.10, J106.12; also elsewhere on the board
Wah: J103.14, J106.16; also elsewhere on the board

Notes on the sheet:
South-West
R110 10k / R111 3.3k set the PowerGood window together with the firmware constants PGOOD_DIV_LO_MV / PGOOD_DIV_HI_MV in main.c. The firmware does not know the divider ratio at run time: it compares the measured voltage against mV values pre-computed from 3.3/13.3 = 0.24812. Changing these resistors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
BOOT0 is pulled low by a 10k to ensure boot from the internal Flash memory.
MIDI-Learn
Because the NJW4191's output contains significant switching noise (80mVpp 141kHz triangular ripple), a ripple filter is required at its output.
North-East
South-East
North-West
Note: propagation delay at the MIDI OUT tip is dominated by Q103 storage time (about 2.0 us on rising edges vs 0.27 us on falling edges). Low pulses are widened by about 5.5% UI at 31.25 kbaud; high pulses are shortened by the same amount.
U107 must be HCT, not HC. It runs on +5 V, but 3.3 V MCU GPIO or TIM drive its inputs directly. HC thresholds scale with VCC and 3.3 V does not reach them at 5 V. HC and HCT are pin- and function-compatible, so the substitution looks harmless on the schematic but will not work.
FootSW
MIDI OUT / EXP-SW IN
Reset
J104's function is determined by the state of PB5 (GPIO_OUTPUT). PB5 = H: EXP-SW (latch) Mode PB5 = L: MIDI-OUT Mode (MIDI TRS Type A compliant)

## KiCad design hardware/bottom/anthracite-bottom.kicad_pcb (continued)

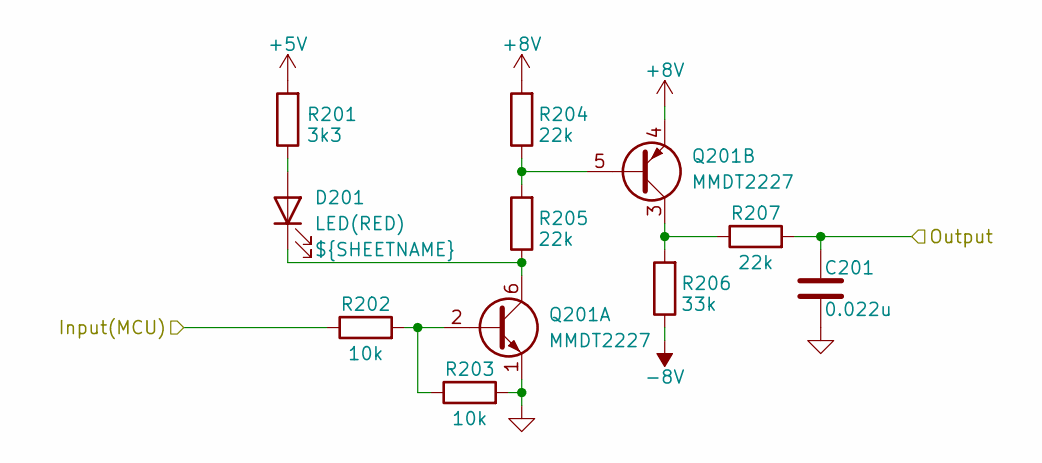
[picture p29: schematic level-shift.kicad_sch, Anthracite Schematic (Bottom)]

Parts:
C201: 0.022u; C_0603_1608Metric; Tolerance 10%; Voltage 50V; LCSC C21122
D201: LED(RED); D_0603_1608Metric_Name; MPN KT-0603R; LCSC C2286
Q201: MMDT2227; SOT-363_SC-70-6; MPN MMDT2227; LCSC C41375117
R201: 3k3; R_0402_1005Metric_MiniFont; Tolerance 1%; LCSC C25890
R202, R203: 10k; R_0402_1005Metric_MiniFont; Tolerance 1%; LCSC C25744
R204, R205, R207: 22k; R_0402_1005Metric_MiniFont; Tolerance 1%; LCSC C25768
R206: 33k; R_0402_1005Metric_MiniFont; Tolerance 1%; LCSC C25779

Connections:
+5V: R201.2; also elsewhere on the board
+8V: Q201.4 (E2), R204.2; also elsewhere on the board
-8V: R206.1; also elsewhere on the board
/E1/Input(MCU): R202.1; also elsewhere on the board
Effect: C201.2, R207.2; also elsewhere on the board
GNDPWR: C201.1, Q201.1 (E1), R203.2; also elsewhere on the board
unnamed: D201.2 (A), R201.1
unnamed: D201.1 (K), Q201.6 (C1), R205.1
unnamed: Q201.2 (B1), R202.2, R203.1
unnamed: Q201.5 (B2), R204.1, R205.2
unnamed: Q201.3 (C2), R206.2, R207.1

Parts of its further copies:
C301, C401, C501, C601, C701, C801, C901, C1001: 0.022u; C_0603_1608Metric; Tolerance 10%; Voltage 50V; LCSC C21122
D301, D401, D501, D601, D701, D801, D901, D1001: LED(RED); D_0603_1608Metric_Name; MPN KT-0603R; LCSC C2286
Q301, Q401, Q501, Q601, Q701, Q801, Q901, Q1001: MMDT2227; SOT-363_SC-70-6; MPN MMDT2227; LCSC C41375117
R301, R401, R501, R601, R701, R801, R901, R1001: 3k3; R_0402_1005Metric_MiniFont; Tolerance 1%; LCSC C25890
R302, R303, R402, R403, R502, R503, R602, R603, R702, R703, R802, R803, R902, R903, R1002, R1003: 10k; R_0402_1005Metric_MiniFont; Tolerance 1%; LCSC C25744
R304, R305, R307, R404, R405, R407, R504, R505, R507, R604, R605, R607, R704, R705, R707, R804, R805, R807, R904, R905, R907, R1004, R1005, R1007: 22k; R_0402_1005Metric_MiniFont; Tolerance 1%; LCSC C25768
R306, R406, R506, R606, R706, R806, R906, R1006: 33k; R_0402_1005Metric_MiniFont; Tolerance 1%; LCSC C25779

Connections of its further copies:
+5V: R301.2, R401.2, R501.2, R601.2, R701.2, R801.2, R901.2, R1001.2; also elsewhere on the board
+8V: Q301.4 (E2), Q401.4 (E2), Q501.4 (E2), Q601.4 (E2), Q701.4 (E2), Q801.4 (E2), Q901.4 (E2), Q1001.4 (E2), R304.2, R404.2, R504.2, R604.2, R704.2, R804.2, R904.2, R1004.2; also elsewhere on the board
-8V: R306.1, R406.1, R506.1, R606.1, R706.1, R806.1, R906.1, R1006.1; also elsewhere on the board
/A1/Input(MCU): R402.1; also elsewhere on the board
/A2/Input(MCU): R502.1; also elsewhere on the board
/B1/Input(MCU): R302.1; also elsewhere on the board
/F1/Input(MCU): R602.1; also elsewhere on the board
/F2/Input(MCU): R702.1; also elsewhere on the board
/F3/Input(MCU): R802.1; also elsewhere on the board
/R1/Input(MCU): R902.1; also elsewhere on the board
/R2/Input(MCU): R1002.1; also elsewhere on the board
B-OUT: C301.2, R307.2; also elsewhere on the board
BIAS15: C401.2, R407.2; also elsewhere on the board
BIAS30: C501.2, R507.2; also elsewhere on the board
GNDPWR: C301.1, C401.1, C501.1, C601.1, C701.1, C801.1, C901.1, C1001.1, Q301.1 (E1), Q401.1 (E1), Q501.1 (E1), Q601.1 (E1), Q701.1 (E1), Q801.1 (E1), Q901.1 (E1), Q1001.1 (E1), R303.2, R403.2, R503.2, R603.2, R703.2, R803.2, R903.2, R1003.2; also elsewhere on the board
Gradual: C1001.2, R1007.2; also elsewhere on the board
Hum: C701.2, R707.2; also elsewhere on the board
Medium: C901.2, R907.2; also elsewhere on the board
unnamed: D301.2 (A), R301.1
unnamed: D301.1 (K), Q301.6 (C1), R305.1
unnamed: D401.2 (A), R401.1
unnamed: D401.1 (K), Q401.6 (C1), R405.1
unnamed: D501.2 (A), R501.1
unnamed: D501.1 (K), Q501.6 (C1), R505.1
unnamed: D601.2 (A), R601.1
unnamed: D601.1 (K), Q601.6 (C1), R605.1
unnamed: D701.2 (A), R701.1
unnamed: D701.1 (K), Q701.6 (C1), R705.1
unnamed: D801.2 (A), R801.1
unnamed: D801.1 (K), Q801.6 (C1), R805.1
unnamed: D901.2 (A), R901.1
unnamed: D901.1 (K), Q901.6 (C1), R905.1
unnamed: D1001.2 (A), R1001.1
unnamed: D1001.1 (K), Q1001.6 (C1), R1005.1
unnamed: Q301.2 (B1), R302.2, R303.1
unnamed: Q301.5 (B2), R304.1, R305.2
unnamed: Q301.3 (C2), R306.2, R307.1
unnamed: Q401.2 (B1), R402.2, R403.1
unnamed: Q401.5 (B2), R404.1, R405.2
unnamed: Q401.3 (C2), R406.2, R407.1
unnamed: Q501.2 (B1), R502.2, R503.1
unnamed: Q501.5 (B2), R504.1, R505.2
unnamed: Q501.3 (C2), R506.2, R507.1
unnamed: Q601.2 (B1), R602.2, R603.1
unnamed: Q601.5 (B2), R604.1, R605.2
unnamed: Q601.3 (C2), R606.2, R607.1
unnamed: Q701.2 (B1), R702.2, R703.1
unnamed: Q701.5 (B2), R704.1, R705.2
unnamed: Q701.3 (C2), R706.2, R707.1
unnamed: Q801.2 (B1), R802.2, R803.1
unnamed: Q801.5 (B2), R804.1, R805.2
unnamed: Q801.3 (C2), R806.2, R807.1
unnamed: Q901.2 (B1), R902.2, R903.1
unnamed: Q901.5 (B2), R904.1, R905.2
unnamed: Q901.3 (C2), R906.2, R907.1
unnamed: Q1001.2 (B1), R1002.2, R1003.1
unnamed: Q1001.5 (B2), R1004.1, R1005.2
unnamed: Q1001.3 (C2), R1006.2, R1007.1
Single: C601.2, R607.2; also elsewhere on the board
Wah: C801.2, R807.2; also elsewhere on the board

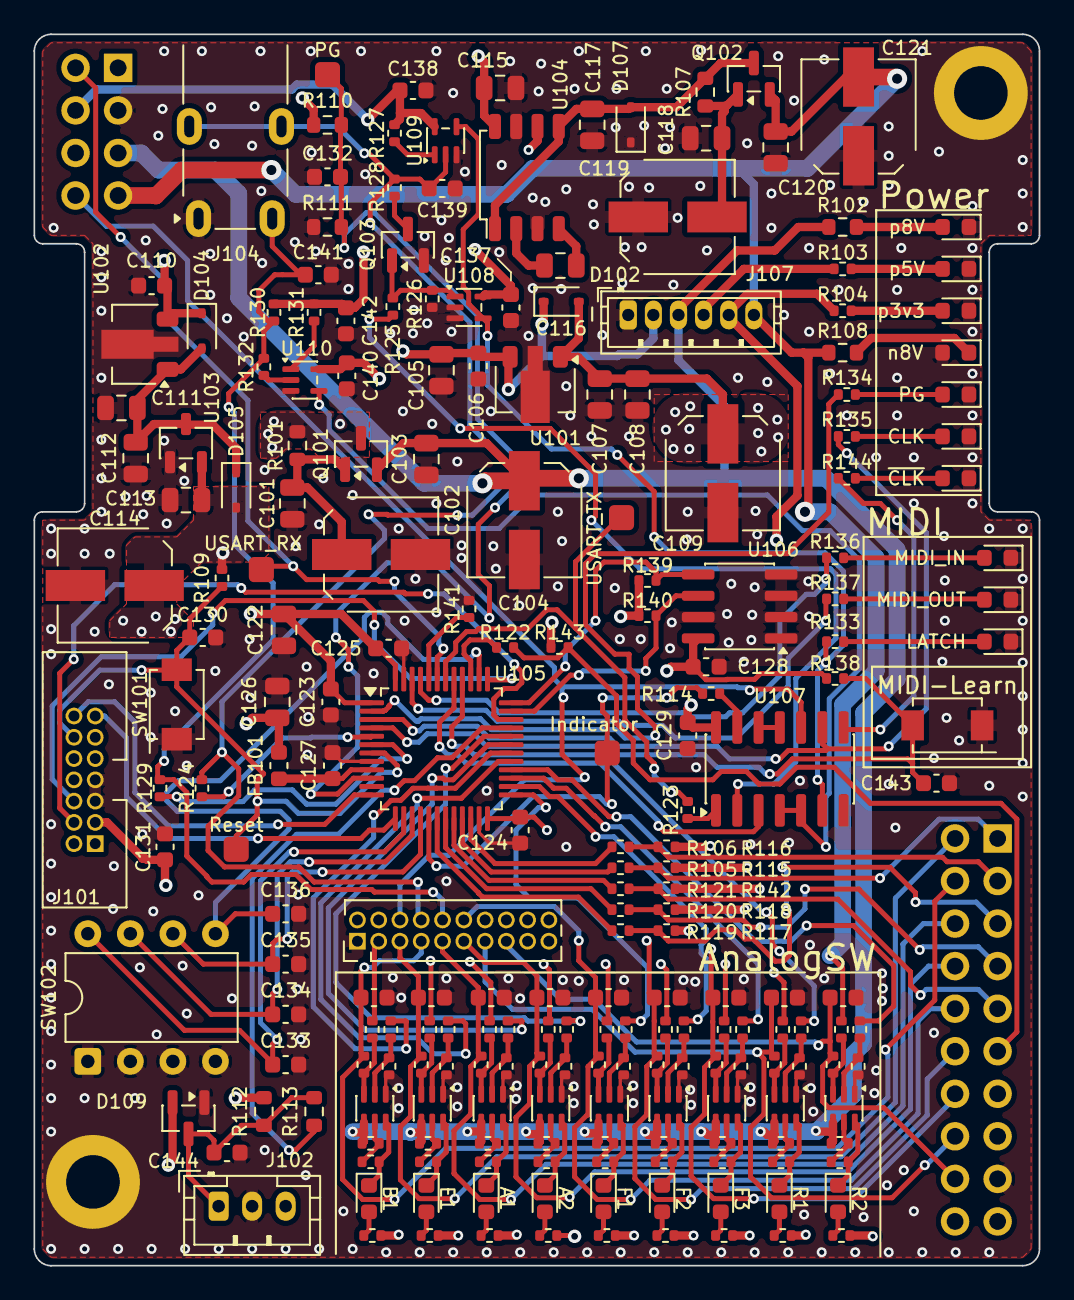
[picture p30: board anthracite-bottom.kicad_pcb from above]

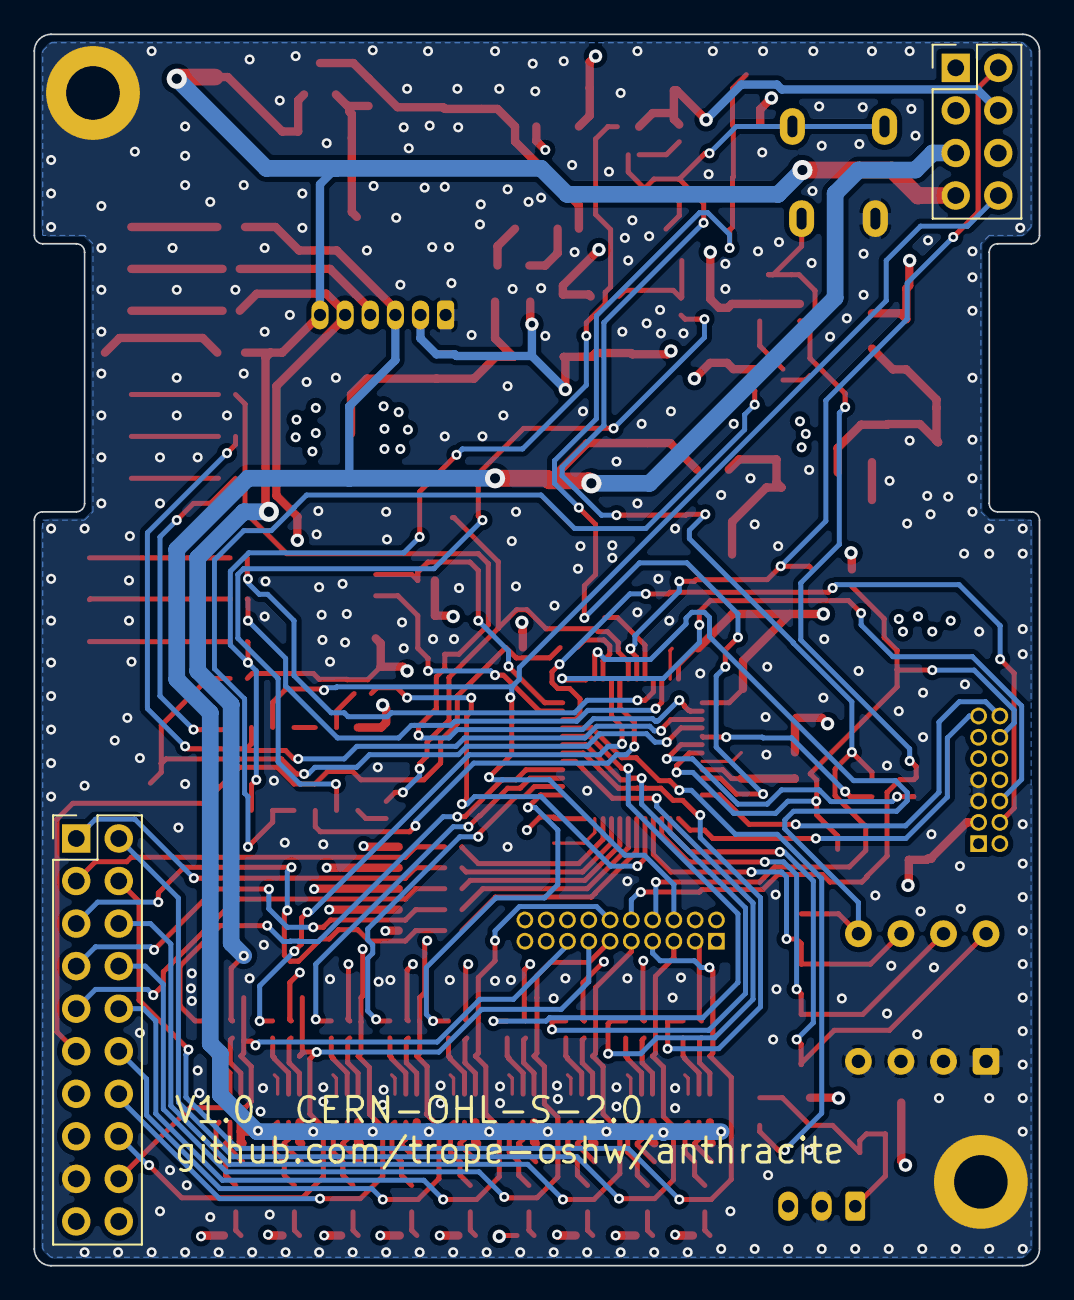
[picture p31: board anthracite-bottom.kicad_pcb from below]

Board: 4 copper layers, 60.0 x 73.5 mm, 224 parts (2 on the bottom side), 139 nets.

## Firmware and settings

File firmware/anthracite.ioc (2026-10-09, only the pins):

Mcu.UserName=STM32F030C8Tx
PA0.Signal=ADC_IN0
PA10.Signal=GPIO_Output
PA11.Signal=GPIO_Output
PA12.Signal=GPIO_Input
PA13.Signal=SYS_SWDIO
PA14.Signal=SYS_SWCLK
PA15.Signal=GPIO_Input
PA2.Signal=USART2_TX
PA3.Signal=USART2_RX
PA4.Signal=GPIO_Input
PA5.Signal=GPIO_Input
PA6.Signal=GPIO_Input
PA7.Signal=S_TIM14_CH1
PA8.Signal=GPIO_Output
PA9.Signal=GPIO_Output
PB0.Signal=GPIO_Input
PB1.Signal=GPIO_Input
PB10.Signal=GPIO_Input
PB11.Signal=GPIO_Input
PB12.Signal=GPIO_Output
PB13.Signal=GPIO_Output
PB14.Signal=GPIO_Output
PB15.Signal=GPIO_Output
PB2.Signal=GPIO_Input
PB3.Signal=GPIO_Input
PB4.Signal=GPIO_Output
PB5.Signal=GPIO_Output
PB6.Signal=USART1_TX
PB7.Signal=USART1_RX
PB8.Signal=GPIO_Output
PB9.Signal=GPIO_Output
PC13.Signal=GPIO_Output
PC14-OSC32_IN.Signal=GPIO_Output
PC15-OSC32_OUT.Signal=GPIO_Input
PF0-OSC_IN.Signal=GPIO_Input
PF1-OSC_OUT.Signal=GPIO_Input
PF6.Signal=I2C2_SCL
PF7.Signal=I2C2_SDA

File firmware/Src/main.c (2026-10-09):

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
/* Includes ------------------------------------------------------------------*/
#include "main.h"

/* USER CODE BEGIN Includes */
#include <stdbool.h>
#include <string.h>
#include <stdio.h>
#include <stdlib.h>
/* USER CODE END Includes */

/* USER CODE BEGIN PTD */
/* VCP debug console: one pin-table row (name lookup, write permission, snapshot output) */
typedef struct {
    GPIO_TypeDef *port;
    uint16_t      pin;
    const char   *name;
    bool          writable;
} dbg_pin_t;
/* USER CODE END PTD */

/* USER CODE BEGIN PD */
/* PL9823-F5 (WS2812-compatible) bit-banged output on PA7.
   PA7 -> R114 -> 74HCT04 (two inverters = non-inverting 5V buffer) -> J105-8 -> top R18 -> D12 DIN */
#define WS_PORT   GPIOA
#define WS_PIN    GPIO_PIN_7
#define WS_HIGH() (WS_PORT->BSRR = WS_PIN)
#define WS_LOW()  (WS_PORT->BSRR = (uint32_t)WS_PIN << 16)
#define NUM_LEDS  1

#define FOOTSW_DEBOUNCE_MS  50
#define IND_SOLID_MS        1000  /* Solid-on time at the start of an indication sequence */
#define IND_BLINK_ON_MS     100
#define IND_BLINK_OFF_MS    100
#define IND_FINAL_OFF_MS    500
#define STARTUP_BLINK_MS    500
#define MIDI_INDICATOR_MS   100   /* PB8/PB9: MIDI activity indicator on-time */
#define LED_FADE_STEP_MS    6     /* PL9823 color fade step interval [ms]; each step closes ~1/3 of the gap */

/* PowerGood ADC (PA0=ADC_IN0) + status LED (PC13)
   Divider R110 10k / R111 3.3k (ratio 3.3/13.3 = 0.24812): 9V in -> 2.23V.
   Warning window: 8.0~12.0V. It encloses the 8.4~11.5V operating range, so the LED does not
   flash inside that range.
   V_DDA is estimated from the VREFINT calibration value to compute the divider voltage [mV];
   PC13 is lit inside the window and blinks at a 0.4s period (50% duty) outside it.
   At 12.0V the divider gives 2.977V, about 0.3V below VDDA (3.28V measured), so the ADC does not saturate. */
#define PGOOD_DIV_LO_MV     1985U  /* Divider voltage for 8.0V (8.0 * 0.24812) */
#define PGOOD_DIV_HI_MV     2977U  /* Divider voltage for 12.0V (12.0 * 0.24812) */
#define PGOOD_POLL_MS       100U   /* ADC sampling interval */
#define PGOOD_BLINK_MS      200U   /* PC13 blink half-period (0.4s period, 50% duty) */
#define ADC_FULL_SCALE      4095U  /* 12bit */
/* VREFINT factory calibration value (taken at VDDA=3.3V). Guarded because bare HAL projects sometimes leave it undefined */
#ifndef VREFINT_CAL_ADDR
#define VREFINT_CAL_ADDR    ((uint16_t *)0x1FFFF7BAU)
#endif
#ifndef VREFINT_CAL_VREF
#define VREFINT_CAL_VREF    3300U    /* mV */
#endif

/* ---- VCP debug console (USART2 PA2/PA3, 115200bps, STLINK-V3 VCP) ---- */
#define DBG_LINE_MAX  64   /* RX line buffer; ample for the longest command ("MSEND"/"MRECV" plus 11 bytes) */
#define DBG_TX_MAX    320  /* TX formatting buffer (a snapshot is ~250 chars, plus the three override fields) */

/* ---- PA8 (Effect) falling-edge delay - pop noise countermeasure ----
   On Effect -> Bypass, PA9 (B-OUT) goes High immediately, but only the PA8 (Effect)
   falling edge is delayed by EFFECT_OFF_DELAY_US. The point is to widen the handover
   overlap between Q8 (bypass side) turning on and Q15 (effect side) turning off
   from 0.6ms to 6.4ms, matching the overlap of the Bypass -> Effect direction.
   Do NOT apply this to the rising edge (Bypass -> Effect): that would shrink the B->E
   overlap from 6.4ms to 0.6ms, making it as hard a splice as E->B, which defeats the purpose.
   Timing uses TIM14 as a 1MHz one-shot (1 count = 1us, max 65.535ms). */
#define EFFECT_OFF_DELAY_US  5800u  /* Default 5.8ms; changeable at runtime with the VCP console EDLY command */
#define EFFECT_OFF_DELAY_MAX 60000u /* Upper bound that still fits the 16-bit TIM14 ARR */

/* MIDI monitor: ring buffer holding USART1 RX/TX bytes tagged with a direction flag.
   Drained by the VCP M command. The size must be a power of two */
#define MIDI_MON_SIZE     128u
#define MIDI_MON_DIR_OUT  0x100u  /* Entry bit8: 0=IN (received), 1=OUT (transmitted) */
#define MIDI_MON_MAX_PER_RESP  40u  /* Max entries per M command (keeps the reply within DBG_TX_MAX) */
/* USER CODE END PD */

ADC_HandleTypeDef hadc;

I2C_HandleTypeDef hi2c2;

TIM_HandleTypeDef htim14;

UART_HandleTypeDef huart1;
UART_HandleTypeDef huart2;

/* USER CODE BEGIN PV */
static bool effect_active = false;

/* PA8 delayed-OFF state. While armed, TIM14 is running and the ISR drives PA8 Low on expiry */
static volatile bool     effect_off_armed    = false;
static volatile uint16_t effect_off_delay_us = EFFECT_OFF_DELAY_US;
static volatile uint16_t effect_off_count    = 0;  /* Number of delayed OFFs executed (reported by EDLY) */

static bool dip_sw1 = false; /* ON(Low)=power-on effect enabled */
static bool dip_sw2 = false; /* ON(Low)=extended bias mode */
static bool dip_sw3 = false; /* ON(Low)=MIDI mode / OFF(High)=latch mode */
static bool dip_sw4 = false; /* latch mode (OFF) / momentary mode (ON) */

/* Toggle switch inputs (all three have pole = GND and an external +3.3V pull-up).
   Pos1 Low = flipped up / Pos3 Low = flipped down / both High = center.
   The schematic net names match the physical layout. */
static GPIO_PinState prev_latch_tip  = GPIO_PIN_SET; /* PF0 */
static GPIO_PinState prev_latch_ring = GPIO_PIN_SET; /* PF1 */
static GPIO_PinState prev_bias_pos1  = GPIO_PIN_SET; /* PB2  */
static GPIO_PinState prev_bias_pos3  = GPIO_PIN_SET; /* PB3  */
static GPIO_PinState prev_resp_pos1  = GPIO_PIN_SET; /* PB0  */
static GPIO_PinState prev_resp_pos3  = GPIO_PIN_SET; /* PB1  */
static GPIO_PinState prev_filt_pos1  = GPIO_PIN_SET; /* PB10 */
static GPIO_PinState prev_filt_pos3  = GPIO_PIN_SET; /* PB11 */
static GPIO_PinState prev_footsw     = GPIO_PIN_SET; /* PA12 */

static volatile uint32_t footsw_debounce_ms = 0;

static uint8_t led_data[NUM_LEDS][3];       /* Current color actually sent to the PL9823 (this is what fades) */
static uint8_t led_target[3] = {0, 0, 0};   /* Target color chosen by update_led(); led_data eases toward it */
static volatile uint32_t led_fade_ms = 0;   /* Countdown to the next fade step (decremented by SysTick) */
static volatile uint8_t led_update_needed = 1;

typedef enum {
    LED_OVERRIDE_NONE = 0,
    LED_OVERRIDE_ORANGE, /* Bias change indication */
    LED_OVERRIDE_GREEN,  /* Input filter change indication */
    LED_OVERRIDE_CYAN,   /* Response change indication */
    LED_OVERRIDE_WHITE,  /* MIDI-Learn store-complete indication */
    LED_OVERRIDE_OFF,    /* forced off (blink gap) */
} led_override_t;
static volatile led_override_t led_override = LED_OVERRIDE_NONE;

typedef enum {
    IND_SEQ_IDLE = 0,
    IND_SEQ_SOLID_1S,
    IND_SEQ_BLINK_OFF,
    IND_SEQ_BLINK_ON,
    IND_SEQ_FINAL_OFF,
} ind_seq_state_t;

typedef struct {
    volatile ind_seq_state_t state;
    volatile uint8_t         blink_remain;
    volatile uint32_t        timer_ms;
    led_override_t           color;
} ind_seq_t;
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

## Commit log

2026-09-03 Add README, contributing guide, changelog, errata and issue templates
    Documentation that does not depend on the design data, so it can be written
    before the KiCad files are moved over.
    - README.md with measured specifications, the MIDI CC map, licensing,
    trademark and disclaimer sections. Impedance and current figures are
    measurements from a v1.0 unit, not simulations
    - firmware/README.md covering build and flash, which is also what GPLv3
    section 6 asks for on a device that ships with GPL software
    - CONTRIBUTING.md stating plainly that hardware PRs cannot be accepted, and
    why, rather than leaving people to find out by being ignored
    - CHANGELOG.md split into Hardware / Firmware / Err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
2026-09-15 Align docs with the v1.0 user manual and published board files
    - README: specs follow the v1.0 user manual (operating voltage 8.4-11.5 V,
    recommended 8.6-10.0 V, about 70 mA, input impedance 13/24/44 kOhm,
    corrected pot values and tapers, Bass/Treble behaviour, MIDI details).
    The board list now names the footswitch board. Trademark section explains
    that branding is removed from both the panel artwork and the board silkscreen.
    - CHANGELOG: board list includes the footswitch; note on the silkscreen
    difference between the first production run and the published files.
    - ERRATA: add recommended modifications; M-1 describes raising R38/R86 from
    100 MOhm to 200 MOhm for less switching p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
2026-09-15 Add v1.0 design data: KiCad projects, enclosure and generated documents
    hardware/
    - top, bottom and footswitch boards, each a self-contained KiCad 10 project
    with its own libs/ (symbols, footprints, 3D models) referenced through
    ${KIPRJMOD}. bottom also has the level-shift hierarchical sheet and its
    design rules (.kicad_dru).
    - panel: front-panel artwork project with all branding removed.
    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
    [anthracite-bottom.kicad_pcb, anthracite-bottom.kicad_sch, anthracite-bottom.step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]
2026-09-15 Declare licences of library parts derived from the KiCad libraries
    Six footprints in hardware/*/libs/anthracite.pretty/ are modified copies of
    KiCad standard footprints, and the symbol libraries are built on KiCad
    standard symbols. Redistributing them as a library is not covered by the
    KiCad libraries exception, so they stay under CC-BY-SA-4.0; the exception is
    kept so that anyone can still use them in their own designs.
    - REUSE.toml: declare those files as
    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
2026-09-15 README: describe the repository as it actually is
    - enclosure/: list the STEP model, the drawings and the panel artwork files;
    the Fusion 360 source is marked as planned.
    - firmware/: say that only the build and flashing guide is there so far.
    - docs/: schematics as PDF and PNG, BOM CSVs and board STEP models, instead of
    board renders that do not exist.
    - Release attachments and ordering-notes.md are described as future, since
    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
2026-09-16 Put docs/ under CERN-OHL-S-2.0 and correct the symbol library declaration
    - docs/ holds generated design documents (schematic PDFs and PNGs, bills of
    materials, board STEP), so it carries the hardware licence. README and the
    other text files stay CC-BY-SA-4.0.
    - The symbol libraries mix symbols derived from the KiCad standard libraries
    with symbols drawn for this project (the SS8050 / SS8550 / S9013 family among
    them), so they are declared
    "CERN-OHL-S-2.0 AND CC-BY-SA-4.0 WITH KiCad-libraries-exception".
    reuse lint: 85/85, compliant with REUSE 3.3.
    Claude-Session: https://claude.ai/code/session_01H9QGzk7saaLy5LAwVYL6Ej
2026-09-16 Mark the footswitch board with v1.0 on the silkscreen
    The top and bottom boards already carry "V1.0 CERN-OHL-S-2.0" and the source
    URL; the footswitch board is 14 x 16 mm, so it carries the version only.
    Board STEP and schematic PDF re-exported.
    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
    [anthracite-footswitch.kicad_pcb, anthracite-footswitch.step]
2026-09-23 README: remove the pre-publication TODOs and point at the product page
    Four TODO comments and a "[link to come]" placeholder were left in the file.
    They do not render on GitHub, but they are visible in the raw file, in a
    clone, and to search engines.
    - Pitch: written out, from the framing used on the product page.
    - Photo / OSHWA badge: the photo is in place; drop the OSHWA mention until
    certification is actually granted.
    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
2026-10-07 Release 1.0.0
    Date the 1.0.0 entry in CHANGELOG, and stop saying in the README that no
    release exists: the v1.0.0 release now carries the Gerbers, the JLCPCB BOM
    and CPL for the top and bottom boards, ordering-notes.md and SHA256SUMS.txt.
    The board table gave 35 µm for the four-layer boards without saying which
    layers. The production run was ordered with 1 oz outer and 0.5 oz inner
    copper, so the table now says so.
2026-10-07 README: attach Gerbers only, not assembler files
    A JLCPCB-format BOM and CPL go stale as LCSC stock and part categories
    change, and they duplicate docs/bom-*.csv, which already carries the LCSC
    part numbers. Releases now carry the Gerbers and the ordering notes, and
    the README says where to build assembly files from.
2026-10-09 Add the firmware source
    firmware/ now holds the STM32CubeMX project (anthracite.ioc), the CMake
    build, the application source, and the STM32F0 HAL and CMSIS files from
    STM32Cube FW_F0 V1.11.6. The CMake project name is anthracite, so the
    build produces build/Debug/anthracite.elf.
    This commit rewrites the main.c comments that referred to development
    versions and leaves the code as shipped. The Debug preset with GNU Tools
    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
2026-10-09 Top schematic: fix the footprint name in the embedded NMJ6HCD3 symbol
    The symbol copy stored in the schematic still named
    anthracite:Jack_6.35mm_Neutrik_NMJ6HCD3_Horizontal_PCB, a footprint that
    does not exist. J5, J7 and the board already use
    anthracite:Jack_6.35mm_Neutrik_NMJ6HCD3_Horizontal. The board file stays
    as it was.
    [anthracite-top.kicad_sch]
2026-10-09 Update the documentation for the firmware source and add a parts list
    README: describe firmware/ as it now is, state that the KiCad projects
    need KiCad 10 or later, and name the STEP model and the drawings as the
    reference for the enclosure. The licensing table now lists docs/images/
    and the third-party firmware licences.
    hardware/parts.md lists the parts for each board from the BOMs in docs/.
    COPYRIGHT.txt: the Source Location is on the silkscreen of the top and
    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
2026-10-10 Update the buying section and fix documentation details
    - README: list the extended Bias positions from top to bottom
    (X-Skew / Skew / Offset), matching the firmware.
    - README: Anthracite is on sale; link the product page and say where
    the cost breakdown will appear.
    - COPYRIGHT.txt: state the symbol library licence as REUSE.toml
    declares it (CERN-OHL-S-2.0 AND CC-BY-SA-4.0 WITH
    KiCad-libraries-exception).
    - CONTRIBUTING: firmware changes that alter the flash image go into the
    next firmware version; firmware 1.0.0 stays as shipped.
    - CHANGELOG and firmware/README: wording.
2026-10-11 Split docs/schematics into pdf/ and png/
    The three schematic PDFs move to docs/schematics/pdf/ and the sheet PNGs
    to docs/schematics/png/. Nothing in the tree referenced the old paths;
    REUSE.toml covers docs/** and the KiCad projects have no plot directory
    set. CHANGELOG: note the move under Unreleased.
2026-10-11 Move the bills of materials into docs/bom/
    The four BOM CSVs move to docs/bom/ with their names unchanged.
    README and hardware/parts.md point at the new paths. REUSE.toml covers
    docs/** and the KiCad BOM export filename is relative to each project,
    so neither changes. CHANGELOG: note the move under Unreleased.
2026-11-12 Update the top and bottom boards to v1.1
    Bring in the v1.1 KiCad projects of the top and bottom boards and the
    documents generated from them. The footswitch board and the front panel
    do not change. The main changes:
    Top board:
    - R96 and R97 (100 MΩ) in series with R38 and R86, so the gate resistor
    of each output JFET switch is 200 MΩ (ERRATA M-1).
    - Soft start on the input supply (D30, C51, R95; D3 is now BZT52C13).
    - U4 is now OPA1678IDR, using the KiCad OPA1678 symbol.
    - RV2 and RV3 are 25kB, with R75 to R78 changed to keep the v1.0 tone
    response.
    - J9 senses the supply after the DC jack. J8 and J10 are not fitted;
    J10 is for measurement only.
    Bottom board:
    - MIDI OUT is driven b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
2026-11-12 Correct datasheet links, part descriptions and schematic notes
    Values, footprints and connections do not change.
    - Point the Datasheet fields at documents from the part maker or at the
    datasheets LCSC hosts, and clear the fields that pointed at shop pages
    (Akizuki, JLCPCB, a DigiKey copy). The same values are cleared in
    libs/anthracite.kicad_sym and in the symbol definitions embedded in the
    schematics, and the PCB footprints carry the same field values.
    - Correct the descriptions that did not match the part: U106 is a 64 Kbit
    I2C EEPROM, not an FRAM (description and keywords of its embedded
    symbol as well); U2 runs at 15 MBd with an inverting totem-pole output;
    1N4148WS (JSCJ)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
2026-11-12 Update COPYRIGHT, REUSE.toml, CHANGES and the issue template for v1.1
    - COPYRIGHT.txt lists TRADEMARK and the Japanese documents as text.
    - REUSE.toml declares the Japanese documents and TRADEMARK. It moves
    stm32f0xx_hal_msp.c out of the generated-files table into its own table
    that lists STMicroelectronics and Trope, since 1.1.0 adds the PB6
    pull-up in a USER CODE block. The file keeps BSD-3-Clause. The table
    uses precedence "aggregate", because REUSE detects the ST copyright
    line in the file header. reuse lint: compliant with REUSE 3.3.
    - CHANGES.txt quotes CERN-OHL-S v2 subsection 3.3(b) word for word.
    - The bug report template shows the v1.1 board markings and suggests
    firmwa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
2026-11-12 Add the 1.1.0 changelog entry and the v1.1 errata section
    CHANGELOG.md gets the 1.1.0 entry, dated 2026-11-11, with the hardware,
    firmware and documentation changes. The 1.0.0 silkscreen note drops
    "otherwise identical".
    ERRATA.md notes that v1.1 includes M-1, adds an Anthracite v1.1 section
    with no known errata, and replaces an em dash in the introduction.

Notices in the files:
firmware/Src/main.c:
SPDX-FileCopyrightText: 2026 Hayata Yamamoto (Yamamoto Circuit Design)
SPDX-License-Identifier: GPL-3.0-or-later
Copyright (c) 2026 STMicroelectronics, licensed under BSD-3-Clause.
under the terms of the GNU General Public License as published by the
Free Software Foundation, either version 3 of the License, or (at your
